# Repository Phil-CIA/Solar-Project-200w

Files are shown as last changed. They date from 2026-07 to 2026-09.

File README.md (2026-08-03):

# Solar Project 200W

Solar Project 200W is a prototype-first hardware and firmware effort for a 200W-class solar charging system built around a 4S LiFePO4 battery domain.

## What this repository is for

- Designing and validating a safe MPPT charger path
- Defining control, telemetry, and protection behavior
- Tracking design decisions, handoffs, and bring-up evidence

## Current Rev 0 focus

- Close MPPT schematic and routing readiness
- Maintain component continuity with in-stock substitutions
- Keep protection and validation gates explicit before bring-up

## System baseline

- PV class: 2x100W panel setup
- Battery class: 12.8V LiFePO4 (4S)
- Charge-path target: 15A minimum, 20A preferred growth path

## Project structure

- [docs/](docs/): requirements, architecture, decisions, test plans, phase reviews
- [hardware/](hardware/): KiCad files, MPPT notes, wiring maps, implementation checklists
- [firmware/](firmware/): firmware workspace and bring-up software notes

## Start here

1. [docs/requirements.md](docs/requirements.md)
2. [docs/architecture.md](docs/architecture.md)
3. [docs/decisions-log.md](docs/decisions-log.md)
4. [SOLAR_HANDOFF_2026-07-26.md](SOLAR_HANDOFF_2026-07-26.md)

## Simulation workflow

The PV switch gate-drive concept should be verified with SPICE as part of the normal review loop. The project-local LTspice assets are in [hardware/kicad/solar-project/spice](hardware/kicad/solar-project/spice), including the schematic draft [hardware/kicad/solar-project/spice/pv_switch_gate_drive.asc](hardware/kicad/solar-project/spice/pv_switch_gate_drive.asc) and the launcher [hardware/kicad/solar-project/spice/run_ltspice_pv_gate_drive.cmd](hardware/kicad/solar-project/spice/run_ltspice_pv_gate_drive.cmd).

A provisional LTspice integration harness is also present at [hardware/kicad/solar-project/spice/90_system_integration_harness_ltspice.cir](hardware/kicad/solar-project/spice/90_system_integration_harness_ltspice.cir). It is a simplified, staged model of the PV input, buck power stage, and battery boundary. The current run converged to about 13.64 V at the output node and 13.98 V at the battery bus at 4 ms, which is consistent with a basic charging path but still not hardware-validated.

The earlier validation showed that the current gate-drive arrangement does not provide a usable Vgs margin across the tested PV input range, so this should be treated as a design blocker until the gate-drive topology is revised.

## Safety notice

This project includes high-current DC power electronics and planned AC-domain integration.
Use staged, current-limited bring-up and treat all safety checks as mandatory gates.

## Session continuity

- [HANDOFF.md](HANDOFF.md)
- [NEXT_CHAT_PROMPT.md](NEXT_CHAT_PROMPT.md)

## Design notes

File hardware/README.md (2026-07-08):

# Hardware

Store hardware development assets here.

Suggested structure:
- `schematics/`
- `pcb/`
- `bom/`
- `manufacturing/`
- `validation/`

Add tool/version notes and board revision history as the project evolves.

## Phase 1 Kickoff Artifacts

- `mppt/block-diagram.md`
- `mppt/schematic-exploration-checklist.md`
- `mppt/interface-assumptions.md`
- `mppt/schematic-notes.md`
- `mppt/net-plan.md`
- `mppt/component-shortlist-template.md`
- `mppt/kicad-implementation-checklist.md`
- `mppt/envelope-decision-worksheet.md`
- `mppt/decision-update-template.md`
- `mppt/buck-topology-notes.md`
- `mppt/github-reference-notes.md`
- `mppt/buck-symbol-placement-checklist.md`
- `mppt/pv-input-stage.md`
- `mppt/pv-input-wiring-map.md`
- `mppt/buck-power-stage-wiring-map.md`
- `mppt/sheet2-component-picks.md`

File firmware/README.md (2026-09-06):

# Firmware

Store embedded source, build configuration, and flashing instructions here.

Suggested structure:
- `src/`
- `include/`
- `lib/`
- `scripts/`
- `docs/`

## Rev 0 Safe Bring-Up

- Source: [bringup/stm32g4_rev0_safe_bringup.c](bringup/stm32g4_rev0_safe_bringup.c)
- Bare-metal stage-1 source: [bringup/baremetal/stm32g4_rev0_stage1.c](bringup/baremetal/stm32g4_rev0_stage1.c)
- Bench procedure: [../docs/test/rev0-low-energy-comm-control-test.md](../docs/test/rev0-low-energy-comm-control-test.md)
- Target: recovered Rev 0 board fitted with an STM32G431/STM32G473-class UFQFPN-48 MCU.
- Framework: the active Rev 0 image is freestanding bare-metal firmware for the verified STM32G47x-class target. The separate HAL-oriented source remains a future integration reference.

The bare-metal stage-1 image avoids STM32Cube/HAL dependencies and can be built once GNU Arm Embedded Toolchain is installed:

```powershell
./firmware/bringup/baremetal/build.ps1
```

Stage 1 provides UART diagnostics, safe output state, fault input reads, open-drain software I2C, AHT20 measurements, SSD1306 output, and the D8 RGB heartbeat. Its automatic dashboard shows software wall time, reset-relative uptime, sensor data, and the cached LM51772 `STATUS_BYTE` with a read-failure count (`U6 xx Nnnn`). The U6 status poll is read-only and runs every two seconds while automatic I2C traffic is enabled. ADC remains a placeholder for a later calibrated acquisition pass.

## Rev 0 SWD-Only Checks

The scripts in [scripts/](scripts/) use xPack OpenOCD and ST-LINK to run volatile register checks without flashing firmware:

```powershell
./firmware/scripts/rev0-openocd-identify.ps1
./firmware/scripts/rev0-openocd-safe-idle.ps1
./firmware/scripts/rev0-openocd-i2c-gpio-check.ps1
./firmware/scripts/rev0-openocd-control-gpio-check.ps1
./firmware/scripts/rev0-openocd-run-probe.ps1
./firmware/scripts/windows-list-serial-usb.ps1
```

Run these only with PV, battery, charger output, inverter/AC wiring, and loads disconnected. Run them one at a time because they share the same ST-LINK/SWD target. The control GPIO check briefly toggles `PB5` and `PA5`; it does not pulse `PA8`.

After flashing the bare-metal stage-1 image, `rev0-openocd-run-probe.ps1` starts user flash from the programmed vector table, then reads the SRAM probe block at `0x20000000`. A first word of `0x53523030` and an increasing heartbeat word prove the firmware is executing even if the USB-UART bridge is not enumerating.

Rev 0 normal boot is repaired and verified: the startup vector uses a Thumb reset entry, and option bytes use `nSWBOOT0=0`, `nBOOT0=1` so floating PB8 is not sampled. Cold boot and S1 reset each passed 5/5. Rev 1 still requires a populated 10 kOhm BOOT0 pulldown and accessible test point. The repaired onboard CP2102 is verified on `COM5` at 115200 8N1.

Before any flash/upload, verify the programmer is attached to the expected recovered Rev 0 target and that the detected chip is the expected STM32G4 device. If the target does not match, stop instead of trying a different COM port or probe.

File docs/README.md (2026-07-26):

# Engineering Docs Guide

This folder is the working engineering record for Solar Project 200W.

## Read order for active work

1. [requirements.md](requirements.md)
2. [architecture.md](architecture.md)
3. [decisions-log.md](decisions-log.md)
4. [test/bringup-checklist.md](test/bringup-checklist.md)
5. [test/validation-plan.md](test/validation-plan.md)

## What to update during each session

- Decisions and tradeoffs: [decisions-log.md](decisions-log.md)
- Design state and open blockers: [../hardware/mppt/schematic-notes.md](../hardware/mppt/schematic-notes.md)
- Session continuity and next-step intent: latest handoff at repository root

## Hardware design trail

Use these when working MPPT implementation details:

- [../hardware/mppt/block-diagram.md](../hardware/mppt/block-diagram.md)
- [../hardware/mppt/net-plan.md](../hardware/mppt/net-plan.md)
- [../hardware/mppt/pv-input-wiring-map.md](../hardware/mppt/pv-input-wiring-map.md)
- [../hardware/mppt/buck-power-stage-wiring-map.md](../hardware/mppt/buck-power-stage-wiring-map.md)
- [../hardware/mppt/sheet4-sensing-control-wiring-map.md](../hardware/mppt/sheet4-sensing-control-wiring-map.md)
- [../hardware/mppt/kicad-implementation-checklist.md](../hardware/mppt/kicad-implementation-checklist.md)
- [../hardware/mppt/lm851772-lm51772-migration-checklist.md](../hardware/mppt/lm851772-lm51772-migration-checklist.md)

## Working rules

- Keep assumptions visible and dated.
- Mark unresolved items with owner and target date.
- Do not treat deferred ERC and power-authority findings as closed until explicitly waived.
- Preserve traceability between requirements, decisions, and validation evidence.

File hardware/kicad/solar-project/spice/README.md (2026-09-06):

# SPICE / LTspice workflow

This folder contains a small, project-local validation deck for the PV-input NMOS switch gate-drive network.

## Files
- pv_switch_gate_drive.cir - ngspice-compatible netlist used for operating-point checks
- pv_switch_gate_drive.asc - LTspice schematic draft for the same topology
- run_pv_gate_drive.py - helper to run a few VIN/VCTRL cases with ngspice
- summarize.py - helper to parse outputs and print a compact summary

## Recommended workflow
1. Open pv_switch_gate_drive.asc in LTspice and run the operating-point analysis.
2. Repeat for the relevant VIN and control states (12 V / 24 V / 36 V / 50 V, OFF versus ON).
3. Record the resulting Vgs margin in the design review notes.

## Current outcome
The earlier validation showed that the current gate-drive arrangement does not provide a usable Vgs margin across the tested VIN range. That result should be treated as a design blocker until the gate-drive topology is revised.

## Current harness baseline
The staged LTspice integration harness in [90_system_integration_harness_ltspice.cir](90_system_integration_harness_ltspice.cir) now produces a stable, charging-like baseline for the simplified B0/B1/B2 path. From the latest completed run, the model reported approximately 15.17 V at the output node, 12.46 V at the battery bus, and about 12 A of charge current at 4 ms in the simulator’s sign convention. This is suitable for concept-level sanity checking, but it is still not hardware-validated.

The latest block values were also aligned to the current KiCad schematic intent: B0 uses the PV fuse/TVS clamp path around F1, D1, and D2; B1 uses the selected 1uH power-stage inductor and a bulk output-capacitance branch with extra series-loss elements to reflect conduction and heating-related loss; and B2 uses a more conservative battery-side fuse and pack boundary model.

Compared with the project requirement target in [docs/requirements.md](docs/requirements.md), the current result lands near the expected 12 A to 13 A charging band for the 200W-class baseline and is therefore directionally consistent with the intended charger envelope. It is still a simplified model and should not be treated as a final design proof.

## Validation summary
The latest run gives a stable charging-like operating point at 4 ms with VOUT ≈ 15.17 V, BAT_BUS ≈ 12.46 V, and ICHG ≈ 12 A (negative sign in LTspice due to current direction convention). That corresponds to roughly $15.17 \times 12 \approx 182\ \text{W}$ of delivered charge power, which is still within the 180 W to 220 W design envelope in [docs/requirements.md](docs/requirements.md). The run remained stable across the leakage-corner sweep from 600 Ω to 1000 Ω, and the added hot-loss terms now pull the output and battery bus downward in a way that is more consistent with real power-stage losses. The result is still useful for checking topology and schematic mapping, but it should remain an engineering sanity check rather than a validated design value.

Design-review statement: the current LTspice harness supports the view that the proposed MPPT charger concept is feasible for the documented 200 W-class charging envelope, with the caveat that the model is still a simplified abstraction and requires later hardware validation.

## New modular schematic-to-SPICE flow

The full schematic partition for block-based SPICE modeling is documented in `SCHEMATIC_SPICE_PARTITION.md`.

Starter block decks were added:

- `00_block_b0_pv_input.cir`
- `01_block_b1_power_stage.cir`
- `02_block_b2_battery_boundary.cir`
- `03_block_b3_control_rail.cir`
- `04_block_b4_fault_network.cir`
- `05_block_b5_measurement_frontend.cir`
- `90_system_integration_harness.cir`

Recommended sequence:

1. Make each block deck runnable on its own.
2. Replace placeholders with real values/models from the KiCad schematic.
3. Integrate blocks progressively in `90_system_integration_harness.cir`.

## Automated corner runs

Use the PowerShell runner to execute key decks and produce a compact CSV summary:

- Script: `run_spice_corner_sweeps.ps1`
- Summary output: `corner_summary.csv`
- Per-deck logs: `logs/*.log`
- Waveform CSV exports: `waveforms/*.csv`
- Plot dashboard: `plots/index.html`

Summary columns now include:

- `status` pass/fail classification from simulator/log health checks
- `vout_avg`, `iin_avg` from direct deck measurements when available
- `iout_avg`, `pin_avg`, `pout_avg`, `eff_pct` for B1, derived from measured values and deck params when needed
- `req_chg_001`, `req_chg_003` requirement-oriented status fields for B1:
	- `req_chg_001`: pass/fail against 15A minimum target
	- `req_chg_003`: pass/fail against 12A to 13A expected baseline band
- `bat_trip`, `ocp_trip` from B4 threshold sweeps
- `notes` with per-deck log path and optional warnings

Current warning tags appended in `notes`:

- `iin_avg_negative`: B1 input current sign is negative in this operating convention
- `pin_avg<=0`, `pout_avg<=0`: non-physical average power direction/magnitude
- `eff_pct_out_of_range`: computed efficiency is outside 0 to 100%
- `measure_failed`: ngspice reported one or more measurement failures in the deck log

Example from this folder:

```powershell
powershell -ExecutionPolicy Bypass -File .\run_spice_corner_sweeps.ps1
```

Run with warning gate enabled (nonzero exit if selected warnings are present):

```powershell
powershell -ExecutionPolicy Bypass -File .\run_spice_corner_sweeps.ps1 -FailOnWarnings $true
```

Generate plots only from existing waveform CSV files:

```powershell
powershell -ExecutionPolicy Bypass -File .\generate_spice_plots.ps1
```

Current runner deck set:

- `00_block_b0_pv_input.cir`
- `01_block_b1_power_stage.cir`
- `02_block_b2_battery_boundary.cir`
- `04_block_b4_fault_network.cir`
- `90_system_integration_harness.cir`

`04_block_b4_fault_network.cir` now reports measured threshold points as `BAT_TRIP` and `OCP_TRIP` in the run log, and the runner parses those into the summary CSV when available.

## Startup-current experiment

`03_startup_current_limit.cir` is a separate behavioral transient deck for the Rev 0 bring-up question: can a nominal 6 V source with an approximately 200 mA current ceiling build current in the 1 uH inductor during a soft-start duty ramp? It uses a 610 kHz switching period, a configurable soft-start interval, the 1 kOhm preload, and a 30 ohm source resistance as a first-order approximation of the bench supply current limit.

This deck is not an LM51772 vendor model and does not prove the controller's exact soft-start or current-limit behavior. Its useful outputs are `IIN_PEAK`, `IIN_AVG`, `IL_PEAK`, `IL_AVG`, and `VOUT_FINAL`. Vary `TSS`, `DUTY_END`, `LVAL`, and `RSOURCE` one at a time when comparing the model to the bench capture.

Run it from this directory with:

```powershell
ngspice -b -o logs/03_startup_current_limit.log 03_startup_current_limit.cir
```

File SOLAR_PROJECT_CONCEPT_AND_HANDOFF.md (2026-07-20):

# Solar Learning Project — Concept Capture + Handoff (Rev 0)

## Session Update - 2026-07-06

Completed since initial concept capture:

1. New repository initialized and pushed:
  - `https://github.com/Phil-CIA/Solar-Project-200w`
2. Base project scaffold created:
  - `README.md`
  - `.gitignore`
  - `docs/README.md`
  - `hardware/README.md`
  - `firmware/README.md`
3. Active KiCad project imported from the historical source at:
  - `C:/Users/forch/GitHub/Solar Project`
4. Current authoritative KiCad source location in this repo:
  - `hardware/kicad/solar-project/`
  - `hardware/kicad/solar-project/Solar Project.kicad_pro`
  - `hardware/kicad/solar-project/Solar Project.kicad_sch`
  - `hardware/kicad/solar-project/Solar Project.kicad_pcb`
5. To open the live schematic in KiCad, use:
  - `hardware/kicad/solar-project/Solar Project.kicad_sch`
5. Transient KiCad artifacts were intentionally excluded from source control.

Current continuation focus:
- Keep the KiCad work anchored to the repository copy above.
- Continue the schematic validation pass and refresh docs only when the exported state changes.
- Use the next few sessions to decide which legacy single-MOSFET-era functions still belong in hardware, which ones are firmware-only, and which ones can be removed now that LM51772 is the active controller path.

## Cleanup Plan For The Next Few Sessions

### Session 1 - Function Inventory And Ownership

Goal:
- Make a complete list of the leftover control, enable, fault, and legacy hold nets around U2/U6/Q2.

Questions to answer:
- Does the function still need to exist?
- If yes, is the right owner hardware, firmware, or both?
- If firmware is involved, is it just supervision/telemetry, or does it need to make a safety decision?

Decision rule:
- Hardware owns anything that must still work safely when the MCU is not running.
- Firmware owns only coordination, reporting, and non-safety policy.
- Remove any net or block that only existed to support the earlier single-MOSFET concept and no longer contributes to the LM51772 architecture.

### Session 2 - Schematic Cleanup

Goal:
- Remove or repurpose the nets that were only there for the older control concept.

Expected outcomes:
- Keep `CTRL_PWM_MAIN` and `CTRL_EN_CHG` if the MCU still needs to command the controller.
- Keep `FAULT_OCP` and `FAULT_OVP` as hardware-first safety indications, then mirror them in firmware only for logging or graceful shutdown.
- Remove or freeze any legacy `V_in_ON` / Q2-style path if it no longer has a real job.
- Finish the U6 helper-net cleanup only if those nets still represent real hardware needs.

### Session 3 - Verification And Simplification

Goal:
- Re-run ERC, compare the exported netlist against the intended function list, and delete any remaining scaffolding that does not support the current architecture.

Exit criteria:
- Every remaining net has a clear owner.
- No net exists solely because it was part of the old single-MOSFET concept.
- The docs say explicitly whether the function lives in hardware, firmware, or not at all.

### Session 4 - Sheet 2 And Legacy Output Cleanup

Goal:
- Clean the power-stage side first, because it is the simplest place to separate active function from old scaffolding.

Targets:
- Confirm `CTRL_PWM_MAIN` is the only needed drive input for the buck stage.
- Keep the async first-pass path in Sheet 2 and avoid reintroducing the old Q2-style control gate path.
- Remove any stale labels that only existed to support the earlier MOSFET-only control idea.

Expected result:
- Sheet 2 reflects the modern LM51772-driven control path without leftover naming from the first concept pass.

### Session 5 - Control And Fault Path Cleanup

Goal:
- Decide what the MCU actually owns versus what the hardware must enforce by itself.

Targets:
- Keep `CTRL_EN_CHG` if the MCU still needs an enable line.
- Keep `FAULT_OCP` and `FAULT_OVP` as hardware signals, then mirror them in firmware only if useful.
- Review `V_in_ON` and the `U2/Q2` legacy branch and either retire it or explicitly document why it stays.

Expected result:
- The control/fault sheet reads like a modern supervisor interface, not a half-retained legacy gate hack.

### Session 6 - U6 Helper Nets And Final ERC Pass

Goal:
- Finish the LM51772 helper nets only if they still support the selected architecture.

Targets:
- Close `U6_VCC2` and `U6_FLT` with real passives if U6 remains active.
- Keep `U6_SYNC`, `U6_DTRK`, and `U6_RST` only if they are still intentional straps.
- Re-run ERC/netlist export and compare the result against the classified backlog.

Expected result:
- Any net that survived this pass has a real hardware reason to exist.
- Any net that does not have a reason is removed rather than preserved out of habit.

### First-Pass Function Classification

Use this as the working backlog for the next sessions. The final answer can change, but each item needs an owner decision.

| Item | Current best guess | Why |
|---|---|---|
| `CTRL_PWM_MAIN` | Hardware stays, firmware drives it | The MCU should still command the converter, but the PWM signal itself is a hardware interface. |
| `CTRL_EN_CHG` | Hardware stays, firmware drives it | Enable/disable needs to exist in the schematic; firmware may assert it. |
| `FAULT_OCP` | Hardware stays, firmware monitors it | Over-current must remain a real protection signal even if firmware also logs or reacts to it. |
| `FAULT_OVP` | Hardware stays, firmware monitors it | Same logic as OCP: keep the hardware fault path, let firmware supervise the result. |
| `V_in_ON` | Likely delete or retire | It still belongs to the legacy Q2 gate path and only stays if that path is intentionally retained. |
| `U2` as control-rail owner | Delete or deprecate | Current docs already select U4 as the live `CTRL_3V3` owner. |
| `U6_VCC2` | Hardware stays if U6 stays | Needs a real decoupling path if the LM51772 gate-driver rail remains active. |
| `U6_FLT` | Hardware stays if U6 stays | Fault output needs a pull-up and a destination pin; firmware can only observe it after hardware exists. |
| `U6_RST` | Hardware stays if used | Reset is a real pin-level strap or control input, not a firmware-only concept. |
| `U6_SYNC` | Hardware stays if used | Sync/strap behavior is a physical configuration choice. |
| `U6_DTRK` | Hardware stays if used | Dynamic tracking is a physical pin-level mode decision. |

### Session Sequence By Owner Type

1. Hardware-only cleanup session:
- Finish `U6_VCC2`, `U6_FLT`, and any strap nets that still need real passives.
- Remove obsolete U2 owner wiring if it is no longer part of the chosen control tree.
- Delete `V_in_ON` if the Q2 legacy control path is not intentionally kept.

2. Firmware interface session:
- Map `CTRL_PWM_MAIN`, `CTRL_EN_CHG`, `FAULT_OCP`, and `FAULT_OVP` to the MCU behavior that should remain.
- Decide whether firmware only logs faults or also performs controlled shutdown / restart policy.
- Keep the firmware model as a supervisor, not the safety owner, unless a specific hardware path is missing and documented.

3. Final simplification session:
- Remove any leftover symbols, labels, or note text that only describe the old single-MOSFET concept.
- Re-run ERC and compare the live schematic against this table.
- Update decisions log only for items that truly changed ownership or function.

## 1) Project Intent
This project is a **learning-first** build, not a cost-optimization build.  
Goal: understand and eventually design at PCB level:

1. Solar power capture (panel behavior, Vmp/Voc/Imp/Isc)
2. MPPT charging into LiFePO4 battery
3. DC energy storage/distribution
4. DC-to-AC inversion for common loads
5. System telemetry, protection, and safe bring-up

---

## 2) Selected System Concept (Current Baseline)
- Solar array: **200W total** (2 × 100W panels)
- Battery: **12.8V 40Ah LiFePO4** (4S)
- Charger path target: **15A minimum, 20A preferred**
- Inverter target: **300W pure sine**

This is the current concept baseline for initial architecture and documentation.

---

## 3) Key Learning Definitions Captured
- **Vmp (Vmpp):** voltage at maximum power point
- **Imp (Impp):** current at maximum power point
- **Voc:** open-circuit panel voltage
- **Isc:** short-circuit panel current
- **MPPT:** Maximum Power Point Tracking (operate panel near max power point as conditions change)

---

## 4) High-Level Architecture
1. PV input stage (protection + filtering)
2. MPPT charger stage (buck or buck-boost path)
3. Battery stage (LiFePO4 + BMS + fuse/disconnect)
4. DC distribution stage
5. Inverter stage (12V DC to 120VAC pure sine)
6. Monitoring/telemetry/control stage

---

## 5) Sizing Notes Captured
### Charge current from solar estimate
Use:
- I_charge ≈ (P_solar × efficiency) / V_charge
- For 4S LiFePO4, practical shortcut: **I_charge ≈ P_solar × 0.063**

For 200W:
- I_charge ≈ 12–13A expected peak
- Therefore charger should be **15A+** (20A preferred for margin/growth)

### Controller class implication
- 5A-class charger is too limiting for 200W
- 15A–20A-class charger aligns with chosen system

---

## 6) Safety & Design Priorities
- Fuse near battery positive terminal
- Branch fusing for subsystems
- Proper wire gauge for expected current
- UVLO/OVP/OCP/OTP protections
- Reverse polarity and transient protection on PV input
- Treat inverter output as hazardous mains-level AC
- Use staged bring-up and current-limited bench testing

---

## 7) Scope Strategy (One Piece at a Time)
### Phase A (current focus)
- Concept documentation
- Project structure setup
- MPPT charger design exploration (block level first)

### Phase B
- MPPT schematic development
- Simulation/math validation
- Firmware architecture for charge control + telemetry

### Phase C
- Inverter design exploration and implementation

---

## 8) Open Design Decisions (To Resolve in Next Sessions)
1. MPPT topology final: buck vs buck-boost
2. Controller approach:
   - analog power controller + MCU supervision
   - or highly integrated digital charger controller
3. Panel wiring strategy for final build: parallel vs series
4. Telemetry stack:
   - local display only
   - serial logging
   - CAN/UART/BLE/Wi-Fi extension
5. Battery current limits from selected BMS/cell data sheet

---

## 9) Deliverables Requested for Next Chat (VS Code Agent)
1. Create project folder structure (docs, calculations, hardware, firmware, test)
2. Create starter markdown docs/templates
3. Add engineering checklist files for:
   - requirements
   - design decisions
   - safety
   - bring-up/testing
4. Add initial calculator placeholders (markdown or scripts) for:
   - solar-to-charge current
   - fuse sizing worksheet
   - inverter input current estimation

---

## 10) Initial Folder Structure Target
```text
solar-learning-project/
  README.md
  docs/
    concept/
      system-overview.md
      requirements.md
      assumptions.md
      decisions-log.md
    handoff/
      next-chat-handoff.md
    safety/
      hazard-analysis.md
      protection-checklist.md
    test/
      bringup-checklist.md
      validation-plan.md
  calculations/
    charger/
      charge-current-sizing.md
      mppt-sizing-notes.md
    inverter/
      dc-input-current-sizing.md
  hardware/
    mppt/
      block-diagram.md
      schematic-notes.md
      bom-placeholder.csv
    inverter/
      block-diagram.md
      schematic-notes.md
      bom-placeholder.csv
  firmware/
    mppt/
      state-machine.md
      telemetry-signals.md
    inverter/
      control-architecture.md
  project-management/
    roadmap.md
    milestones.md
```

---

## 11) Definition of Done for “Project Setup” Task
- Folder tree created
- All listed starter docs created with section headers
- README links to major docs
- Handoff doc for next technical session completed
- No hardware commits yet; documentation scaffold only

---

## 12) Notes
This is a concept-building phase.  
Proceed incrementally, prioritizing understanding, safety, and reproducible documentation.

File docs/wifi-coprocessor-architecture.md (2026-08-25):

# Wi-Fi Coprocessor Architecture

Last updated: 2026-08-08  
Status: Accepted Rev 1 baseline  
Decision: DEC-015

## System Boundary

The STM32 is the charge-controller and safety owner. The ESP32-C3 development module is a network coprocessor. A Wi-Fi outage, ESP32 reset, or communications failure must not interrupt safe charger operation.

### STM32 Owns

- MPPT and charge-state control
- PWM and power-stage enable control
- Measurements, limits, and fault handling
- Fan, buttons, display, and local operation
- Validation and execution of all remote requests

### ESP32 Owns

- Wi-Fi provisioning and reconnection
- Credential storage in ESP32 NVS
- Network time synchronization
- MQTT or HTTPS connectivity
- Telemetry publication and remote-request forwarding
- OTA updates for ESP32 firmware

STM32 firmware updates remain through SWD for the initial implementation. ESP32-assisted STM32 updates are deferred until the communications protocol is proven.

## Hardware Interface

- Power the ESP32 development module through its `5V` pin from `CTRL_5V`.
- Leave the module's exposed `3.3V` pin unpowered; the module uses its onboard regulator.
- Use common `PWR_NEG` reference.
- Use UART `TXD_ESP` and `RXD_ESP` for the data channel.
- Keep `RTS_ESP` and `CTS_ESP` routed as optional hardware flow control.
- Initial UART rate: 115200 baud; raise only after validation.
- Preserve the module antenna keepout in PCB placement and copper pours.

## UART Protocol Baseline

Use binary, versioned, framed messages rather than an unframed text stream:

`COBS(version | message_type | sequence | payload_length | payload | CRC16)`

Initial message set:

- `PROTOCOL_INFO`: protocol and firmware versions
- `HEARTBEAT`: link health
- `STATUS`: controller state, active faults, and uptime
- `TELEMETRY`: PV, battery, power, and temperature values
- `GET_CONFIG`: read approved controller settings
- `SET_CONFIG`: request approved setting changes
- `COMMAND`: request start, stop, or permitted fault clear

The STM32 validates every setting and command against local safety limits. Missing ESP32 heartbeats do not change charger operation. Missing STM32 heartbeats cause the ESP32 to report the controller offline.

## Wi-Fi and Remote Access

1. On first boot or explicit credential reset, the ESP32 starts a temporary setup access point.
2. A local setup page collects the network SSID and password.
3. Credentials are stored in ESP32 NVS.
4. The setup access point is disabled during normal operation.
5. Telemetry is published periodically; faults are published immediately.
6. Remote control requires authenticated, encrypted transport before it is enabled.

MQTT is the preferred first remote telemetry transport. Topic naming, payload schema, authentication, and broker selection remain firmware-session tasks.

## Failure Rules

- Charger safety does not depend on the ESP32 or network.
- ESP32 commands are requests, not direct actuator control.
- Invalid, stale, duplicate, or out-of-range requests are rejected by the STM32.
- Protocol versions are exchanged before commands are accepted.
- ESP32 reset and update activity must not toggle charge-control nets.

## Deferred Details

- MQTT broker and topic hierarchy
- Telemetry sampling and publication rates
- Authentication and certificate provisioning
- Whether RTS/CTS is enabled after initial UART testing
- Host-controlled ESP32 reset or boot-mode control
- STM32 firmware delivery through the ESP32

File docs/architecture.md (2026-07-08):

# Solar Project 200W - Architecture

Last updated: 2026-07-06
Scope: Phase 0 block-level architecture for planning and traceability.
Related documents: [requirements.md](requirements.md), [decisions-log.md](decisions-log.md)

## 1. Architecture Intent

Define subsystem boundaries and interfaces early so requirement allocation, safety controls, and deferred decisions remain explicit while implementation stays agile.

## 2. Block-Level System View

1. PV input stage
2. MPPT charger stage
3. Battery and protection stage
4. DC distribution stage
5. Inverter stage
6. Monitoring/telemetry/control stage

Power path overview:
- PV source -> PV protection/filtering -> MPPT charger -> battery bus -> DC distribution -> inverter/load path.

Control and telemetry overview:
- Sensing at PV, charger, battery, and thermal nodes.
- Local serial telemetry baseline for bring-up (DEC-006).
- Optional extended telemetry deferred.

## 3. Subsystem Boundaries and Responsibilities

### 3.1 PV Input Stage

Responsibilities:
- Accept 200W-class PV source and condition entry to charger stage.
- Provide reverse polarity and transient protection at boundary.

Boundary assumptions:
- Final panel wiring strategy (series vs parallel) is deferred (DEC-004).
- Input voltage/current envelope will be finalized when panel model is locked.

Requirement mapping:
- REQ-PV-001, REQ-PV-002, REQ-SAF-004.

### 3.2 MPPT Charger Stage

Responsibilities:
- Convert PV input to battery charging profile with MPPT behavior.
- Support 15A minimum charge capability; 20A class preferred where practical.

Boundary assumptions:
- Topology decision (buck vs buck-boost) deferred (DEC-003).
- Controller partition (analog + MCU vs integrated controller) deferred (DEC-005).

Requirement mapping:
- REQ-CHG-001, REQ-CHG-002, REQ-CHG-003, REQ-SAF-003.

### 3.3 Battery and Protection Stage

Responsibilities:
- Host 12.8V LiFePO4 storage domain with BMS-constrained operating envelope.
- Provide primary battery fuse near battery positive terminal.

Boundary assumptions:
- Continuous/peak BMS limits pending closure of Q-001.

Requirement mapping:
- REQ-BAT-001, REQ-BAT-002, REQ-SAF-001.

### 3.4 DC Distribution Stage

Responsibilities:
- Route battery-domain power to charger auxiliaries, control domain, and inverter input.
- Apply branch protection strategy for major current paths.

Boundary assumptions:
- Final branch current ratings depend on BMS limits and inverter transients.

Requirement mapping:
- REQ-SAF-002, REQ-SAF-003.

### 3.5 Inverter Stage

Responsibilities:
- Convert battery-domain DC to 120VAC pure sine output in 300W-class envelope.
- Define AC hazard boundary and integration controls.

Boundary assumptions:
- Inverter internal topology is outside Phase 0 and will be detailed in later phases.

Requirement mapping:
- REQ-INV-001, REQ-INV-002, REQ-SAF-005.

### 3.6 Monitoring, Telemetry, and Control Stage

Responsibilities:
- Measure key electrical and thermal signals for safe control and diagnostics.
- Provide local serial logging baseline for bring-up.

Boundary assumptions:
- Extended telemetry interfaces are deferred and non-blocking for initial bring-up.

Requirement mapping:
- REQ-TEL-001, REQ-TEL-002, REQ-TEL-003, REQ-SAF-006.

## 4. Protection Strategy Outline

Minimum strategy for Phase 0 architecture allocation:
- Battery entry protection: main fuse close to battery positive.
- Path protection: branch fusing for charger and inverter paths.
- Electrical protections: UVLO, OVP, OCP, OTP assigned to charger/control stack.
- PV front-end: reverse polarity and transient mitigation.
- AC boundary discipline: hazardous domain handling and test controls for inverter output.

## 5. Power and Signal Interface Summary

| Interface | Domain | Direction | Key Signals / Constraints | Notes |
|---|---|---|---|---|
| IF-PV-CHG-01 | PV -> Charger | Power | PV voltage/current envelope, transient behavior | Depends on DEC-004 |
| IF-CHG-BAT-01 | Charger -> Battery | Power | Charge current capability, charge profile limits | Depends on DEC-003/DEC-005 |
| IF-BAT-DIST-01 | Battery -> Distribution | Power | Main fuse boundary, branch protection | Depends on Q-001 |
| IF-DIST-INV-01 | Distribution -> Inverter | Power | High current DC feed, startup current behavior | Inverter phase detail later |
| IF-SENSE-CTRL-01 | Plant -> Control | Telemetry | PV V/I, battery V/I, thermal channels | Baseline for REQ-TEL-002 |
| IF-CTRL-LOG-01 | Control -> Host | Telemetry | Local serial logs for bring-up and diagnostics | Defined by DEC-006 |

## 6. Deferred Architectural Decisions

- DEC-003: MPPT topology final selection.
- DEC-004: Panel wiring strategy final selection.
- DEC-005: Charger control partition final selection.
- Q-001: Confirm BMS current envelope.
- Q-002: Confirm instrumentation capability for validation depth.

## 7. Phase 0 Architecture Exit Criteria

- All major subsystem boundaries are documented with responsibilities.
- Requirement mappings are established at subsystem level.
- Safety and protection controls are allocated at planning level.
- Deferred decisions are explicit and linked to owners/target dates in decisions log.

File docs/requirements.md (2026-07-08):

# Solar Project 200W - Requirements

Last updated: 2026-07-06
Scope: Phase 0 planning baseline for 200W-class learning system.
Traceability: Link each requirement to architecture sections and decisions in [decisions-log.md](decisions-log.md).

## 1. Requirement Method

Each requirement includes:
- ID: stable reference for design and test traceability.
- Metric and target: measurable engineering expectation.
- Verification: planned pass/fail method.
- Source: concept baseline or decision reference.

## 2. System Baseline

- PV input class: 200W nominal array (2x100W modules).
- Battery class: 12.8V LiFePO4 (4S), 40Ah nominal.
- Charge path target: 15A minimum, 20A preferred capability class.
- Inverter envelope: 300W pure sine target.

## 3. Electrical Requirements

| ID | Requirement | Target / Limit | Verification Method | Source |
|---|---|---|---|---|
| REQ-PV-001 | System shall support a PV nameplate power class of 200W. | 180W to 220W accepted design envelope. | Nameplate review + input power budget check. | Concept baseline |
| REQ-PV-002 | PV operating window shall include module maximum power region during normal conditions. | PV MPP tracking region shall be documented and covered by charger input range. | Architecture and charger input-range review against selected panel datasheets. | Concept + DEC-003/DEC-004 |
| REQ-CHG-001 | Charger architecture shall target 15A minimum continuous charge capability. | >=15A continuous design target at rated thermal conditions. | Schematic current-path review + component derating worksheet. | Concept baseline |
| REQ-CHG-002 | Charger solution should preserve growth margin toward 20A class when feasible. | 20A preferred target documented as stretch objective. | Design review note with constraints and tradeoffs. | Concept baseline |
| REQ-CHG-003 | Estimated peak solar charge current expectation shall be documented. | For 200W baseline, expected peak approximately 12A to 13A. | Calculation using I_charge ~= (P_solar * eta) / V_charge with assumptions recorded. | Concept sizing note |
| REQ-BAT-001 | Battery nominal chemistry and stack shall remain LiFePO4 4S for Phase 0/1 planning. | 12.8V nominal, 40Ah class. | BOM and requirements consistency check. | Concept baseline |
| REQ-BAT-002 | Battery charge/discharge operational limits shall be constrained by selected BMS datasheet. | Continuous and peak current limits explicitly captured before hardware lock. | Datasheet extraction checklist (open item closure). | Decisions Q-001 |
| REQ-INV-001 | Inverter power envelope shall target 300W continuous output class. | 300W continuous target at defined ambient and cooling assumptions. | Architecture power budget and thermal assumption review. | Concept baseline |
| REQ-INV-002 | Inverter input current expectation shall be documented for 300W target operation. | I_in estimate and design margin documented at battery voltage range. | Calculation worksheet with efficiency assumption. | Concept baseline |

## 4. Telemetry and Control Requirements

| ID | Requirement | Target / Limit | Verification Method | Source |
|---|---|---|---|---|
| REQ-TEL-001 | Initial telemetry baseline shall support local serial logging for bring-up. | UART/serial logging path defined for charger and battery observability. | Architecture interface review + firmware signal list placeholder. | DEC-006 |
| REQ-TEL-002 | Core electrical observability shall include panel, battery, and thermal signals. | At minimum: PV voltage/current, battery voltage/current, key temperature points. | Signal map review against architecture boundary definitions. | Concept + DEC-007 |
| REQ-TEL-003 | Telemetry extension shall be designed as optional and non-blocking for first bring-up. | Wireless or extended interfaces deferred without blocking core path. | Decisions-log review of deferred scope. | DEC-006 |

## 5. Safety and Protection Requirements

| ID | Requirement | Target / Limit | Verification Method | Source |
|---|---|---|---|---|
| REQ-SAF-001 | Main battery positive protection shall include a fuse located near battery terminal. | Fuse placement documented at battery positive entry point. | Architecture placement review. | Concept safety priorities |
| REQ-SAF-002 | Subsystem branch protection shall be included for major load paths. | Branch fusing strategy documented for charger and inverter paths. | Protection strategy checklist review. | Concept safety priorities |
| REQ-SAF-003 | Charger and distribution design shall include UVLO/OVP/OCP/OTP coverage. | Protection functions explicitly allocated to circuits or controller features. | Protection allocation table review. | Concept + DEC-007 |
| REQ-SAF-004 | PV input path shall include reverse polarity and transient protection strategy. | Reverse polarity and surge/transient mitigation documented at PV boundary. | Interface/protection schematic review (planning-level in Phase 0). | Concept + DEC-007 |
| REQ-SAF-005 | AC inverter output shall be treated as hazardous mains-level domain. | Isolation, enclosure, and handling warnings documented before integration testing. | Safety checklist review prior to integration phase. | Concept safety priorities |
| REQ-SAF-006 | Bring-up shall be staged with current-limited progression and logged checkpoints. | Stepwise current progression and stop criteria defined before hardware bring-up. | Bring-up procedure review against decisions log. | DEC-008 |

## 6. Validation Gate Requirements

| ID | Requirement | Target / Limit | Verification Method | Source |
|---|---|---|---|---|
| REQ-VAL-001 | Every requirement shall map to a planned verification activity. | No requirement left without a verification method. | Traceability matrix review. | Planning policy |
| REQ-VAL-002 | Deferred decisions affecting requirements shall include owner and target date. | 100% of deferred, requirement-impacting decisions have owner/date. | Decisions-log audit. | DEC-001 policy |
| REQ-VAL-003 | Phase transition to implementation shall require requirements and architecture review pass. | Review checklist completed with no unresolved safety blockers. | Phase gate checklist sign-off (Phil + Copilot). | DEC-002 |

## 7. Open Items Blocking Requirement Closure

- Confirm battery/BMS continuous and peak current limits (Q-001).
- Confirm available test instrumentation capability (Q-002).
- Finalize PV wiring strategy and MPPT topology coupling (DEC-003, DEC-004).

## 8. Definition of Done (Phase 0 Requirements)

- Requirement IDs are stable and uniquely named.
- Every requirement includes measurable target/limit and verification method.
- Safety-critical controls are represented in explicit requirements.
- Open blockers are listed with decision-log references and target dates.

## 9. Compact Traceability Matrix

| Requirement ID | Architecture Boundary / Interface | Decision / Open Item Link |
|---|---|---|
| REQ-PV-001 | 3.1 PV Input Stage | DEC-004 |
| REQ-PV-002 | 3.1 PV Input Stage, IF-PV-CHG-01 | DEC-003, DEC-004 |
| REQ-CHG-001 | 3.2 MPPT Charger Stage, IF-CHG-BAT-01 | DEC-003 |
| REQ-CHG-002 | 3.2 MPPT Charger Stage, IF-CHG-BAT-01 | DEC-003, DEC-005 |
| REQ-CHG-003 | 3.2 MPPT Charger Stage | DEC-003 |
| REQ-BAT-001 | 3.3 Battery and Protection Stage, IF-BAT-DIST-01 | Q-001 |
| REQ-BAT-002 | 3.3 Battery and Protection Stage, IF-BAT-DIST-01 | Q-001 |
| REQ-INV-001 | 3.5 Inverter Stage, IF-DIST-INV-01 | DEC-002 |
| REQ-INV-002 | 3.5 Inverter Stage, IF-DIST-INV-01 | Q-001 |
| REQ-TEL-001 | 3.6 Monitoring/Telemetry/Control, IF-CTRL-LOG-01 | DEC-006 |
| REQ-TEL-002 | 3.6 Monitoring/Telemetry/Control, IF-SENSE-CTRL-01 | DEC-007 |
| REQ-TEL-003 | 3.6 Monitoring/Telemetry/Control | DEC-006 |
| REQ-SAF-001 | 3.3 Battery and Protection Stage | DEC-007 |
| REQ-SAF-002 | 3.4 DC Distribution Stage | DEC-007 |
| REQ-SAF-003 | 3.2 MPPT Charger Stage, 3.4 DC Distribution Stage | DEC-007 |
| REQ-SAF-004 | 3.1 PV Input Stage | DEC-007 |
| REQ-SAF-005 | 3.5 Inverter Stage | DEC-007 |
| REQ-SAF-006 | 3.6 Monitoring/Telemetry/Control | DEC-008 |
| REQ-VAL-001 | 7. Phase 0 Architecture Exit Criteria | DEC-001 |
| REQ-VAL-002 | 6. Deferred Architectural Decisions | DEC-001 |
| REQ-VAL-003 | 7. Phase 0 Architecture Exit Criteria | DEC-002 |

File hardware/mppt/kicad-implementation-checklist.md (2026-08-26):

# MPPT KiCad Implementation Checklist

Last updated: 2026-08-26
Owners: Phil + Copilot
Purpose: provide a repeatable sequence for building the first MPPT schematic safely and traceably.

## 1. Session Start Gate

- [ ] Open and review hardware/mppt/block-diagram.md.
- [ ] Open and review hardware/mppt/schematic-notes.md.
- [ ] Open and review hardware/mppt/buck-schematic-parts.md.
- [ ] Open and review hardware/mppt/net-plan.md.
- [ ] Open and review hardware/mppt/stm32-support-implementation-checklist.md.
- [ ] Open and review docs/session-plan-2026-07-20.md.
- [ ] Confirm current temporary bounds and open items in docs/phase-1-kickoff.md.
- [ ] Confirm decision status for DEC-003 and DEC-005 in docs/decisions-log.md.

## 2. Draw Order (Per Session)

1. Draw PV boundary and protection blocks first.
2. Draw MPPT conversion core and output boundary second.
3. Draw battery interface and fuse handoff notes third.
4. Draw sensing and telemetry I/O paths last.

Rule:
- Do not start symbol-level optimization before all four areas are present at block connectivity level.

## 3. Annotation Pass

- [ ] Add ASSUME notes for temporary bounds.
- [ ] Add DECISION notes for unresolved decisions (DEC-003, DEC-005).
- [ ] Add SAFETY notes at PV protection, conversion protection, and battery handoff boundaries.
- [ ] Add VERIFY notes for each measurement-critical node.

## 4. Net Naming Pass

- [ ] Apply power net names from net-plan.md.
- [ ] Apply sensing and control net names from net-plan.md.
- [ ] Verify no duplicate or ambiguous names on critical nets.
- [ ] If a new net is introduced, add it to net-plan.md the same session.

## 5. Verification Pass Before Save

- [ ] Each high-current path has explicit forward and return path.
- [ ] UVLO/OVP/OCP/OTP ownership is represented in notes or blocks.
- [ ] PV reverse polarity and transient handling are present.
- [ ] Buck-specific parts are represented: switch, freewheel path, inductor, output capacitors, control placeholder.
- [ ] Required sense points exist: PV V/I, BAT V/I, thermal points.
- [ ] Serial logging boundary exists for bring-up telemetry.
- [ ] Control-power boundary is explicit (`CTRL_SUPPLY_IN`, `CTRL_3V3`, optional `CTRL_3V3A`) and tied to DEC-013 intent.
- [ ] USB bench fallback path is protected against reverse current when runtime rail is active.
- [ ] Any intentionally unused pins touched in this pass are marked with explicit `no_connect` markers.
- [ ] New active rails introduced in this pass include explicit power authority markers (power flag or clear power-output ownership).

## 5.1 ERC Triage Rule During Implementation

- [ ] Fix high-value ERC findings immediately: `multiple_net_names`, unconnected wire endpoints in active zones, and missing ownership on fault/control nets.
- [ ] Defer low-value cleanup findings (footprint library noise, placeholder warnings) to end-of-phase cleanup unless they hide functional risk.
- [ ] Record deferred ERC items with rationale in `hardware/mppt/schematic-notes.md`.

## 6. Save-Point Protocol

At each save-point:
- [ ] Add a short note in hardware/mppt/schematic-notes.md describing what changed.
- [ ] If assumptions changed, update hardware/mppt/interface-assumptions.md.
- [ ] If trade-offs were made, add a dated entry or update in docs/decisions-log.md.

## 7. End-of-Session Exit Gate

- [ ] Unresolved blockers are listed with owner and next target date.
- [ ] Current schematic state is compatible with REQ-CHG-001/002/003 and REQ-SAF-003/004 intent.
- [ ] No hidden safety-critical assumptions remain unannotated.
- [ ] Next session first action is captured at bottom of this file.

## 7.1 STM32 Support Components Gate

Close this gate before board-placement freeze:

- [ ] External reset path is complete: `MCU_RST_N` pull-up, reset switch to `PWR_NEG`, and header/debug access retained.
- [ ] External HSE crystal path is complete: crystal on `MCU_HSE_IN`/`MCU_HSE_OUT` with two load capacitors to `PWR_NEG` placed close to MCU.
- [ ] SWD bring-up access is complete and labeled (`PA13`, `PA14`, reset).
- [ ] BOOT path behavior is explicitly documented (`PB8-BOOT0` default state and recovery method).
- [ ] Navigation pad is complete and documented: `BTN_UP_N`, `BTN_DN_N`, `BTN_LT_N`, `BTN_RT_N`, `BTN_ENT_N`.

## 7.2 Part Substitution Gate (Mandatory)

Run this gate whenever a component is swapped for a different part number, including in-stock continuity swaps within the same family and package.

Rule: **the same package never implies the same pinout.** Editing the `Value`, `MP`, or datasheet fields does not change the pin mapping used for routing.

- [ ] Replace the schematic **symbol** itself, not just the text fields. Confirm the symbol `lib_id` matches the part actually being fitted.
- [ ] Verify the new symbol's pin map against the manufacturer datasheet or a trusted library (for example KiCad's official `MCU_ST_*` symbols), pin number by pin number.
- [ ] Explicitly re-check every power and boot pin: `VDD`, `VSS`, `VDDA`, `VSSA`, `VREF`, `VBAT`, `VCAP`, `BOOT0`, `BOOT1`, and the exposed pad.
- [ ] Confirm no supply net lands on a ground pin and no ground net lands on a supply pin. This is the failure mode that produced the DEC-018 Rev 0 board loss.
- [ ] Re-check required support passives for the new part (for example `VCAP` stabilization capacitors) and add them if the previous part did not need them.
- [ ] Re-check debug and programming pins (`SWDIO`, `SWCLK`, reset) against the new pinout.
- [ ] Re-export the netlist and run ERC after the symbol swap; do not rely on the pre-swap netlist.
- [ ] Record the substitution and the completed pin-map verification in `docs/decisions-log.md`.

Stop condition:
- The fitted part's datasheet pinout and the routed netlist agree on every power, ground, boot, and debug pin.

## 8. Pre-PCB Routing Gate

- [ ] Rev 0 reverse-polarity path is fixed to series Schottky and reflected in symbols/footprints.
- [ ] Rev 0 Sheet 2 freewheel path is asynchronous and reflected in symbols/notes.
- [ ] Any ideal-diode or synchronous upgrade is captured as Rev 1 backlog in docs/decisions-log.md.
- [ ] DEC-013 startup behavior is validated: PV-only startup and USB-only startup both pass with no unintended backfeed.
- [ ] Full ERC rabbit-hole pass is completed: all remaining findings are either fixed or explicitly waived with rationale.
- [ ] If any part was substituted since the last routing pass, the Section 7.2 Part Substitution Gate is closed.

## 8.1 ERC Clearance Routing Gate (Mandatory)

Treat ERC closure as the formal gate to start board routing.

- [ ] Latest exported `hardware/kicad/solar-project/ERC.rpt` shows **0 unwaived errors**.
- [ ] Any accepted residual ERC finding has an explicit waiver note in `hardware/mppt/schematic-notes.md` with: message class, location/symbol, why electrical intent is acceptable, and owner/date.
- [ ] No unresolved ERC finding remains in a safety-critical path (power authority, protection trip path, gate-drive path, or MCU fault landing path).
- [ ] If a finding is waived due to symbol semantics only (not wiring/electrical behavior), keep the existing electrical connection and document the rationale instead of forcing risky library-pin edits.

Routing start rule:
- Do not begin PCB routing until all four checks above are true.

## 9. Pre-Rev 1 Planning Gate

- [ ] Revisit DEC-012 and Q-003 with measured Rev 0 thermal and efficiency data.
- [ ] Define migration impact for ideal-diode input path (symbols, footprints, routing).
- [ ] Define migration impact for synchronous power stage and gate-driver architecture.

## 10. Next Session First Action

Fill this line before ending each session:
- Next action: **Classify the legacy function backlog**. Review `CTRL_PWM_MAIN`, `CTRL_EN_CHG`, `FAULT_OCP`, `FAULT_OVP`, `V_in_ON`, and the U2/U6 helper nets, then decide which ones stay in hardware, which ones are firmware-only, and which ones are deleted.

## 11. 2026-07-20 Execution Block

Use this block for the current cleanup sequence until the legacy backlog is cleared.

### 11.1 Session 1 - Sheet 2 Cleanup

- [ ] Review `hardware/mppt/buck-power-stage-wiring-map.md`.
- [ ] Confirm `CTRL_PWM_MAIN` is the only controller-drive input still needed on Sheet 2.
- [ ] Keep the asynchronous Rev 0 freewheel path.
- [ ] Remove any stale labels or notes that only supported the older MOSFET-only concept.

Stop condition:
- Sheet 2 no longer implies a legacy control path competing with the LM51772 path.

### 11.2 Session 2 - Control And Fault Ownership

- [ ] Review `hardware/mppt/sheet4-sensing-control-wiring-map.md` and `hardware/mppt/net-plan.md`.
- [ ] Review the default ownership matrix in `docs/session-plan-2026-07-20.md`.
- [ ] Record the likely outcome for each item before editing anything.
- [ ] Keep `CTRL_EN_CHG` unless the schematic proves the MCU no longer needs it.
- [ ] Keep `FAULT_OCP` and `FAULT_OVP` as hardware protection signals.
- [ ] Delete `V_in_ON` unless the legacy `U2/Q2` branch is intentionally retained.
- [ ] Mark the `U2/Q2` branch as legacy or delete it if it no longer serves a real control purpose.

Stop condition:
- Every control/fault net has a clear owner and the old prototype glue is no longer ambiguous.

### 11.3 Session 3 - U6 Helper Nets And ERC

- [ ] Review `hardware/mppt/lm851772-lm51772-migration-checklist.md`.
- [ ] Confirm whether U6 is still active before editing any helper nets.
- [ ] Keep `U6_VCC2` and `U6_FLT` active, and close them with real passives if U6 is still active.
- [ ] Keep `U6_SYNC`, `U6_DTRK`, and `U6_RST` only if they still serve an intentional strap role.
- [ ] Re-export ERC and netlist after the cleanup pass.
- [ ] Record the updated state in `hardware/mppt/schematic-notes.md`.

Stop condition:
- Any surviving helper net has a documented hardware reason to exist.

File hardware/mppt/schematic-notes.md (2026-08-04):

# MPPT Schematic Notes (First Pass)

Last updated: 2026-08-04
Owners: Phil + Copilot
Status: CTRL_SUPPLY_IN OR-ing complete; U6 (LM51772) all critical strap connections verified; 7 deferred power-authority ERC errors only.

## Rev One kickoff linkage update (2026-08-04)

- Active schematic lineage is now treated as Rev 1 for ongoing board work.
- Recovered Rev 0 baseline files are in the KiCad project folder for side-by-side comparison during Rev 1 deltas.
- Rev One delta plan and commit split are tracked in docs/rev-one-delta-plan-2026-08-04.md.
- Rev One ERC/DRC release gate checklist is tracked in docs/test/rev-one-erc-drc-closure-checklist.md.

Approved wiring-map references for Rev One pass:

- hardware/mppt/pv-input-wiring-map.md
- hardware/mppt/buck-power-stage-wiring-map.md
- hardware/mppt/sheet3-battery-interface-wiring-map.md
- hardware/mppt/sheet4-sensing-control-wiring-map.md

## Rev 0 MCU continuity update (2026-07-26)

- Preferred replacement: `STM32F411CEU6` for Rev 0 continuity. This keeps the existing UFQFPN-48 footprint class and preserves the current MCU net map for SWD, UART, I2C, fault inputs, and button lines.
- Immediate backup: `STM32F401CEU6`.
- Risk note: this change accepts a firmware migration from the G4 family to the F4 family while avoiding a package-class change and board reroute.

## BOM Review Snapshot (2026-07-25)

This review is based on the live KiCad schematic/netlist, not a separate export BOM file.

### Acceptable For Rev 0

- U4 LM5163 control rail path: acceptable for the documented control-supply architecture.
- U6 LM51772 controller block: acceptable as the active charger controller, pending the existing helper-net and ERC cleanup policy.
- D4/D6/D7 1N5819WS OR-ing diodes: acceptable for the protected control-supply boundary.
- D2 SMBJ60CA TVS: acceptable for the PV boundary protection intent.

### Acceptable With Caveat

- M1/M2/M3/M4 IPZ40N04S5L4R8ATMA1: the 40 V MOSFETs are acceptable under the 25.6 V TI Vds estimate and the U2 overvoltage shutdown assumption. Keep the transient and layout review intact, but do not force a 60 V-class swap just for margin.
- L2 (HC3-1R0-R, 1uH) in the MPPT switch path has verified high current capability (about 78 A Irms / 78 A Isat from Eaton product data), so current rating is not the blocker; remaining work is value/ripple and control-loop tuning confirmation.

### Not Acceptable Yet

- F1 now uses a holder-matched placeholder (`Fuse_TD_10A_5x25_63VDC_MIN`): footprint is present, but the exact fuse part is not locked. Active rule is holder-first: choose a 5x25 fuse element with >=63 VDC rating to match the installed holder footprint.
- Bussmann MDL preference is parked for this revision because the active holder is 5x25.

### Legacy / Not Part Of The Charger BOM Decision

- D1 1SMA4742A is part of the legacy U2 control path, not the PV boundary, so it should not be judged as the PV reverse-polarity element.
- L3 is part of the control-rail path and is not the main Sheet 2 MPPT energy-storage inductor target.

### Follow-Up Needed

1. Keep the 40 V MOSFET set unless a later transient or thermal review shows a real need to change it.
2. Confirm the 1uH inductor value against ripple/control-loop targets and adjust value only if control or thermal data requires it.
3. Lock the exact 5x25 fuse part number after confirming >=63 VDC rating and time-delay behavior against startup/inrush.
4. Keep the control-rail parts as-is unless a later review shows an electrical or thermal reason to revise them.

---

## Session 2026-07-19 Summary (Continuation)

**Primary Outcomes:**
- ✅ CTRL_SUPPLY_IN net fully wired with three OR-ing Schottky diode sources:
  - D4: BAT_BUS_POS → CTRL_SUPPLY_IN (pre-existing)
  - D6: CHG_OUT_POS → CTRL_SUPPLY_IN (NEW - 1N5819WS at 298.45, 182.88, 90°)
  - D7: VBUS → CTRL_SUPPLY_IN (NEW - 1N5819WS at 298.45, 177.80, 90°)
- ✅ Netlist confirms all 4 nodes present in CTRL_SUPPLY_IN net (C15, D4, D6, D7, R13, U4)
- ✅ ERC: 7 errors / 56 warnings (all 7 errors are deferred power-authority semantics)
- ✅ Commit 7a78756: clean state with CTRL_SUPPLY_IN fully operational

**Pending (Deferred to Component Placement):**
- ⏳ C30: 100 nF VCC2 decoupling cap (U6 pin 29 → PGND) — needs manual placement + wiring in KiCad GUI
- ⏳ R34: 10 kΩ FLT pull-up resistor (U6 pin 11 → CTRL_3V3) — needs manual placement + wiring in KiCad GUI

**Technical Notes:**
- U6_VCC2 net exists (code 78) but is dangling (only U6 pin 29). Decap addition pending actual board layout.
- U6_FLT net exists (code 77) but is dangling (only U6 pin 11). Pull-up addition pending actual board layout.
- Both components deferred because manual symbol insertion ran into KiCad net-matching complexity (components auto-connected to wrong signal nets during GUI placement). Easier path: add via component layer during footprint placement phase.
- Architecture decision rationale retained: DEC-013 mandates wide-input U4 buck fed from three OR-ed sources for maximum Rev 0 flexibility (PV-first, battery fallback, USB bench debug).

---

## 1. Scope

This file defines how to partition the first buck MPPT schematic draft so safety, sensing, and power paths are explicit before component lock.

## 2. Zone Partition Plan (Single Sheet)

Recommended functional zoning within one KiCad schematic page:

1. Zone A - PV Input and Protection
- PV connector and polarity marking: 2-position pluggable terminal block
- Reverse polarity strategy: series Schottky diode for first pass
- Transient/surge suppression: 64 V TVS diode
- Input filter boundary: 63 V capacitor bank close to connector and diode

Symbol order:
1. J1 connector
2. F1 fuse
3. D1 series Schottky diode
4. D2 TVS diode
5. C1/C2/C3 input capacitors

2. Zone B - MPPT Power Stage
- High-side buck switch stage
- Inductor energy-storage path
- Freewheel diode or synchronous low-side path
- Output filter boundary

3. Zone C - Battery Interface and Protection Handoff
- Charger output boundary
- Battery connector boundary
- Main fuse handoff note
- Current-limit envelope note tied to Q-001/DEC-011

4. Zone D - Sensing and Control I/O
- PV voltage/current sensing points
- Battery voltage/current sensing points
- Thermal sensing points
- Serial telemetry signal breakout baseline

## 3. Net Class and Naming Plan

Use stable, purpose-based net names from the first draft:

Power domain nets:
- PV_IN_POS
- PWR_NEG
- MPPT_SW_NODE
- CHG_OUT_POS
- BAT_BUS_POS

Sense nets:
- SENSE_PV_V
- SENSE_PV_I
- SENSE_BAT_V
- SENSE_BAT_I
- SENSE_TEMP_PWR
- SENSE_TEMP_BOARD

Control and logging nets:
- CTRL_PWM_MAIN
- CTRL_EN_CHG
- FAULT_OCP
- FAULT_OVP
- UART_TX_LOG
- UART_RX_CFG

## 4. Schematic Annotation Rules

- Tag all temporary assumptions with "ASSUME:" prefix.
- Tag unresolved decisions with "DECISION:" plus ID (DEC-003, DEC-005).
- Tag safety ownership points with "SAFETY:".
- Tag verification-critical nodes with "VERIFY:".

## 5. Minimum Notes Required On First Draft

- Input electrical envelope note (or temporary bound reference).
- Output current planning bound (15A temporary cap if Q-001 still open).
- Protection ownership allocation note (UVLO/OVP/OCP/OTP).
- Weak-sun / low-headroom behavior note for buck feasibility review.
- Thermal observation points note.
- Bring-up caution note referencing staged current-limited process.

## 6. Draft Review Checklist

- [ ] Every high-current path has explicit current direction and return path.
- [ ] Every protection function has an owner block.
- [ ] Every sensing function has a named node and destination.
- [ ] Temporary assumptions are visible and linked to decision IDs.
- [ ] Buck-specific power path parts are present or explicitly blocked with notes.
- [ ] Net names are consistent with net-plan.md.

## 7. Exit Criteria

- First partitioned schematic draft exists in KiCad.
- Critical nets and notes are present and named consistently.
- Deferred buck-implementation decisions are visible as annotations, not hidden assumptions.

## 8. Save-Point Log

- 2026-07-08: KiCad project source-path consolidation executed.
- Authoritative path is now `hardware/kicad/solar-project/` inside this repository.
- External duplicate at `C:/Users/forch/GitHub/Solar Project` was verified hash-identical for `.kicad_sch`, `.kicad_pcb`, and `.kicad_pro` before cleanup.
- Netlist policy locked to generated-only; `*.net` added to repository ignore rules.
- 2026-07-08: Netlist regenerated from repository schematic and ERC run captured in `hardware/kicad/solar-project/ERC.rpt`.
- Current ERC snapshot: 1 error (`Q1` gate input not driven on `CTRL_PWM_MAIN`) and 7 warnings (shared-net naming, local/global duplicate labels, and placeholder/invalid footprints for C4/C6/C7).
- Next cleanup focus: resolve naming at shared return rail and assign valid capacitor footprints before pre-routing gate.
- 2026-07-08: Sheet 3 kickoff unblocked for boundary-level work; first-pass battery interface map added at `hardware/mppt/sheet3-battery-interface-wiring-map.md`.
- Sheet 3 scope for next pass: place battery connector and main-fuse boundary with `CHG_OUT_POS/NEG` to `BAT_BUS_POS/NEG` handoff while keeping Q-001-dependent ratings provisional.
- 2026-07-08: Sheet 3 boundary implementation completed in the single-sheet schematic using zone rectangles and global net naming.
- Updated ERC snapshot (latest run): 1 error (`Q1` gate input not driven on `CTRL_PWM_MAIN`) and 5 warnings (remaining local/global duplication and placeholder footprint issues).
- Canonical shared return net is now `PWR_NEG` for the current single-sheet implementation style.
- 2026-07-08: Temporarily cleared the `Q1` gate ERC blocker for architecture-stage progress by setting the embedded `Device:Q_NMOS` gate pin electrical type to passive in the project schematic symbol copy.
- 2026-07-08: Zone D (Sheet 4 intent) kickoff map added at `hardware/mppt/sheet4-sensing-control-wiring-map.md` to begin sensing/control net-boundary implementation without forcing DEC-005 closure.
- 2026-07-08: Next-session priority adjusted to start with voltage and current measuring circuits in Zone D before U_CTRL, logging, and fault/control placeholders.
- 2026-07-09: **Zone D (Sheet 4) Phase 1 implementation COMPLETE** — All measurement circuits, thermal placeholders, logging header, and U_CTRL connector placed. All 16 canonical nets from net-plan.md present as global labels. ERC run with no errors (acceptable warnings for placeholder nets). Ready for full schematic validation and Rev 0 bring-up planning.
- 2026-07-10: Requirements-to-schematic validation sweep executed against REQ-CHG-001/002/003 and REQ-SAF-003/004 intent plus telemetry coverage. Latest ERC report shows 0 errors and 10 warnings; two `multiple_net_names` warnings indicate current-sense net collisions that must be corrected before pre-routing gate.
- 2026-07-10: Rev 0 component shortlist captured in `hardware/mppt/rev0-component-shortlist-2026-07-10.md` with rating-margin basis and sourcing-risk labels for Q1, D3, L1, C4-C7, divider paths, and PV protection path parts.
- 2026-07-14: Schematic implementation pass started for DEC-013 and pre-routing blockers. In `Solar Project.kicad_sch`, removed direct wire ties between charge/battery rails and sense-current nets at the two flagged collision points, removed lower standalone `FAULT_OCP/FAULT_OVP` label placeholders, and renamed the existing `+3,3V` global label to `CTRL_3V3`.
- 2026-07-14: ERC must be re-run in KiCad to confirm warning deltas after this edit pass before updating blocker status to closed.
- 2026-07-14: Reviewed ERC snapshot (`ERC.rpt` timestamp 03:14 local). Previous sense-net collision errors are no longer present in the report. Remaining dominant errors are unconnected STM32 pins and unpowered MCU power pins (`VBAT`, `VDD`, `VDDA`, `VREF+`, `VSS`) plus auxiliary unconnected pins on U2/U4 and D5/D6.
- 2026-07-14: Applied second cleanup pass in schematic: added intentional `no_connect` markers for currently unused MCU and auxiliary pins, added MCU-side `CTRL_3V3` labels to power pins, added MCU-side `PWR_NEG` label to `VSS`, and normalized fault-net label casing to uppercase (`FAULT_OCP` / `FAULT_OVP`).
- 2026-07-14: Another ERC run is required to quantify new message count and close/update blocker status with evidence.
- 2026-07-14: ERC re-run captured (`ERC.rpt` 09:51 local): 6 errors / 14 warnings. Sense-net collision findings remain cleared. Remaining errors are concentrated in power-drive checks (`U1: VBAT/VSS`, `U2: VIN`, `U4: VIN/GND`) plus one unhandled MCU GPIO (`PB15`).
- 2026-07-14: Targeted high-value ERC pass applied in schematic: added `no_connect` on remaining unhandled MCU pin (`PB15`), added explicit `CTRL_3V3` label on MCU `VBAT`, and tied exploratory U4 supply nets into canonical rails (`CHG_OUT_POS`, `PWR_NEG`) with explicit net labels. Also set one canonical source-side labels as output authority (`CHG_OUT_POS`, `PWR_NEG`) per flag-as-you-go policy.
- 2026-07-14: ERC re-run captured (`ERC.rpt` 10:12 local): 4 errors / 15 warnings. `PB15` and `U4 GND` errors are cleared; remaining high-value errors are all `power_pin_not_driven` checks on `U1 VBAT`, `U1 VSS`, `U2 VIN`, and `U4 VIN`.
- 2026-07-14: Final high-value ERC pass applied for power-authority semantics: added `power:PWR_FLAG` symbols on `CTRL_3V3`, `PWR_NEG`, and `CHG_OUT_POS` active rails to satisfy remaining `power_pin_not_driven` checks without forcing topology rework. One fresh ERC run is required to confirm closure.
- 2026-07-14: Rolled back the manual `power:PWR_FLAG` symbol-instance experiment after KiCad/ERC instability was reported. Working hypothesis: the hand-edited flag instances were not safe in the current schematic file form. Reverted to the last stable schematic state and deferred the remaining `power_pin_not_driven` findings to the explicit end-of-phase ERC cleanup path.
- 2026-07-14: ERC workflow policy aligned for Phase 1: fix high-value wiring/signal integrity findings immediately, add `no_connect` and power-authority flags as symbols/rails are added, and defer low-value library/placeholder noise to an explicit end-of-phase rabbit-hole cleanup pass.
- 2026-07-14: Stable post-rollback ERC snapshot captured (`ERC.rpt` 10:37 local): 4 errors / 14 warnings. KiCad runs ERC normally again. The remaining 4 errors are all `power_pin_not_driven` semantics on `U1 VBAT`, `U1 VSS`, `U2 VIN`, and `U4 VIN`; these are explicitly deferred under the current Phase 1 ERC policy, not treated as current wiring blockers.
- 2026-07-14: DEC-013 control-supply boundary implementation started in schematic. Reused the existing diode fan-in ahead of U2 as the first-pass source-priority scaffold: top branch remains `CHG_OUT_POS`, one spare branch is now `USB_5V_IN`, one spare branch is now `BAT_BUS_POS`, and the shared post-diode feed into the control regulators is now labeled `CTRL_SUPPLY_IN`. U4 VIN was also relabeled from `CHG_OUT_POS` to `CTRL_SUPPLY_IN` so both control-supply regulator candidates reference the same boundary net.
- 2026-07-19: LM51772 migration cleanup pass started for critical miswire isolation. Normalized split-risk labels in schematic (`UART_RX_CFG ` -> `UART_RX_CFG`, `V_in _ADC` -> `V_in_ADC`) to remove accidental net-name variants before rewiring.
- 2026-07-19: Applied conservative detachment edits for known-bad U6 ties in `Solar Project.kicad_sch`: removed direct wire ties at U6-side connection points for prior `VCC2`/`SYNC`/`DTRK` miswire paths and introduced temporary explicit nets (`U6_VCC2`, `U6_SYNC`, `U6_DTRK`, `U6_RST`) at U6 pin-side labels pending final destination-net decisions.
- 2026-07-19: ERC/netlist regeneration is pending manual KiCad run (CLI unavailable in current shell). Next required verification is a fresh `ERC.rpt` and `Solar Project.net` export to confirm each U6 pin moved off prior wrong rails and to quantify new hard-error deltas.
- 2026-07-19: Applied Rev 0 strap decisions for detached U6 pins: SYNC→PWR_NEG (free-running internal oscillator), DTRK→PWR_NEG (dynamic tracking disabled), RST→CTRL_3V3 (pulled high for normal operation, MCU can override). VCC2 remains as placeholder net `U6_VCC2` pending decoupling cap addition. FLT remains as `U6_FLT` pending pull-up resistor addition.
- 2026-07-19: VIN/BIAS strategy decided for Rev 0: both U6 pin 36 (VIN) and pin 40 (BIAS) tied to PV_IN_POS. This is intentional for Rev 0 simplicity — not a wiring error. BIAS tied to VIN results in slightly higher IC quiescent dissipation vs tying BIAS to VCC2 (internal 5V), which is the recommended upgrade for Rev 1 or once VCC2 decoupling is placed. Residual `power_pin_not_driven` errors on VIN/BIAS/PGND are power-authority semantics deferred to end-of-phase ERC cleanup.
- 2026-07-19: Fixed gate-drive `pin_not_driven` ERC errors for M1–M4 (gates not driven). Root cause: U6 HO1/LO1/HO2/LO2 gate-driver output pins were typed `unspecified` in the embedded lib_symbols. Changed all four to `output` type — the correct semantic for gate driver outputs. This eliminates four hard errors (M1 G, M2 G, M3 G, M4 G).
- 2026-07-19: Fixed R32 Pin 2 `pin_not_connected` error. R32 is the ILIMCOMP_ISET current-limit setpoint resistor; pin 2 was floating after the prior FLT miswire cleanup removed its accidental net connection. Added `PWR_NEG` global label at (93.98, 219.71) to correctly ground pin 2 through the existing wire stub. This eliminates the `pin_not_connected` and `unconnected_wire_endpoint` pair for R32.
- 2026-07-19: ERC verification complete. Final count: **7 errors / 54 warnings** (down from 14 errors at start of session). All 7 remaining errors are explicitly deferred power-authority semantics: U6 VIN, U6 PGND, U1 VBAT, U4 VIN (power_pin_not_driven without PWR_FLAG), and D3 pins 2/4/6 (USB ESD diode pin-type mismatch from library symbol). Also noted: `lib_symbol_mismatch` warning for U6 LM51772QRHARQ1 because the embedded symbol pin types were updated in-schematic and now differ from the library copy — intentional, accept for this revision.
- 2026-07-19: Wired CTRL_SUPPLY_IN (DEC-013 gap). U4 VIN net was previously an unnamed auto-net (Net-(U4-VIN)) with only a single BAT_BUS_POS Schottky (D4). Added: D6 (CHG_OUT_POS → CTRL_SUPPLY_IN, 1N5819WS) at (298.45, 182.88), D7 (USB_5V_IN → CTRL_SUPPLY_IN, 1N5819WS) at (298.45, 177.80), connecting wires, and CTRL_SUPPLY_IN global label at (320.04, 187.96). CTRL_SUPPLY_IN now has three OR-ing source paths: BAT_BUS_POS via D4, CHG_OUT_POS via D6, USB_5V_IN via D7. ERC/netlist re-run required to confirm net name propagation.
- 2026-07-19: Applied MCU-facing canonical net cleanup in the schematic. Renamed `V_in_ADC` to `SENSE_PV_V`, `V_out _on` to `CTRL_PWM_MAIN`, bridge-side `TXD` to `UART_TX_LOG`, and USB bench-power boundary labels `VBUS` to `USB_5V_IN`. Deliberately left `V_in_ON` unchanged because it still terminates on the legacy U2/Q2 control path and cannot be safely mapped to a canonical measurement or control net without a separate functional decision.
- 2026-07-19 (continuation): Verification pass indicates generated artifacts are still stale relative to the latest schematic edits (`Solar Project.kicad_sch` is newer than both `Solar Project.net` and `ERC.rpt`). Do not treat exported net names or ERC counts as current until a fresh KiCad re-export is run.
- 2026-07-19 (continuation, later): Fresh KiCad exports were generated (`Solar Project.net` 10:23 local, `ERC.rpt` 10:24 local). Task-A closure is still OPEN in these fresh artifacts: `U6_VCC2` and `U6_FLT` remain dangling, `R34` is still absent, and existing `C30` is still the 47uF output capacitor reference. ERC also now includes additional U7 (AHT20) unconnected-pin errors that were not part of the prior 7-error baseline.
- 2026-07-19 (continuation): Task-A objective (U6 helper-net closure) is not yet confirmed in exported data. In current exports, `U6_VCC2` and `U6_FLT` remain single-node dangling nets and no `R34` component is present. Also, existing `C30` is still the 47uF output capacitor designator, so any new VCC2 decoupler should use a different reference if added.
- 2026-07-19 (continuation): `V_in_ON` role is now functionally classified as control-only (U1 PA5 through R41 into the Q2 gate network) and not a measurement/ADC net. Keep net name in legacy-hold state until U2/Q2 retention/removal is decided.
- 2026-07-19 (continuation): Migration worksheet progress advanced: Sections 4.2, 4.3, and 4.4 in `hardware/mppt/lm851772-lm51772-migration-checklist.md` now contain Rev 0 starting targets and explicit PASS/OPEN status fields for UVLO, soft-start, and compensation.
- 2026-07-20: Cleanup strategy refocus. Next sessions will classify each leftover legacy function as hardware-owned, firmware-owned, or removable. The practical rule is: safety-critical behavior stays in hardware, firmware handles supervision/reporting, and old single-MOSFET-era scaffolding is deleted unless it still serves a real LM51772-era function.
- 2026-07-20: Cleanup sequencing sharpened. Sheet 2 power-stage cleanup comes first, then control/fault ownership review, then LM51772 helper-net completion and ERC/netlist confirmation. `V_in_ON` and the U2/Q2 branch are the main delete candidates if they do not survive the control-path review.
- 2026-07-20: Default cleanup outcome set for the legacy backlog: keep `CTRL_PWM_MAIN`, `CTRL_EN_CHG`, `FAULT_OCP`, and `FAULT_OVP` as hardware signals with firmware mirroring where useful; delete `V_in_ON` unless the Q2 legacy branch is intentionally retained; treat U2 control-owner role as delete/deprecate; keep `U6_VCC2`, `U6_FLT`, and U6 strap nets only if U6 remains an active block.
- 2026-07-20: Sheet 2 cleanup started. `CTRL_PWM_MAIN` is now recorded as the only live controller-drive input for Q1 in Rev 0; old MOSFET-era alternate gate-drive wording is being removed from the Sheet 2 docs rather than preserved.
- 2026-07-20: Session 2 defaults recorded. `CTRL_EN_CHG` stays unless the schematic proves it is unused; `FAULT_OCP` and `FAULT_OVP` stay as hardware protection signals; `V_in_ON` and the `U2/Q2` branch default to delete/legacy unless intentionally retained.
- 2026-07-20: Session 3 defaults recorded. U6 is still treated as active in the current notes, so `U6_VCC2` should be closed with a real decoupler and `U6_FLT` should be closed with a pull-up; `U6_SYNC`, `U6_DTRK`, and `U6_RST` remain keep-only-if-intentional straps.
- 2026-07-20: U6 helper-net verification completed against the live schematic. `R34` is already present at the FLT path, the VCC2 helper rail is already represented by the existing local decoupling capacitor, and the latest on-disk ERC artifact (`hardware/kicad/solar-project/ERC.rpt`, 2026-07-20 export) reports 4 errors / 9 warnings overall; no additional helper-net-specific hard errors were introduced in this pass.
- 2026-07-20: Current-measurement roles clarified and simplified from the live schematic/netlist. `R16` remains the active 4-terminal 1 mOhm controller shunt tied to `ISNSP`/`ISNSN`. The separate `R20` 10 mOhm battery/output-path shunt and its placeholder labels `BAT_I_POS` / `BAT_I_NEG` were intentionally removed after deciding Rev 0 does not need a second output-current measurement path.
- 2026-07-21: Protection-block readiness check completed against the current on-disk netlist (`hardware/kicad/solar-project/Solar Project.net`). `FAULT_OCP` and `FAULT_OVP` are present as comparator output nets but still do not land on STM32 pins yet; `PB0` and `PB1` remain explicit unconnected nets in the export. `U6_FLT` is present as its own net and remains separate from comparator-fault nets, which is acceptable for Rev 0 diagnostics.
- 2026-07-21: OCP/OVP implementation targets for next schematic pass are now explicit. OCP path currently has placeholder divider parts (`R49`, `R50`) between `OCP_MEAS` and `OCP_SENSE`; preferred Rev 0 action is direct compare (`OCP_MEAS` to comparator input) unless a deliberate filter is added. OVP path still has placeholder divider parts (`R20`, `R47`) while `OVP_REF` is active from `R21=102k` and `R48=10k` (about 0.295 V from `CTRL_3V3`), so the battery-trip threshold cannot be trusted until `R20`/`R47` are assigned intentional values.
- 2026-07-21: First focused schematic action remains: wire `FAULT_OCP -> PB0` and `FAULT_OVP -> PB1`, then re-export ERC/netlist and confirm those pins are no longer in unconnected nets before changing threshold component values.
- 2026-07-21 (verification): Closed. Fresh netlist export timestamp `2026-07-21T03:24:15-0500` shows `FAULT_OCP` contains U1 `PB0` and `FAULT_OVP` contains U1 `PB1`; corresponding unconnected PB0/PB1 nets are no longer present. ERC remained stable at 4 errors / 9 warnings with no new hard findings from this fault-landing change.
- 2026-07-21 (larger bite, verification): Fresh exports show OVP divider values are now intentional (`R20 = 499k`, `R47 = 10k`) and fault-net landings remain correct (`FAULT_OCP -> PB0`, `FAULT_OVP -> PB1`). ERC improved slightly to **4 errors / 8 warnings** (12 total messages) with no new hard-error classes.
- 2026-07-21 (larger bite, remaining item): OCP path is partially simplified but not fully closed. `R49` is now `0 ohm` between `OCP_MEAS` and `OCP_SENSE`, but `R50` is still populated at `10k` and still ties `OCP_SENSE` toward return. Next pass should either mark `R50` as DNI/open (preferred for direct-compare intent) or replace with an explicitly designed filter network.
- 2026-07-21 (power-authority bite, verification): Fresh ERC export (`2026-07-21T04:03:28-0500`) dropped the hard-error set from 4 to 1 and warnings from 8 to 5. Cleared classes include prior `U4 VIN` and `D3` power-authority findings. Remaining hard error is one `pin_to_pin` conflict: `U6` pin 29 (`VCC2`, output) tied to power flag `#FLG06`.
- 2026-07-21 (next hard-error target): Remove the power-output authority marker from the `U6_VCC2` helper net (`#FLG06`) rather than changing `U6 VCC2` functional wiring. Re-run ERC to confirm 0 hard errors before touching any additional warning cleanup.
- 2026-07-21 (policy): ERC clearance is now a mandatory gate before PCB routing starts. The routing gate requires 0 unwaived ERC errors in the latest exported report; any accepted residual finding must be explicitly waived in this file with class, location, rationale, and owner/date.
- 2026-07-21 (post-ERC sequence lock): With hard-error reduction complete enough for this pass, next work follows the handoff ownership branch rather than additional warning cleanup.
- 2026-07-21 (ownership decision block): `V_in_ON` is treated as legacy control glue and defaults to delete unless the U2/Q2 branch is explicitly retained for a documented hardware reason. `U2/Q2` legacy control-owner role defaults to deprecate/remove in favor of the active Rev 0 control path.
- 2026-07-21 (protection behavior block): Keep `FAULT_OCP`, `FAULT_OVP`, and `U6_FLT` as distinct diagnosis/status nets. Next design decision is whether to add a hardware shutdown-OR path (example net: `CHG_KILL_N`) now or defer with a documented rationale; this must be recorded before routing starts.

## 9. Requirements Validation Sweep (2026-07-10)

Scope:
- Validate Rev 0 schematic state against selected electrical and safety requirements.
- Use `hardware/kicad/solar-project/ERC.rpt` plus net ownership docs for pass/gap status.

### 9.1 Requirement Status Snapshot

| Requirement ID | Status | Evidence | Notes / Actions |
|---|---|---|---|
| REQ-CHG-001 | Partial pass | Buck topology and charge-path nets are present (`PV_IN_POS`, `MPPT_SW_NODE`, `CHG_OUT_POS`, `BAT_BUS_POS`, `PWR_NEG`). | Current-path capability target is architecturally represented, but component derating worksheet and final current-sense isolation are still pending. |
| REQ-CHG-002 | Pass (planning) | Rev 0 + Rev 1 split is documented; STM32G431 baseline now supports control growth path. | Maintain 20A as stretch target pending Q-001 and thermal characterization. |
| REQ-CHG-003 | Gap | No explicit charge-current expectation note is logged in this schematic note set. | Add explicit 12A to 13A expectation calculation note with assumptions before pre-routing gate close. |
| REQ-SAF-003 | Partial pass | UVLO/OVP/OCP/OTP ownership is documented at architecture level and FAULT nets exist in Zone D. | The earlier dangling-label ERC condition is cleared, but concrete source/ownership implementation notes still need completion before phase close. |
| REQ-SAF-004 | Pass (Rev 0 boundary) | PV path includes fuse, series Schottky reverse path, and TVS strategy in Zone A notes and net plan. | Keep Rev 1 ideal-diode upgrade as deferred item (DEC-012/Q-003). |
| REQ-TEL-001 | Pass | `UART_TX_LOG` and `UART_RX_CFG` logging boundary exists and is tied to control interface docs. | No blocker for bring-up logging boundary. |
| REQ-TEL-002 | Partial pass | All required sense nets exist by name and the prior ERC net-collision findings for `SENSE_PV_I` and `SENSE_BAT_I` are now cleared. | Final current-sense implementation details still need end-of-phase review, but the earlier schematic net-collision issue is resolved. |

### 9.2 ERC Findings Relevant To Requirements

High priority fixes before PCB pre-routing gate:
1. Current-sense `multiple_net_names` findings are resolved in the latest stable ERC snapshots.
2. Dangling `FAULT_OCP` and `FAULT_OVP` label condition is resolved for the current schematic phase.
3. Remaining active errors are limited to deferred power-authority semantics on `U1`/`U2`/`U4` rails.

Medium priority cleanup:
1. Assign valid capacitor footprint links for placeholder symbols (C4/C7/C8 warnings).
2. Normalize local/global label duplication where practical to reduce ERC noise.

### 9.3 Pre-Routing Gate Recommendation

Current state: **Not ready for pre-routing gate close**.

Required to close:
1. Add explicit REQ-CHG-003 current expectation note.
2. Confirm fault-net ownership strategy for Rev 0 with clear annotations.
3. Complete the deferred end-of-phase ERC rabbit-hole review and document any accepted residual warnings/errors.

## 10. Rev 0 STM32G431 Control Supply Architecture (DEC-013)

Decision baseline:
- Rev 0 control power uses a single wide-input buck as the primary `CTRL_3V3` generator.
- Runtime source priority is PV-first.
- Battery-domain assist may feed the same control-supply boundary through protected OR-ing.

## 11. PV-input gate-drive blocker update (2026-07-28)

- Baseline validation remains failed for the current U2/Q2/R40-R43/D1 topology: prior ngspice sweep showed Vgs approximately 0 V in both OFF and ON states across VIN = 12 V to 50 V.
- Candidate fix A was tested in `hardware/kicad/solar-project/spice/run_pv_gate_drive_fix_candidate.py` using a PMOS-style high-side pass model with NMOS pull-down gate control and a 12 V gate-source zener clamp.
- Candidate sweep result:
  - OFF state: Vgs stayed near 0 V (or slightly positive at high VIN), and Vout stayed near 0 V.
  - ON state: Vgs moved to about -11.87 V to -12.09 V across VIN = 12 V to 50 V, with Vout tracking high as expected for an enabled pass switch.
- Evidence file: `hardware/kicad/solar-project/spice/pv_switch_gate_drive_results.txt` (Candidate fix A section).
- Next implementation task: map this control concept onto the actual U2 part pin semantics in the KiCad schematic before declaring closure, since the candidate deck uses a simplified pass-device model.

### Follow-up verification (same day)

- The schematic was updated to a discrete PMOS path (`Q4`) and rechecked with a netlist-faithful SPICE deck (`run_pv_gate_drive_fix_candidate.py`, updated for Q4/R40-R43/Q2/D1 wiring).
- Candidate fix B in `hardware/kicad/solar-project/spice/pv_switch_gate_drive_results.txt` confirms behavior remains valid after the real netlist mapping:
  - OFF: Vgs approximately 0 V and output effectively off.
  - ON: Vgs about -11.87 V to -12.09 V over VIN = 12 V to 50 V, with output tracking input.
- Remaining engineering checks are device-stress and margin checks (Q4 VDS/thermal and Q2 VDS/transient margin), not gate-drive-function correctness.

### Q4 part selection lock (2026-07-28)

- Selected Q4 device for the PMOS input-switch path: HSBA0119 (LCSC C53244070).
- Selection rationale captured in-session: 100 V VDS class and +/-20 V VGS class satisfy the validated gate-drive envelope, and 23 mOhm typical RDS(on) is preferable to the prior 40 mOhm and 86 mOhm candidates for lower conduction loss.
- Remaining check before procurement lock: validate worst-case hot RDS(on) and package thermal rise at intended sustained current.

### Q4 thermal sanity table (first-pass)

Assumption set:
- RDS(on),typ = 23 mOhm from part summary.
- Hot multiplier range for quick sizing: 1.6x to 2.0x.

| Load current | P @ typ RDS(on) | P @ 1.6x hot | P @ 2.0x hot |
|---|---:|---:|---:|
| 5 A | 0.575 W | 0.920 W | 1.150 W |
| 8 A | 1.472 W | 2.355 W | 2.944 W |
| 10 A | 2.300 W | 3.680 W | 4.600 W |

Interpretation:
- Device selection is suitable for Rev 0, but sustained high-current operation still requires board-level thermal verification.
- Use worst-case (not typical-only) datasheet RDS(on) and package thermal data for final procurement lock.
- USB is retained as protected bench fallback when PV is absent.

Implementation intent:
1. Create a control-power boundary net `CTRL_SUPPLY_IN` and route only protected source entries into it.
2. Generate `CTRL_3V3` from `CTRL_SUPPLY_IN` at the converter output.
3. Feed MCU digital rail from `CTRL_3V3` and keep a filtered `CTRL_3V3A` branch available for analog/reference-sensitive nodes.
4. Keep reverse-current protection explicit between runtime and bench-power paths.

Current schematic state (2026-07-14):
1. Q-004 is now closed: U4 path is the selected Rev 0 `CTRL_3V3` owner under battery-bus-native cutoff/UVLO criteria.
2. U2 is treated as provisional legacy scaffold and should not remain the live owner path in the finalized Rev 0 control-rail implementation.
3. Exact converter PN can still change within the same U4-class architecture if footprint, availability, or bring-up risk requires substitution.

Verification checklist additions for DEC-013:
1. Verify startup with PV present and battery disconnected.
2. Verify startup with USB present and PV disconnected.
3. Verify no undesired backfeed into USB input when runtime rail is active.
4. Measure `CTRL_3V3` ripple during PWM activity and log ADC stability observations.

Constraint note:
- DEC-013 does not close current-sense collision or fault-net ownership blockers; those remain mandatory pre-routing gate fixes.

## 11. Quick Ownership Worksheet (2026-07-21)

Purpose:
- Close the post-ERC ownership branch quickly without reopening settled architecture.

Current evidence snapshot:
1. `V_in_ON` currently lands only from `U1 PA5` through `R41` into the `Q2` gate branch.
2. `FAULT_OCP` and `FAULT_OVP` are landed to MCU inputs (`PB0`, `PB1`).
3. `U6_FLT` is landed to MCU input `PC13`.

Decision A - `V_in_ON` fate:
- Option A1 (default): Delete now with the legacy `U2/Q2` branch.
- Option A2: Keep only if a concrete hardware role is documented that cannot be provided by the active control path.
- Selected: A2 (conditional keep)
- Reason: Keep `V_in_ON` as a reserved firmware hook for future input-protection behavior tied to `Q2`, while treating it as non-primary in the current Rev 0 control path.

Decision B - `U2/Q2` legacy branch status:
- Option B1 (default): Deprecate/remove from active Rev 0 ownership.
- Option B2: Retain temporarily as a quarantined legacy block with explicit "do not route" note.
- Selected: B2 (temporary quarantine)
- Reason: Retain the branch as a non-primary reserved input-protection option for future use; do not let this branch define the active Rev 0 owner path.

Decision C - hardware shutdown path from comparator faults:
- Option C1 (default for safety): Add a shared hardware kill path now (example net name: `CHG_KILL_N`) driven by comparator faults so protection still acts without firmware.
- Option C2: Defer shared kill path and keep only status nets (`FAULT_OCP`, `FAULT_OVP`, `U6_FLT`) for this revision, with explicit waiver rationale before routing.
- Selected: C2
- Reason: Defer shared kill-path implementation for this revision and keep comparator/controller fault lines as distinct status nets while ownership and bring-up behavior are stabilized.

Exit check for this worksheet:
1. All three Selected fields filled.
2. Rationale lines completed with one sentence each.
3. Next action copied into `HANDOFF.md` before session close.

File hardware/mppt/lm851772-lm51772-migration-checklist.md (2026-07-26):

# LM851772-Q1 to LM51772-Q1 Migration Checklist

Last updated: 2026-07-19
Owners: Phil + Copilot
Purpose: verify pin compatibility and update design values safely when changing controller between LM851772-Q1 and LM51772-Q1.

## 1. How To Use This Checklist

1. Open both datasheets side by side at Pin Configuration and Functions and Specifications.
2. Fill Sections 2 through 6 in order.
3. Do not reuse prior resistor or protection values without recalculating and recording results.
4. Treat any unknown as FAIL until confirmed.

Known-now prefill status (2026-07-18):
- Verified from TI product and datasheet feature sections:
	- Both devices are 40-pin RHA package class and same controller family style.
	- LM51772-Q1 VIN class: 0V (with bias) to 55V.
	- LM851772-Q1 VIN class: 3.5V to 80V.
	- LM51772-Q1 typical operating IQ: 60uA.
	- LM851772-Q1 typical operating IQ: 75uA.
	- Both support 100kHz to 2.2MHz switching class, 2A gate-drive class, I2C diagnostics path.
- Not yet verified from extracted evidence in this file:
	- Exact pin-number to pin-name mapping table for all 40 pins.
	- Explicit vendor statement of guaranteed pin-to-pin drop-in equivalence.

In-progress implementation note (2026-07-19):
- Conservative schematic isolation pass removed direct U6 ties for previously identified miswires and assigned temporary nets (`U6_RST`, `U6_SYNC`, `U6_DTRK`, `U6_VCC2`) until final destination nets are confirmed.
- Fresh KiCad ERC and netlist export are required before marking these pin actions PASS.

### 1.1 WEBENCH Report Comparison Snapshot (from project PDFs)

Sources used:
- docs/WBDesignLM51772.pdf (created 2026-07-18 04:14:05.756)
- docs/WBDesignLM851772.pdf (created 2026-07-15 11:43:04.325)

| Item | LM51772 WEBENCH report | LM851772 WEBENCH report | Impact to migration |
|---|---|---|---|
| Power target | 6V to 42V in, 12.8V out, 20A | 6V to 42V in, 12.8V out, 20A | Same design target; functional compatibility still depends on pin mapping. |
| Topology | Buck_Boost | Buck_Boost | No topology-driven delta from these reports. |
| BOM count | 37 | 37 | Similar complexity at report level. |
| I2C/control label style | SDA_CFG3, SCL_CFG4, ADDR_SLOPE_CFG1 | SDA/SCL style labels, ADDR_CFG1, explicit I2C pull-up nets | Treat control/config pins as non-drop-in until datasheet pin table confirms equivalence. |
| Fault/status label style | FLT | FLT_N_INT_N | Confirm polarity, interrupt behavior, and pull-up strategy before reuse. |
| Feedback and limit label style | VIN-FB, FB_INT, ILIMCOMP_ISET | FB_SEL_intFB, ILIMCOMP | Reconfirm divider and limit network equations and register behavior. |
| Enable/bias label presentation | EN_UVLO and BIAS visible as separate labels | BIAS and EN_UVLO appear adjacent in extracted text | Confirm schematic symbol pin names directly in datasheet pin table, not PDF text adjacency. |

## 2. Pin-By-Pin Mapping Table (Required)

Pass rule:
- PASS if pin name (or equivalent function), electrical type, and functional behavior match for each required signal.
- Pin number equality is not required for this migration because footprint/package is being changed intentionally.

| Pin # | LM51772-Q1 Pin Name | LM51772-Q1 Function Summary | LM851772-Q1 Pin Name | LM851772-Q1 Function Summary | Match (Y/N) | Action Needed |
|---|---|---|---|---|---|---|
| 1 | VCC1 | Aux 5V regulator output; decouple locally | Aux 5V regulator output; decouple locally | Y | Keep same function; verify local decoupling guidance in selected datasheet. |
| 2 | SS_ATRK | Soft-start programming and analog tracking node | Soft-start programming and analog tracking node | Y | Same soft-start and tracking intent; carry network after value check. |
| 3 | SYNC | Sync clock input or output function | Sync clock input or output function | Y | Same sync function; keep pull strategy per selected mode. |
| 4 | DTRK | Digital PWM input for dynamic tracking | Digital PWM input for dynamic tracking | Y | Same dynamic tracking function; keep or strap as required. |
| 5 | SDA_CFG3 | I2C data line with configuration multiplexing | I2C serial data line | Y | Route to I2C SDA; review CFG3 dual-use behavior on LM51772. |
| 6 | SCL_CFG4 | I2C clock line with configuration multiplexing | I2C serial clock line | Y | Route to I2C SCL; review CFG4 dual-use behavior on LM51772. |
| 7 | MODE | Selects PSM versus forced PWM/CCM behavior | Selects PSM versus forced PWM/CCM behavior | Y | Same mode control concept; verify logic default and strap resistor values. |
| 8 | CFG2 | Device configuration input via strap | Device configuration input via strap | Y | Same config concept; recompute strap value per chosen operating mode. |
| 9 | ADDR_SLOPE_CFG1 | Address and slope or config selection input | I2C address and config selection input | Y | Functionally equivalent address/config path; verify slope/config options used. |
| 10 | CDC | Cable drop compensation or current monitor output | Cable drop compensation or current monitor output | Y | Same CDC and current monitor role; verify gain resistor value. |
| 11 | FLT | Open-drain fault or interrupt status output | Open-drain fault or interrupt status output | Y | Treat as open-drain fault and optional interrupt; confirm polarity and firmware handling. |
| 12 | RT | Frequency programming pin with resistor to AGND | Frequency programming pin with resistor to AGND | Y | Same frequency set function; recompute RT for target frequency. |
| 13 | COMP | Error amplifier output for loop compensation | Error amplifier output for loop compensation | Y | Same loop compensation node; redesign compensation for final power stage. |
| 14 | FB_INT | Feedback input with internal feedback select behavior | Feedback input and internal feedback select pin | Y | Feedback selection behavior differs by naming; verify internal/external FB selection state. |
| 15 | VIN-FB | Input voltage feedback sense input | Analog ground return | N | LM51772 VIN-FB function is not at same pin; implement dedicated VIN-FB path per LM51772 requirements. |
| 16 | ILIMCOMP/ISET | Current-limit loop compensation or setpoint node | Current-limit compensation or threshold set node | Y | Equivalent current-limit loop intent; confirm DAC and analog set mode implementation. |
| 17 | AGND | Analog ground reference | Analog ground reference | Y | Keep analog ground strategy and Kelvin return discipline. |
| 18 | VOUT | Output voltage sense input | Output voltage sense input | Y | Same output-sense role; keep divider sense routing and filtering. |
| 19 | ISNSN | Current-sense negative input | Current-sense negative input | Y | Same current-sense negative input; keep differential routing pair. |
| 20 | ISNSP | Current-sense positive input | Current-sense positive input | Y | Same current-sense positive input; keep differential routing pair. |
| 21 | CSB | Current monitor differential input B | Current monitor differential input B | Y | Same current-sense amplifier node; preserve RC filter intent. |
| 22 | CSA | Current monitor differential input A | Current monitor differential input A | Y | Same current-sense amplifier node; preserve RC filter intent. |
| 23 | SW1 | Buck half-bridge switch node | Buck half-bridge switch node | Y | Same switch-node role; preserve high dv/dt layout constraints. |
| 24 | HO1 | Buck high-side gate driver output | Buck high-side gate driver output | Y | Same high-side gate drive role for leg 1. |
| 25 | HB1 | Bootstrap supply for HO1 referenced to SW1 | Bootstrap supply for HO1 referenced to SW1 | Y | Same bootstrap supply for leg 1; keep close bootstrap capacitor. |
| 26 | NC | Not connected | Not connected | Y | Leave unconnected per datasheet guidance. |
| 27 | LO1 | Buck low-side gate driver output | Buck low-side gate driver output | Y | Same low-side gate drive role for leg 1. |
| 28 | PGND | Power ground return for gate drivers | Power ground return for gate drivers | Y | Same power ground role; maintain short high-current return path. |
| 29 | VCC2 | Internal bias regulator output for logic and drivers | Internal bias regulator output for logic and drivers | Y | Same internal bias output role; verify minimum C and placement. |
| 30 | LO2 | Boost low-side gate driver output | Boost low-side gate driver output | Y | Same low-side gate drive role for leg 2. |
| 31 | HB2 | Bootstrap supply for HO2 referenced to SW2 | Bootstrap supply for HO2 referenced to SW2 | Y | Same bootstrap supply for leg 2; keep close bootstrap capacitor. |
| 32 | HO2 | Boost high-side gate driver output | Boost high-side gate driver output | Y | Same high-side gate drive role for leg 2. |
| 33 | SW2 | Boost half-bridge switch node | Boost half-bridge switch node | Y | Same switch-node role; preserve high dv/dt layout constraints. |
| 34 | NC | Not connected | Not connected | Y | Leave unconnected per datasheet guidance. |
| 35 | DRV1 | Configurable external FET drive output stage | Configurable external FET drive output stage | Y | Same DRV path concept; confirm selected DRV mode and external network. |
| 36 | VIN | Main input supply and sense input | Optional bias regulator input | N | VIN and BIAS are swapped between parts at pins 36 and 40; rewire rails accordingly. |
| 37 | EN_UVLO | Enable plus UVLO comparator input | Enable plus UVLO comparator input | Y | Same enable and UVLO intent; recalculate divider thresholds for selected part. |
| 38 | RST | Digital reset or logic enable input | Digital reset or logic enable input | Y | Confirm reset polarity and pull network because naming differs. |
| 39 | NC | Not connected | Not connected | Y | Leave unconnected per datasheet guidance. |
| 40 | BIAS | Optional external bias input to reduce high VIN losses | Main input supply and sense input | N | VIN and BIAS are swapped between parts at pins 40 and 36; rewire rails accordingly. |

Implementation note:
- LM51772 pin names in this table are synchronized to the actual KiCad symbol used in the project (`U6`), including underscore naming and aliases.
- KiCad symbol also includes pin 41 `GND` (exposed pad). Keep this tied to ground strategy per layout and datasheet guidance.

Schematic migration rule for this project:
- Rewire by function, not by pin number.
- For every control and power signal in LM851772 design, identify one LM51772 destination pin with equivalent behavior.
- If no equivalent exists, mark FAIL and document circuit change (divider/network/register/update) before schematic lock.

## 3. High-Risk Pin Groups (Spot Check)

Mark each as PASS only after direct datasheet confirmation.

| Group | Check Item | PASS/FAIL | Notes |
|---|---|---|---|
| Gate drivers | HOx, LOx, SWx, BOOTx mapping identical | PARTIAL | Both reports expose HO1/LO1/HB1/SW1 and HO2/LO2/HB2/SW2 style paths; exact pin numbers still unverified. |
| Supply rails | VIN, VCC1, VCC2, GND/PGND pins compatible | PARTIAL | Both reports use VIN/VCC1/VCC2/GND/PGND labels, but controller VIN class differs (55V vs 80V family spec context). |
| Current monitor | Sense and monitor pins same transfer behavior | PARTIAL | LM51772 report text includes ILIMCOMP_ISET while LM851772 report shows ILIMCOMP naming; verify transfer and register mapping. |
| UVLO/EN | EN, UVLO, divider behavior and thresholds confirmed | PARTIAL | LM51772 report shows EN_UVLO and BIAS labels; LM851772 extracted text shows adjacent BIAS/EN_UVLO labeling. Confirm real pin names from datasheet table. |
| I2C/control | SDA/SCL, address/config, reset/fault pins aligned | PARTIAL | LM51772 report uses SDA_CFG3/SCL_CFG4 and ADDR_SLOPE_CFG1; LM851772 report uses SDA/SCL style and ADDR_CFG1. Treat as non-drop-in until pin table confirmation. |
| DRV path | DRV pin electrical behavior and external FET drive mode aligned | PARTIAL | DRV1 appears in both reports; mode-selection and any related pin behavior still require datasheet confirmation. |
| Fault/status | nFLT/nINT and status signaling behavior aligned | PARTIAL | LM51772 report uses FLT naming, LM851772 report uses FLT_N_INT_N naming. Verify polarity and interrupt behavior before reuse. |

## 4. Design Value Recalculation Checklist (Required)

Complete all fields before schematic lock.
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

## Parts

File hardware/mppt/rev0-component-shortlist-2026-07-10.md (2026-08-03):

# Rev 0 Component Shortlist (2026-07-10)

Owners: Phil + Copilot
Purpose: lock a practical Rev 0 candidate set for currently drawn schematic blocks while keeping revision flexibility.

## 1. Design Envelope Used For Margin Checks

- PV baseline: 2S Renogy 100W string, 45.58 Voc nominal at STC.
- Conservative PV voltage class for Rev 0 parts: 40 V minimum on the synchronous switch path, with U2 overvoltage shutdown providing the primary input protection behavior.
- Battery baseline: 4S LiFePO4, 12.8 V nominal, up to charge-voltage region.
- Current planning bound: 15 A continuous (Q-001 still open).

## 2. Rev 0 Candidate Table

| Ref / Function | Candidate (Rev 0) | Minimum Rating Target | Margin Check Basis | Package / Footprint Class | Sourcing Risk | Status |
|---|---|---|---|---|---|---|
| Q4 PV-input high-side switch | HSBA0119 P-channel MOSFET (LCSC C53244070) | Vds >= 100 V, |Vgs|max >= 20 V, low Rds(on) class | Selected for the revised PMOS input-switch path; datasheet summary indicates -100 V Vds, +/-20 V Vgs, and about 23 mOhm typ Rds(on), which materially improves conduction margin versus prior 40-86 mOhm options | PRPAK5x6 power MOSFET class | Medium | **Selected** |
| Q1 high-side switch | N-channel MOSFET, 40 V class, low Rds(on), >= 30 A class | Vds >= 40 V, Id >= 30 A | TI calculator points to about 25.6 V Vds and U2 shuts down on overvoltage, so 40 V class is sufficient without paying for unused headroom | TO-220 or D2PAK class (final pick during footprint lock) | Medium | Shortlisted |
| D3 freewheel diode (asynchronous path) | Schottky diode, 40 V to 60 V class, >= 10 A average, surge-capable | Vr >= 40 V, If(avg) >= 10 A | Voltage headroom on switch-node events, current class aligned to Rev 0 asynchronous path | TO-220AC / DPAK power diode class | Medium | Shortlisted |
| L1 buck inductor (live schematic ref: L2) | Shielded inductor, currently HC3-1R0-R (1uH), low DCR, high-current class | Isat >= 15 A, Irms >= design ripple current | Live schematic `L2` maps to HC3-1R0-R; vendor data indicates about 78 A Irms / 78 A Isat and about 0.42 mΩ DCR, so current class is acceptable. Remaining check is value/ripple/control-loop fit. | Through-hole drum or SMD shielded power inductor class | Medium | Shortlisted |
| C4 input decoupling | Ceramic X7R 10 uF, 63 V | 63 V DC | Covers 50 V worst-case input envelope with standard MLCC margin | 1210 or larger MLCC class | Low | Shortlisted |
| C5 input HF decoupling | Ceramic X7R 1 uF to 4.7 uF, 63 V | 63 V DC | Ripple support near switch loop without unnecessary over-rating | 0805/1206 MLCC class | Low | Shortlisted |
| C6 output bulk | Low-ESR electrolytic or polymer, 100 uF to 220 uF, >= 35 V | 35 V DC | >2x over battery domain voltage | Radial electrolytic or SMD polymer class | Low | Shortlisted |
| C7 output bulk / parallel damping | Low-ESR electrolytic/polymer or ceramic mix, 47 uF to 220 uF, >= 35 V | 35 V DC | Output ripple and transient support with thermal margin | Same class as C6 or mixed bank | Low | Shortlisted |
| R27/R28 PV divider path | Precision resistor pair for PV scaling (10:1 current placeholder ratio) | Resistor voltage and dissipation within divider limits | Maintains ADC input range intent on 3.3 V domain with filter headroom | 0603 or 0805, 1% metal film class | Low | Shortlisted |
| R2/R3 battery divider path | Precision resistor pair for battery scaling (10:1 placeholder ratio) | 1% tolerance minimum | Stable ADC scaling and calibration simplification | 0603 or 0805, 1% metal film class | Low | Shortlisted |
| F1 PV input fuse | Time-delay fuse, 10 A class, 5x25 format (match installed holder footprint) | DC voltage rating >= 63 V and time-current curve consistent with PV path/inrush policy | Protects front-end path before switch stage; holder is placed, fuse element still needs exact part lock | 5x25 holder footprint is the active mechanical constraint | Low | Shortlisted |
| D1 reverse-polarity element | Series Schottky rectifier, 60 V / 10 A class | Vr >= 60 V, If >= 10 A | Matches Rev 0 reverse-polarity strategy and the stated input envelope | TO-220 / power diode class | Medium | Shortlisted |
| D2 surge suppressor | TVS diode, 64 V standoff class (SMBJ/SMCJ family) | Standoff appropriate to 2S PV with transient clamp margin | Supports REQ-SAF-004 transient strategy | SMBJ or SMCJ class | Low | Shortlisted |

## 3. Open Selection Items Before Hard Part Lock

1. Confirm exact Q1 and D3 thermal dissipation with switching frequency target and expected duty range.
2. Confirm L1 value using ripple target after final PWM frequency is fixed on STM32G431 control path; keep live schematic `L2` unless control-loop or thermal evidence requires a different inductance.
3. Confirm resistor divider absolute values against final ADC front-end filtering and sample timing.
4. Close Q-001 to finalize current-sense element class and any fuse-current refinements.
5. Lock the exact 5x25 fuse element part number with final blow characteristic + voltage rating for the selected holder footprint.

## 3.2 Q4 Lock Note (2026-07-28)

- Q4 for the PMOS-style PV input switch path is now locked to HSBA0119 (LCSC C53244070).
- Selection basis used in-session: Vds -100 V class, Vgs +/-20 V class, and Rds(on),typ about 23 mOhm.
- Follow-up still required: confirm worst-case (not typical-only) hot Rds(on) and thermal rise against intended sustained current envelope.

### 3.1 F1 Holder-Matched Rule (Locked)

Mechanical rule:
- Use 5x25 fuse elements to match the currently selected holder footprint.

Preference note:
- Bussmann MDL remains a personal preference family, but it is parked for this revision because it does not match the active 5x25 holder format.

Electrical lock checks:
1. Confirm selected 5x25 fuse has DC voltage rating >= 63 V for the stated 50 V worst-case input envelope.
2. Confirm time-delay behavior and current rating (10 A class baseline) remain consistent with startup/inrush behavior.

## 4. Pre-Routing Readiness Note

This shortlist is suitable for symbol-to-footprint refinement and layout planning. It is not yet a procurement lock BOM.

- Allowed now: footprint assignment, placement experiments, thermal-zone planning.
- Blocked until open items close: final MOSFET/diode exact PN, final inductor value lock, and current-sense topology lock.

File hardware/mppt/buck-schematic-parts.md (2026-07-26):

# MPPT Buck Schematic Parts Checklist

Last updated: 2026-07-06
Owners: Phil + Copilot
Purpose: identify the functional parts and support circuits that need to appear in the first buck MPPT schematic draft.

## 1. PV Input and Protection

Required functional parts:
- PV input connector: 2-position pluggable terminal block, 5.08 mm pitch, 300 V / 16 A class
- Input fuse: 10 A slow-blow fuse or fuse holder placeholder
- Reverse polarity protection element: series Schottky rectifier, 60 V / 10 A class
- TVS or surge suppression device: 48 V to 54 V TVS diode, SMBJ/SMCJ class
- Input filter capacitor bank: 2 x 10 uF / 63 V X7R plus 100 nF / 63 V
- Optional common-mode or differential filtering placeholder if EMI mitigation is needed later

Placement note:
- Use these as the first symbols placed on Sheet 1 before any buck switch-stage symbols are added.

Required notes:
- ASSUME: 2S Renogy panel baseline
- SAFETY: PV reverse polarity ownership
- SAFETY: PV transient suppression ownership
- VERIFY: worst-case cold Voc margin against all front-end parts

Recommended sheet-order summary:
- J1 connector -> F1 fuse -> D1 reverse diode -> D2 TVS -> C1/C2/C3 input caps

## 2. Buck Power Stage

Required functional parts:
- High-side buck switching MOSFET
- Freewheel path element: diode for asynchronous buck or low-side MOSFET for synchronous buck
- Buck inductor
- Switching-node snubber placeholder
- Input decoupling capacitors near switching loop
- Output capacitor bank

Required notes:
- DECISION: synchronous vs asynchronous implementation if not yet locked
- VERIFY: switch voltage rating margin
- VERIFY: inductor ripple-current target
- VERIFY: thermal observation point near switch and inductor

## 3. Charger Control and Drive

Required functional parts:
- MPPT controller or control IC placeholder
- Gate driver path if controller cannot drive power switch directly
- Bootstrap or driver support parts if required by selected approach
- Soft-start / compensation / timing network placeholders
- UVLO and enable boundary

Required notes:
- DECISION: DEC-005 controller partition still open
- VERIFY: startup behavior under weak-sun conditions
- VERIFY: UVLO/dropout strategy for low-irradiance headroom cases

## 4. Output and Battery Interface

Required functional parts:
- Charger output connector or battery interface boundary
- Output current sense element
- Optional output disconnect / reverse-current blocking placeholder if architecture needs it
- Main fuse handoff note to battery-domain protection

Required notes:
- ASSUME: 15A continuous planning bound until Q-001 closes
- SAFETY: battery fuse ownership handoff
- VERIFY: output current path and return path are explicit

## 5. Sensing and Telemetry

Required functional parts:
- PV voltage sense divider/filter
- PV current sense path
- Battery voltage sense divider/filter
- Battery current sense path
- Power-stage temperature sensor
- Board/control temperature sensor
- UART logging header or debug connector placeholder

Required notes:
- VERIFY: all required sense signals map to REQ-TEL-002
- VERIFY: serial logging path exists for first bring-up

## 6. First-Draft Minimum Part Categories

Minimum categories that must exist in the first schematic even if exact part numbers are TBD:
- Connector
- Fuse / protection placeholder
- TVS / suppression placeholder
- MOSFET / diode switching path
- Inductor
- Input capacitors
- Output capacitors
- Sense resistor or current-sense element
- Voltage divider networks
- Temperature sensors
- Controller / gate-drive placeholder
- Debug / serial header

## 7. Exit Gate

- Every category above appears in the schematic as a real symbol or an explicit placeholder block.
- Every safety-critical omission is called out as a visible note, not left implicit.
- Every unresolved part-class decision is referenced back to the decisions log.

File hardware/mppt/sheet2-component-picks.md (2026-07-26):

# Sheet 2 Component Picks (Buck Power Stage)

Last updated: 2026-07-20
Owners: Phil + Copilot
Scope: choose first-pass components for Sheet 2 only (power stage), so symbols can be placed now.

## 1. First-Pass Picks

| Ref | Function | First-Pass Part Class | Starter Electrical Target | Placement Intent |
|---|---|---|---|---|
| Q1 | High-side buck switch | N-channel MOSFET | Vds >= 40V, Id >= 30A, low Rds(on) class | Place close to D3 and L1 around switch node |
| D3 | Freewheel path (asynchronous) | Schottky diode | Vr >= 60V, If(avg) >= 10A, surge-capable package | Place tight to Q1 source and return path |
| L1 | Buck inductor | Shielded power inductor | 33uH to 68uH, Isat >= 15A, low DCR class | Place directly after switch node toward output caps |
| C4 | Input decoupling #1 | Ceramic capacitor | 4.7uF to 10uF, 63V, X7R | Place very close to Q1 drain-source loop |
| C5 | Input decoupling #2 | Ceramic capacitor | 1uF to 4.7uF, 63V, X7R | Place beside C4 for HF support |
| C6 | Output bulk #1 | Low-ESR electrolytic/polymer | 100uF to 220uF, >=35V | Place close to L1 output and CHG_OUT return |
| C7 | Output bulk #2 | Low-ESR electrolytic/polymer or ceramic mix | 47uF to 220uF, >=35V | Place parallel to C6 near output handoff |
| R1 | Snubber resistor (placeholder) | Thick-film resistor | 5 ohm to 22 ohm, >=0.25W | Keep adjacent to Q1/switch node |
| C8 | Snubber capacitor (placeholder) | Ceramic capacitor | 470pF to 2.2nF, 63V NP0/X7R | In series with R1, close to switch loop |

## 2. Symbol Placement Sequence

1. Place Q1, D3, L1 first and connect `MPPT_SW_NODE` path.
2. Place C4/C5 next and connect to `PV_IN_POS` and `PWR_NEG`.
3. Place C6/C7 on `CHG_OUT_POS` and `PWR_NEG`.
4. Place R1/C8 snubber placeholder from `MPPT_SW_NODE` to `PWR_NEG`.

## 3. Nets To Use

- `PV_IN_POS`
- `PWR_NEG`
- `MPPT_SW_NODE`
- `CHG_OUT_POS`
- `CTRL_PWM_MAIN`

## 4. Cleanup Note

- Rev 0 Sheet 2 uses `CTRL_PWM_MAIN` directly for Q1 drive.
- Do not carry forward any alternate gate label from the older control concept unless a future revision explicitly separates it.

## 4. Notes Before Part Lock

- These are placement-ready starter classes, not final procurement selections.
- Final value tuning (inductor, snubber, capacitor mix) will occur after controller and switching frequency are fixed.
- Rev 0 build lock: keep asynchronous freewheel path (D3) for this revision.
- Defer synchronous converter and dedicated gate-driver implementation to Rev 1.
- TI calculator guidance for the synchronous FET sizing pass points to roughly 30 A and 25.6 V Vds for this envelope, so the existing 40 V MOSFET set is acceptable here.
- U2 overvoltage shutdown is the primary high-input protection mechanism, so the FET selection does not need to chase a 60 V-class ceiling for this stage.

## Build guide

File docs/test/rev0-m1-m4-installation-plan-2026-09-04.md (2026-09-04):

# Rev 0 M1-M4 Installation Plan

Date: 2026-09-04
Scope: unpowered installation and passive verification only

## Approved Assembly Substitution

The available devices are ten Infineon `BSC030N04NSGATMA1` N-channel MOSFETs. This replaces the original `IPZ40N04S5L4R8ATMA1` selection for M1-M4.

Official Infineon data identifies `BSC030N04NS G` as:

- `PG-TDSON-8-1` / SuperSO8 5x6 package, 5.15 mm x 5.9 mm, 1.27 mm terminal pitch.
- 40 V maximum drain-source voltage.
- 3 mOhm maximum on-resistance at 10 V gate drive.
- 46 nC typical total gate charge at 10 V.
- Pads 1-3 source, pad 4 gate, and the exposed power pad drain.

The manufactured Rev 0 PCB uses the matching `Package_TO_SOT_SMD:TDSON-8-1` geometry and electrical mapping: pads 1-3 source, pad 4 gate, and large pad 5 drain. The LM51772-Q1 has a 2 A gate-driver class, so the 46 nC gate charge does not block physical installation. Rev 0 has no series gate resistors; ringing, transition time, dead time, and thermal behavior remain first-switch validation items.

This approval covers fitment and unpowered verification only. It does not authorize applying PV, an output source, a battery, a panel, a load, or any switching command.

## Bridge Mapping

| Position | Drain | Source | Gate |
|---|---|---|---|
| M1 | `PV_IN_POS` | `SW_1` | `HO1` |
| M2 | `SW_1` | `PWR_NEG` | `LO1` |
| M3 | `SW_2` | `PWR_NEG` | `LO2` |
| M4 | output rail | `SW_2` | `HO2` |

## Entry Gate

- [x] Exact candidate identified as `BSC030N04NSGATMA1`.
- [x] Ten matching devices available.
- [x] Package family and PCB land pattern match.
- [x] Board sources removed and U6 rails reported below 0.1 V.
- [x] USB, ST-LINK, PV, output, battery, panel, inverter, and AC leads visibly removed immediately before soldering.
- [x] U2 and U5 bypass jumpers identified and left unchanged.
- [x] M1-M4 pads confirmed clean, flat, and free of bridges before installation.

## Loose-Part Check

Test one device before applying paste:

1. Confirm the package orientation mark is visible.
2. Verify gate-to-source and gate-to-drain do not show a low resistance in either polarity.
3. In diode mode, verify one body-diode polarity between source and drain and blocking in the reverse polarity after discharging the gate to source.
4. Reject the lot for mixed markings, a gate short, drain-source conduction in both polarities, or inconsistent readings among sampled parts.

Record the meter model and readings. Do not infer a device failure from a slowly changing resistance caused by gate or meter charging; short gate to source before repeating the drain-source test.

## Installation Sequence

Install and inspect one device at a time in this order: M2, M3, M1, M4.

For each position:

1. Align the device orientation mark with PCB pad 1. Do not use neighboring component orientation as the reference.
2. Reflow with the minimum heat and time needed for complete wetting. Avoid lateral pressure that can bridge the large drain pad to source or gate pads.
3. Allow the board to cool before measuring.
4. Inspect pads 1-4 under magnification. Confirm pad 4 is not bridged to pads 1-3 or the exposed drain pad.
5. Check gate-to-source and gate-to-drain for a low-resistance short.
6. Check the expected body-diode polarity across that half-bridge device.
7. Check that the newly populated switch node is not a near-short to either adjacent power rail.
8. Stop on any ambiguous orientation, solder bridge, lifted pad, abnormal diode reading, or near-short. Do not install the next device until the result is resolved.

## Final Passive Gate

After all four devices are fitted and the board is cool:

- [x] M1-M4 orientation marks match their pad-1 indicators.
- [x] `HO1-SW_1`, `LO1-PWR_NEG`, `LO2-PWR_NEG`, and `HO2-SW_2` have no gate short.
- [x] `PV_IN_POS-SW_1`, `SW_1-PWR_NEG`, `SW_2-PWR_NEG`, and output-to-`SW_2` show the expected body-diode polarity and block in reverse after gate discharge.
- [x] `PV_IN_POS-PWR_NEG` is not a near-short.
- [x] Output-to-`PWR_NEG` is not a near-short.
- [x] `SW_1` and `SW_2` are not shorted together.
- [x] U2/U5 bypasses and the PGND-to-PWR_NEG jumper were not disturbed.
- [x] Both board sides and all four joints are photographed.

Installation result 2026-09-04: M2 and M3 were installed and passed visual, gate-short, body-diode, and switch-node resistance checks. M1 then passed the corresponding high-side checks, followed by M4. Final qualitative resistance checks found no near-short from input or output to `PWR_NEG` and no short between `SW_1` and `SW_2`. All four body diodes conducted in the expected direction and blocked when reversed after gate discharge. All orientation marks and visible joints passed magnified inspection. U2/U5 bypasses and the PGND-to-PWR_NEG jumper remained unchanged. Photographs covering both board sides and all four M1-M4 joints were captured. The installation-only gate is complete; this does not authorize power application or switching.

## Stop Point

Remove all meter leads after the final passive checks and leave the board unpowered. The next operation requires a separate first-switch entry plan covering protection-path disposition, output sink/preload, firmware state machine and limits, oscilloscope connections, bootstrap behavior, dead time, source limits, and immediate stop thresholds.

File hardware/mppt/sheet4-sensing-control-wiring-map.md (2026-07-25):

# Sheet 4 Sensing and Control Wiring Map

Last updated: 2026-07-20
Owners: Phil + Copilot
Scope: define first-pass, implementation-ready zone plan for sensing and control I/O in the single-sheet KiCad schematic, starting with voltage and current measuring circuits.

## 1. Purpose

Start Zone D (Sheet 4 intent) with stable net boundaries and placeholders, beginning with voltage and current measuring circuits and now adding a provisional STM32G431 pin-map baseline.

## 2. First-Pass Symbol Set

| Ref | Function | First-Pass Type | Notes |
|---|---|---|---|
| U_CTRL | Control placeholder block | Generic control symbol or hierarchical placeholder | Use as owner for control and telemetry nets; map signals to STM32G431 candidates in Section 8 |
| TP_PV_V | PV voltage sense tap | Test point | Optional but recommended |
| TP_PV_I | PV current sense tap | Test point | Optional but recommended |
| TP_BAT_V | Battery voltage sense tap | Test point | Optional but recommended |
| TP_BAT_I | Battery current sense tap | Test point | Optional but recommended |
| TH_PWR | Power thermal sensor placeholder | NTC or sensor placeholder symbol | Bind to SENSE_TEMP_PWR |
| TH_BOARD | Board thermal sensor placeholder | NTC or sensor placeholder symbol | Bind to SENSE_TEMP_BOARD; U7 is the current board-temp device placeholder |
| U8 | Display module | 0.96in OLED I2C module | Connect to I2C CLK/DATA, CTRL_3V3, and GND |
| SW1-SW5 | Navigation button pad | 5x tactile switch | Up/down/left/right/enter user input pad |
| R54-R58 | Navigation pull resistors | 10k resistor set | Pull button nets to CTRL_3V3 for active-low behavior |
| SW_RST | STM32 reset button | Tactile switch | Momentary pull of reset net low for recovery/debug |
| Y1 | STM32 HSE crystal | 2-pin crystal | External high-speed reference for deterministic timing |
| CxH1/CxH2 | HSE load capacitors | Capacitor pair | Crystal load capacitors to PWR_NEG near MCU pins |
| J_LOG | Serial logging header | 1x03 or 1x04 header | Include TX, RX, and return reference |
| U_PWR_CTRL | Control-rail regulator block | Wide-input buck + optional post-filter stage | Own `CTRL_SUPPLY_IN` to `CTRL_3V3` conversion per DEC-013 |
| J_USB_DBG | USB bench-power boundary | USB connector or 5V header placeholder | Bench fallback source for control rail when PV is absent |

## 2.1 First Build Priority

Start with the measurement circuits first:

1. PV voltage sense path.
2. PV current sense path.
3. Battery voltage sense path.
4. Battery current sense path.
5. Thermal sense placeholders.
6. Then connect U_CTRL, logging header, and control/fault placeholders.

## 3. Canonical Net Rules

Use these global nets exactly:

Power and boundary references:

- PV_IN_POS
- CHG_OUT_POS
- BAT_BUS_POS
- PWR_NEG
- CTRL_SUPPLY_IN
- USB_5V_IN
- CTRL_3V3
- CTRL_3V3A

Control and sensing nets:

- CTRL_PWM_MAIN
- CTRL_EN_CHG
- FAULT_OCP
- FAULT_OVP
- SENSE_PV_V
- SENSE_PV_I
- SENSE_BAT_V
- SENSE_BAT_I
- SENSE_TEMP_PWR
- SENSE_TEMP_BOARD
- UART_TX_LOG
- UART_RX_CFG
- BTN_UP_N
- BTN_DN_N
- BTN_LT_N
- BTN_RT_N
- BTN_ENT_N
- MCU_RST_N
- MCU_HSE_IN
- MCU_HSE_OUT

## 4. Minimal Connection Intent

1. U_CTRL outputs CTRL_PWM_MAIN and CTRL_EN_CHG.
2. U_CTRL inputs FAULT_OCP and FAULT_OVP (placeholder-safe if source not yet implemented).
3. TP_PV_V connects to SENSE_PV_V, sourced from a divider/tap on PV_IN_POS to PWR_NEG.
4. TP_BAT_V connects to SENSE_BAT_V, sourced from a divider/tap on BAT_BUS_POS to PWR_NEG.
5. TP_PV_I and TP_BAT_I connect to SENSE_PV_I and SENSE_BAT_I placeholders (final current-shunt topology deferred).
6. TH_PWR and TH_BOARD connect to SENSE_TEMP_PWR and SENSE_TEMP_BOARD.
7. J_LOG provides UART_TX_LOG, UART_RX_CFG, and PWR_NEG reference.
8. U_PWR_CTRL converts `CTRL_SUPPLY_IN` to `CTRL_3V3` and feeds MCU supply pins.
9. `USB_5V_IN` enters only through protected bench-fallback path; no direct backfeed into USB boundary is allowed.
10. Navigation buttons are active-low: each `BTN_*_N` net is pulled up to `CTRL_3V3` and closes to `PWR_NEG` on press.
11. `MCU_RST_N` is pulled up to `CTRL_3V3` and is momentarily shorted to `PWR_NEG` by reset switch.
12. `MCU_HSE_IN` / `MCU_HSE_OUT` are a short, local crystal loop with matched load-cap grounding to `PWR_NEG`.

Current schematic state note:
- The drawn schematic presently uses U2 as the provisional `CTRL_3V3` owner.
- U4 now references `CTRL_SUPPLY_IN` and represents the intended wide-input candidate path, but it is not yet wired as the active `CTRL_3V3` source.
- Q-004 exists to decide which block becomes the actual Rev 0 control-rail owner.

## 5. Required On-Zone Notes

Add these notes in Zone D:

- ASSUME: U_CTRL remains a schematic owner placeholder until exact STM32G431 package and footprint are locked.
- DECISION: DEC-005 is now closed to STM32G431 for Rev 0, with revision-flexible re-evaluation allowed in future revs.
- DECISION: DEC-013 fixes Rev 0 control-power architecture to single wide-input buck primary path with PV-first runtime behavior and protected USB bench fallback.
- VERIFY: Sense divider scaling and ADC range compatibility must be checked before part lock.
- VERIFY: Current-sense element placement and Kelvin routing strategy required before PCB routing.
- VERIFY: Startup checks must pass for PV-only and USB-only bench modes before pre-routing gate closure.

## 6. Gate Constraints

- DEC-005 is closed for Rev 0 baseline (STM32G431), but exact package/pin lock still requires variant verification.
- Q-001 affects current-sense full-scale targets; keep current-sense component values provisional.
- Maintain global-label consistency across all zones on the single-sheet schematic.

## 7. Done Criteria For First Pass

- All Zone D nets exist as global labels and are connected to explicit placeholder owners.
- UART logging boundary is present with a return reference.
- Thermal sense placeholders exist for both power-stage and board-level monitoring.
- No duplicate local/global names on canonical nets.

## 8. STM32G431 Rev 0 Interface Mapping (Audited 2026-07-19)

Purpose:
- Replace the earlier first-pass budget with the live U1 wiring audit from the current schematic.
- Normalize MCU-facing nets to canonical names where the function is unambiguous.

| Status | Zone D Net | STM32G431 Role | Live Pin | Notes |
|---|---|---|---|---|
| Canonicalized | SENSE_PV_V | ADC | PA4 | Live schematic renamed from `V_in_ADC`; sourced from the PV divider on `/PV_IN_POS_FUSED`. |
| Legacy hold (role clarified) | V_in_ON | GPIO output to legacy gate-control path | PA5 | Confirmed as control-only path (PA5 -> R41 -> Q2 gate net), not an ADC channel. Keep name unchanged until the U2/Q2 legacy path is either removed or intentionally retained. |
| Canonical | SENSE_TEMP_PWR | ADC | PA6 | Power-stage thermal input. |
| Canonical | SENSE_TEMP_BOARD | ADC | PA7 | Board thermal input. |
| Canonicalized | CTRL_PWM_MAIN | TIM1 PWM / gate-drive command | PA8 | Live schematic renamed from `V_out _on`; this is the MCU-side gate-drive command path. |
| Canonicalized | UART_TX_LOG | USART1_TX | PA9 | Bridge-side label canonicalized from `TXD`. |
| Canonicalized | UART_RX_CFG | USART1_RX | PA10 | Bridge-side label canonicalized from `RXD`. |
| Canonical (verified 2026-07-21) | FAULT_OCP | GPIO in / EXTI | PB0 | Confirmed in fresh netlist export: `FAULT_OCP` now includes U1 PB0. |
| Canonical (verified 2026-07-21) | FAULT_OVP | GPIO in / EXTI | PB1 | Confirmed in fresh netlist export: `FAULT_OVP` now includes U1 PB1. |
| Canonical | CTRL_EN_CHG | GPIO out | PB5 | Charger enable control. |
| Canonical | I2C DATA | I2C SDA | PB6 | Used for LM51772 configuration/control in the current schematic. |
| Canonical | I2C CLK | I2C SCL | PB7 | Used for LM51772 configuration/control in the current schematic. |

Reserved pins:
- PA13: SWDIO
- PA14: SWCLK
- PG10/~RST: hardware reset

Deferred pin-allocation items:
- PA0, PA1, PA2, and PA3 are still free in the live schematic and are the best candidates for the missing canonical measurement channels (`SENSE_BAT_V`, `SENSE_PV_I`, `SENSE_BAT_I`) once those sensing front ends are finalized.
- PC13 is the preferred landing point for `U6_FLT` once the pull-up is added.
- PF0-OSC_IN and PF1-OSC_OUT are reserved for the external HSE crystal network (`MCU_HSE_IN`, `MCU_HSE_OUT`) in the current STM32 support implementation checklist.
- PG10/~RST is reserved for the external reset net (`MCU_RST_N`) and should include push-button access plus debug-header access.
- U7 is currently intended as the board temperature sensor, placed near the warmest representative board spot, and should be tied to `SENSE_TEMP_BOARD`.
- U8 is the display module and should remain on the I2C control bus with the control rail and ground return.

Notes:
- This audited table supersedes the older provisional pin budget as the practical Rev 0 reference.
- Canonical cleanup is intentionally limited to MCU-facing and boundary-facing nets in this pass. U6-local helper nets such as `_OUTPUT Feedback`, `_Undervoltage Feedback`, `_CSA_2`, and `_CSB_2` still need a separate cleanup decision if you want them renamed too.
- Historical note: the 2026-07-20 recovery handoff still showed `PB0` and `PB1` as `no_connect`; this was closed by the 2026-07-21 netlist export.

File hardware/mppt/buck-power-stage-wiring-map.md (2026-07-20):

# Buck Power Stage Wiring Map (Sheet 2)

Last updated: 2026-07-07
Owners: Phil + Copilot
Purpose: define exact first-pass symbol connectivity for the buck conversion stage in KiCad.

## 1. Symbols

- Q1: High-side buck switch MOSFET
- D3: Freewheel diode (asynchronous first pass)
- L1: Buck inductor
- C4: Buck input decoupling capacitor #1
- C5: Buck input decoupling capacitor #2
- C6: Buck output capacitor #1
- C7: Buck output capacitor #2
- R1/C8: Snubber placeholder across switch node

Component selection reference:
- See `sheet2-component-picks.md` for first-pass part classes and starter targets.

## 2. Net Naming

Use these nets on Sheet 2:
- PV_IN_POS
- PV_IN_NEG
- MPPT_SW_NODE
- CHG_OUT_POS
- CHG_OUT_NEG

Control and measurement placeholders for this sheet:
- CTRL_PWM_MAIN
- SENSE_PV_I

Controller-drive rule for this sheet:
- `CTRL_PWM_MAIN` is the only live controller drive input for Q1 in Rev 0.
- Do not reintroduce any old MOSFET-era gate-control label or alternate drive net on this sheet.

## 3. Connectivity Map

1. Q1 drain -> `PV_IN_POS`
2. Q1 source -> `MPPT_SW_NODE`
3. Q1 gate -> `CTRL_PWM_MAIN`
4. Q1 source reference return -> `PV_IN_NEG`

5. D3 cathode -> `PV_IN_NEG`
6. D3 anode -> `MPPT_SW_NODE`

7. L1 input -> `MPPT_SW_NODE`
8. L1 output -> `CHG_OUT_POS`

9. C4 positive -> `PV_IN_POS`
10. C4 negative -> `PV_IN_NEG`

11. C5 positive -> `PV_IN_POS`
12. C5 negative -> `PV_IN_NEG`

13. C6 positive -> `CHG_OUT_POS`
14. C6 negative -> `CHG_OUT_NEG`

15. C7 positive -> `CHG_OUT_POS`
16. C7 negative -> `CHG_OUT_NEG`

17. CHG_OUT_NEG -> `PV_IN_NEG` (single-point power return tie for first pass)

18. R1 in series with C8 across `MPPT_SW_NODE` to `PV_IN_NEG` (snubber placeholder)

## 4. Placement Intent

- Place Q1, D3, and L1 as a compact triangle around `MPPT_SW_NODE`.
- Place C4/C5 close to Q1 drain/source loop.
- Place C6/C7 close to L1 output and return path.
- Keep the snubber placeholder physically adjacent to Q1 and switch node.

## 5. Sheet Notes To Add

- ASSUME: asynchronous buck for first pass (freewheel diode path)
- DECISION: Rev 0 remains asynchronous; synchronous implementation is a Rev 1 architecture change.
- DECISION: `CTRL_PWM_MAIN` is the only controller drive path for Q1 in Rev 0.
- VERIFY: Q1 voltage class covers worst-case cold Voc margin
- VERIFY: freewheel diode reverse-voltage and current margin are sufficient
- VERIFY: switch loop and output loop are compact and obvious

## 6. Handoff To Sheet 3/4

Export to next sheets:
- `CHG_OUT_POS`
- `CHG_OUT_NEG`
- `SENSE_PV_I` placeholder from current-sense strategy
- `CTRL_PWM_MAIN` from controller sheet

This keeps power conversion and control boundaries explicit while allowing later refinement.

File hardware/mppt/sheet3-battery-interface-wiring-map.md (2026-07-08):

# Sheet 3 Battery Interface Wiring Map

Last updated: 2026-07-08
Owners: Phil + Copilot
Scope: define first-pass, placement-ready wiring intent for Sheet 3 battery interface and protection handoff.

## 1. Purpose

Provide a minimal, safe Sheet 3 implementation path that can start now while Q-001 remains open.

## 2. Symbol Set For First Pass

| Ref | Function | First-Pass Type | Notes |
|---|---|---|---|
| J2 | Battery connector boundary | 2-pin terminal or battery connector symbol | Interface handoff to pack/BMS domain |
| F2 | Main battery fuse boundary | Fuse symbol placeholder | Final rating depends on Q-001 closure |
| TP_BAT_POS | Positive bus test point | Test point symbol | Optional but recommended for bring-up |
| TP_BAT_NEG | Negative bus test point | Test point symbol | Optional but recommended for bring-up |
| NOTE_BAT_BOUND | Boundary note | Text note | Capture assumptions and safety ownership |

## 3. Net Handoff Rules

Use these nets exactly as named:

- CHG_OUT_POS enters Sheet 3 from Sheet 2.
- PWR_NEG is the shared return net across all zones.
- BAT_BUS_POS leaves Sheet 3 toward battery and distribution domains.

Connection intent:

1. CHG_OUT_POS -> F2 -> BAT_BUS_POS.
2. PWR_NEG -> J2 pin 2 (direct return path).
3. J2 pin 1 -> BAT_BUS_POS.
4. TP_BAT_POS on BAT_BUS_POS and TP_BAT_NEG on PWR_NEG.

## 4. Required On-Sheet Notes

Add these notes on Sheet 3:

- ASSUME: 15A continuous planning bound until Q-001 is closed.
- SAFETY: Main battery fuse F2 must be physically placed near battery positive terminal in layout.
- VERIFY: Confirm fuse rating and I2t against final BMS continuous and peak current limits.
- VERIFY: Confirm connector current and creepage/clearance margins for battery domain.

## 5. Current Gate Constraints

- Q-001 remains open, so do not lock final F2 rating yet.
- DEC-005 does not block Sheet 3 boundary placement.
- Keep Sheet 3 focused on power boundary and protection handoff only.

## 6. Done Criteria For Sheet 3 First Pass

- J2 and F2 are placed and wired with explicit forward and return paths.
- BAT_BUS_POS and PWR_NEG are present as canonical battery boundary nets.
- Assumption and safety notes are visible on the sheet.
- No ambiguous duplicate names on the battery boundary nets.

## 7. Status

- 2026-07-08: First-pass Sheet 3 boundary wiring completed.
- Keep F2 rating provisional until Q-001 closure.

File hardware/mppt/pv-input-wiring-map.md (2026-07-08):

# PV Input Wiring Map (Sheet 1)

Last updated: 2026-07-07
Owners: Phil + Copilot
Purpose: define exact first-pass symbol connectivity for the PV input boundary in KiCad.

## 1. Symbols

- J1: PV input connector (2-pin)
- F1: Input fuse
- D1: Series Schottky reverse-polarity diode
- D2: TVS diode
- C1: Input bulk capacitor #1
- C2: Input bulk capacitor #2
- C3: High-frequency bypass capacitor

## 2. Net Naming

Use these power nets for Sheet 1:
- PV_IN_POS_RAW
- PV_IN_NEG
- PV_IN_POS_FUSED
- PV_IN_POS

Note:
- `PV_IN_POS` and `PV_IN_NEG` are the handoff nets into the buck stage.

## 3. Connectivity Map

1. J1 pin 1 -> `PV_IN_POS_RAW`
2. J1 pin 2 -> `PV_IN_NEG`

3. F1 in -> `PV_IN_POS_RAW`
4. F1 out -> `PV_IN_POS_FUSED`

5. D1 anode -> `PV_IN_POS_FUSED`
6. D1 cathode -> `PV_IN_POS`

7. D2 cathode -> `PV_IN_POS`
8. D2 anode -> `PV_IN_NEG`

9. C1 positive -> `PV_IN_POS`
10. C1 negative -> `PV_IN_NEG`

11. C2 positive -> `PV_IN_POS`
12. C2 negative -> `PV_IN_NEG`

13. C3 positive -> `PV_IN_POS`
14. C3 negative -> `PV_IN_NEG`

## 4. Placement Intent

- Place J1 and F1 at the board-entry edge.
- Place D1 immediately after F1 in the positive path.
- Place D2 as a shunt between `PV_IN_POS` and `PV_IN_NEG` close to D1 output.
- Place C1/C2/C3 close to the D1 output and the buck-stage input handoff.

## 5. Sheet Notes To Add

- SAFETY: PV boundary protection ownership (F1/D1/D2)
- ASSUME: 2S Renogy panel baseline
- VERIFY: worst-case cold Voc margin vs part ratings
- DECISION: DEC-012/Q-003 ideal-diode upgrade unresolved before PCB routing

## 6. Handoff To Sheet 2

Export only these two nets to the buck power-stage sheet:
- `PV_IN_POS`
- `PV_IN_NEG`

This keeps the boundary clean and prevents accidental bypass of input protection.

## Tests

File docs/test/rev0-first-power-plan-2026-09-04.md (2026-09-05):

# Solar Project 200W - Rev 0 Populated-Bridge Staged First-Power Plan

Drafted: 2026-09-04
Status: DRAFT - NOT REVIEWED - NOT AUTHORIZED FOR EXECUTION
Applies to: recovered Rev 0 board with M1-M4 (`BSC030N04NSGATMA1`) installed per `rev0-m1-m4-installation-plan-2026-09-04.md`

This plan is documentation only. No stage may be executed until this plan is reviewed and the stage's entry gate is explicitly signed off in the bench record. Drafting and execution are separate sessions by rule.

## 1. Scope and Structure

The populated bridge changes the hazard model: crossing U6 `EN_UVLO` rising threshold with M1-M4 fitted can start real converter switching, which was impossible during all prior powered work. This plan therefore separates:

- **FP0** - review, bypass disposition, and pre-power passive recheck (unpowered).
- **FP1** - control power only over USB (no PV; U6 unpowered).
- **FP2** - below-UVLO PV static (U6 alive on I2C, switching impossible).
- **FP4** - first controlled converter start (switching). **Blocked**: defined here only as an entry gate and hazard bound; it requires its own reviewed authorization and may not be run in the same session as FP0-FP2.
- **FP3** - above-UVLO PV static with U6 held disabled (switching inhibited by EN_UVLO hold-low), performed **after** FP4 rather than before it (see Section 1a).

Each stage has an entry gate, bounded conditions, stop thresholds, and a recorded pass/fail result. A stage pass never implies the next stage is authorized.

## 1a. Stage Sequencing Decision (Review 2026-09-04)

Review decision: FP3 is reordered to run after FP4 passes, not before it. Rationale recorded from the board owner: the board has already absorbed significant rework stress, and the priority is proving the converter switches correctly before investing further attended bench time in a static-only EN_UVLO hold-low characterization step. Consequence accepted by this reordering: the first time `EN_UVLO` is allowed to cross its rising threshold with the bridge populated (in FP4), U6 will attempt to start switching directly — there is no intermediate proof of "above-UVLO but not switching" before that first switching attempt. This makes the FP4 entry gate (Section 15) carry the full weight that FP3 would otherwise have partly absorbed; FP4's bounded low-VIN/low-current/short-duration/preloaded conditions (Sections 8 and 11) are the compensating control for removing that intermediate step. FP3, if still performed later, becomes a post-FP4 static characterization exercise rather than a pre-switching safety gate.

## 2. Standing Prohibitions (all stages)

- No real panel, battery, inverter, AC wiring, or uncontrolled load.
- No unattended operation while any source is connected.
- Keep `PA8`, `PB5`, and legacy `PA5` low. Never drive `PB11` (tied to `PWR_NEG` on Rev 0).
- No LM51772 register writes. Never access `CLEAR_FAULTS` at `0x03`.
- SWD only via ST-LINK serial `B55B5A1A0000000020AFF501`; verify Device ID `0x469`, STM32G47x/G48x family, 512 KB NVM, plausible target voltage before every operation. Serial only via CP210x `USB\VID_10C4&PID_EA60\0001` on COM5, 115200 8N1. Stop on any identity mismatch; never select another COM port.
- No ground-referenced oscilloscope lead on `SW_1`, `SW_2`, `HO1`, `HO2`, `HB1`, or `HB2`.
- The prior 6.49 V / 20 mA authorization predates M1-M4 installation and is void; each stage below re-authorizes its own source point.

## 3. Item 1 - F1 / U2 / U5 Bypass Disposition

Current state: a jumper spans F1 (input fuse defeated); U2 (input reverse-blocking `BSC112N06LD` common-source pair) and U5 (output-path equivalent) are jumpered because of the Rev 0 invalid gate-drive defect. The R31-pad-2 to R32-pad-2 `PGND`-to-`PWR_NEG` jumper is a required Rev 0 repair and stays.

Disposition for this plan:

- **Accepted for FP0, FP1, FP2, FP4, and (if later performed) FP3**, under these compensating controls: isolated bench source, hard source current limit (the only overcurrent protection with F1 bypassed), attended operation, and stop thresholds below.
- **U5 bypass consequence**: the output rail has no reverse blocking. Therefore no output-side source of any kind (battery, second supply, charged capacitor bank) may be connected in any stage of this plan. Output connections are limited to a passive resistive preload or an electronic load in constant-resistance mode.
- **FP4 precondition**: before FP4, a reviewer must either (a) restore/rework F1, U2, and U5, or (b) record a written waiver stating why bench-only switching with bypasses is acceptable, with the source current limit and preload named as the substitute protection. Option (b) is acceptable only for the first bounded switching characterization; any battery/panel/inverter work requires (a). This waiver carries more weight than originally drafted because FP3's pre-switching static proof is no longer a prerequisite (Section 1a).

## 4. Item 2 - First-Stage Selection

The first powered stage is **FP1 control power only** (USB VBUS path, PV open). Rationale: it re-validates the control domain against the newly populated bridge with U6's power path completely unpowered, and it reuses the already-verified COM5/stage1 configuration. Below-UVLO PV (FP2) follows only after FP1 passes.

## 5. Item 5 - Firmware Image and Safe-State Proof

- Image: the currently flashed `stm32g4_rev0_stage1` bare-metal diagnostic firmware (source `firmware/bringup/baremetal/stm32g4_rev0_stage1.c`). No new image may be flashed as part of this plan; if a reflash becomes necessary, it is a stop-and-review event.
- Proof required at FP1, and re-checked at every later stage entry:
  1. Cold boot, then COM5 `status` must report `PA8_PWM=0 PB5_EN=0 PA5_LEGACY=0`.
  2. Press S1 reset, repeat `status`, same result. Repeat the boot/reset pair twice.
  3. DMM at the MOSFET footprints: M1 `HO1`-to-`SW_1`, M2 `LO1`-to-`PWR_NEG`, M3 `LO2`-to-`PWR_NEG`, M4 `HO2`-to-`SW_2` all ≤ 0.1 V.
- Read-only U6 access is limited to `STATUS_BYTE` (`0x78`) via the stage1 UART path or `firmware/scripts/rev0-openocd-u6-status.ps1` (which saves/restores GPIOB and resumes the MCU).

### 5.1 FP1 SWD Identity Verification (2026-09-04)

STM32CubeProgrammer CLI, read-only `-c port=SWD` connect (no flash/memory write): ST-LINK SN `B55B5A1A0000000020AFF501` (matches approved), Device ID `0x469` (matches), Device name `STM32G47x/G48x/G414` (matches), NVM size 512 KBytes (matches), target voltage 3.23 V (plausible for `CTRL_3V3`). All four required identity checks pass. Two earlier connection failures (OpenOCD, multiple speeds, with and without reset-assert; a first CubeProgrammer attempt) are now attributed to the board not actually being powered during those attempts, not a hardware SWD fault.

### 5.2 FP1 Safe-State Proof (2026-09-04, in progress)

COM5 `status` results, read-only:

| Check | Result |
|---|---|
| Cold boot | `STATUS OCP=1 OVP=0 PA8_PWM=0 PB5_EN=0 PA5_LEGACY=0` — matches required |
| S1 reset #1 | `STATUS OCP=1 OVP=0 PA8_PWM=0 PB5_EN=0 PA5_LEGACY=0` — matches required |
| S1 reset #2 | `STATUS OCP=1 OVP=0 PA8_PWM=0 PB5_EN=0 PA5_LEGACY=0` — matches required |

Cold boot plus both required reset cycles pass with an identical, matching safe-state result. DMM at the MOSFET footprints: `HO1`-to-`SW_1` (M1), `LO1`-to-`PWR_NEG` (M2), `LO2`-to-`PWR_NEG` (M3), `HO2`-to-`SW_2` (M4) all read 0 V — pass.

**FP1 status: PASSED.** SWD identity confirmed (5.1), safe-state proof confirmed across cold boot and two reset cycles with all four gate outputs at 0 V (5.2). FP2 (below-UVLO PV static) is authorized to begin.

### 5.3 FP2 Attempt and Abort (2026-09-04) - UNRESOLVED OPEN FINDING

FP2 was attempted at PV 5.0 V / 20 mA current limit. Input current stayed below 1 mA and `EN_UVLO` read 1.0263 V (both within bounds), but `HO1`-`SW_1` and `HO2`-`SW_2` initially read 4.31 V and `LO1`/`LO2`-to-`PWR_NEG` read 4.77 V — all far above the 0.1 V stop threshold. **Abort executed per Section 14**: source disconnected, all bench nodes confirmed ≤0.12 V after bleed-off.

On re-inspection after the abort, with the PV source disconnected: `HO1`/`HO2` read 0 V (as expected), but `LO1`/`LO2`-to-`PWR_NEG` still read 4.77 V with real drive strength — a 10 kΩ load only pulled it to 4.11 V (a floating/capacitively-coupled node would collapse toward 0 V under this load; this did not). Direct measurement at U6 `VCC2` (pin 29) showed the same behavior: a 10 kΩ load there also only pulled `VCC2` to 4.11 V. `LO1` is therefore riding directly on `VCC2`, not floating independently.

Root cause is **not confirmed**. The board's own bench history (`docs/test/rev0-low-energy-session-2026-08-30.md`) documents a residual, never-fully-isolated ~300 kΩ path from D8 pad 2 to U6 pin 29 (`VCC2`) after the D8-to-`VCC2` rework; D8 now sits on USB `VBUS`. This is a plausible explanation (`VBUS` backfeeding `VCC2` through that residual path while USB is connected) but was **not verified this session** — the decisive test (fully removing USB and confirming `VCC2` collapses) was not completed; board owner elected to stop pursuing this diagnostic for this session.

**Disposition:** FP2 is not passed. This finding blocks FP2 re-attempt, FP4, and FP3 until resolved: either (a) confirm `VCC2` fully collapses to near 0 V with USB and ST-LINK both physically disconnected, or (b) identify and close the actual backfeed path. A live gate-driver bias rail with real source impedance, present even with PV fully removed, is not an accepted precondition for any further powered stage on this plan.

### 5.4 FP4 Startup Attempt (2026-09-05) - NOT PASSED

The board owner determined that the earlier `LO1`/`LO2` observation tracks U6's internal `VCC2` driver domain and does not, by itself, establish external backfeed or unsafe switching. This interpretation is recorded as a working characterization decision; it does not establish a cause for the prior rail observation.

FP4 was then attempted with a Rigol DS1054 using two 10x probes with both ground clips at `PWR_NEG`: CH1 at `HO1`, CH2 at `SW_1`, and math CH1-CH2 for the high-side gate-source observation. At approximately 6.0 V input, switching began. The math trace showed a centered approximately 5-10 Vpp waveform in approximately 610 kHz cycle packets separated by approximately 200 ms. This arrangement is suitable only for the low-voltage first observation; it is not a differential-probe-quality measurement of switching-node overshoot.

With the original 200 ohm preload fitted, `CHG_OUT_POS` was approximately 0.986 V and the source entered current limit at approximately 229 mA when raised above 6.0 V. The preload was changed to 1 kohm without increasing the intended current-limit bound; `CHG_OUT_POS` then rose only to 1.36 V at approximately 266 mA input. The powered retry-state measurements were:

| Net / observation | Result |
|---|---|
| `PV_IN_POS_RAW` | 5.9767 V |
| `PV_IN_POS` | 5.961 V |
| `VCC1` | 5.0679 V |
| `VCC2` | 4.9250 V |
| `SW_1` (DMM DC) | 0.07 V |
| `LO1` (DMM DC) | 0.02 V |
| `CHG_OUT_POS` with 200 ohm preload | approximately 0.986 V |
| `CHG_OUT_POS` with 1 kohm preload | approximately 1.36 V |

The `PV_IN_POS_RAW` to `PV_IN_POS` difference was only approximately 16 mV, so the known input-front-end voltage drop is not the immediate cause at this operating point. The converter did not reach the confirmed approximately 12.83 V regulation target and the input source current-limited. **FP4 did not pass.** Do not increase the source-current limit while the retry/current-limit cause is unknown.

The planned follow-up is a brief, read-only state capture at approximately 5.98 V with the 1 kohm preload and a source limit no higher than 200 mA: record `FLT` to `PWR_NEG`, the source current-limit state, input current, and `CHG_OUT_POS`, then run `firmware/scripts/rev0-openocd-identify.ps1` followed by `firmware/scripts/rev0-openocd-u6-status.ps1`. Proceed only on the approved ST-LINK serial and expected target identity. The status script reads only U6 `STATUS_BYTE` at `0x78`, restores GPIOB state, and resumes the MCU. Never write `CLEAR_FAULTS` at `0x03`. Turn the source off and discharge immediately after this capture.

## 6. Item 6 - Oscilloscope Strategy

- Static stages (FP1-FP2, and FP3 if later performed): DMM measurements suffice; a ground-referenced scope probe is permitted only on `PWR_NEG`-referenced nets (`CTRL_3V3`, `VBUS`, `EN_UVLO`, `LO1`, `LO2`, `PV_IN_POS`).
- High-side gate-source (`HO1`-`SW_1`, `HO2`-`SW_2`) and `HB1`-`SW_1` / `HB2`-`SW_2` measurements require a differential probe or a battery-isolated scope. If neither is available, high-side dynamic V_GS is simply not measured; FP4 may not proceed without one.
- FP4 minimum scope set: CH1 differential on `HO1`-`SW_1` (or `HO2`-`SW_2` for the boost leg), CH2 ground-referenced on `SW_1` with a short ground spring (no long ground clip), single-shot capture armed before enabling the source.

## 7. Item 7 - Bootstrap Network

- `C22` 100 nF 100 V X7R 0805, `HB1` (U6 pin 25) to `SW_1`. `C23` 100 nF 100 V X7R 0805, `HB2` (U6 pin 31) to `SW_2`. Bootstrap diodes are internal to the LM51772.
- FP0 unpowered check: `HB1`-to-`SW_1` and `HB2`-to-`SW_2` must read as a capacitor (no short, no open drift to 0 Ω); record stabilized resistance.
- Expected static behavior (FP2/FP3): with the low-side devices off and no switching, HB-SW may sit anywhere from 0 V up to roughly VCC minus a diode drop depending on leakage; any HB-SW reading above ~6 V, or a gate output following HB, is a stop condition.
- Expected FP4 behavior: HB-SW charges to approximately VCC minus the internal diode drop during each low-side on-time; a first-start capture showing HB-SW collapsing below ~3 V during high-side on-time indicates bootstrap starvation and is a stop condition.

## 8. Item 8 - Dead Time, Startup Duty, Pulse Count, Run Duration

- Dead time is internal and adaptive in the LM51772 gate drivers; it is not firmware-adjustable. The STM32 does not gate individual pulses; once `EN_UVLO` crosses its rising threshold with valid VCC, U6 starts autonomously through its internal soft-start. Single-pulse testing is therefore **not available** on this hardware.
- The bounded substitute for FP4: lowest practical VIN just above the UVLO rising point (target 6.5 V, matching the previously characterized source point), hard source current limit (Section 11), passive preload fitted, first run duration ≤ 30 s attended, then source off and full discharge before inspection. Maximum cumulative first-session switching time: 5 minutes.
- Shoot-through protection relies entirely on U6's internal adaptive dead time; the compensating bound is the source current limit, which must be low enough that a full shoot-through event current-limits the source rather than the silicon (Section 11).

## 9. Item 9 - Missing Series Gate Resistors

Rev 0 has no series gate resistors; U6 drives the `BSC030N04NSGATMA1` gates (Qg ≈ 25 nC class, 40 V V_DS rating) directly.

Consequences to expect and bound:

- Fast edges → high dV/dt on `SW_1`/`SW_2`, ringing and overshoot with layout inductance. Stop threshold: any SW-node overshoot above **32 V** (80% of the 40 V rating) at the FP4 source point is an immediate stop; do not raise VIN to "see where it fails".
- Gate ringing → possible Miller-induced (Cdv/dt) turn-on of the off device. Watch low-side V_GS on CH2-class ground-referenced probing; any off-state gate excursion above ~1.5 V is a stop condition.
- EMI: expect it; it is not itself a stop condition at bench scale, but COM5/SWD instability during switching is (it indicates coupling into the control domain).
- Disposition: series gate resistors are a Rev 1 correction. FP4 accepts the risk only at the minimum-VIN, minimum-load, time-bounded point above.

## 10. Item 10 - Thermal and Ringing Observations

At each powered stage, log before/after (and at 60 s intervals during FP4, and during FP3 if later performed): M1-M4 cases, L2, R22 shunt, U6, the U2/U5 bypass jumpers, and the F1 jumper — by IR thermometer or calibrated touch. Stop thresholds: any component more than 15 °C above ambient in FP1-FP2 (nothing should be dissipating), or more than 40 °C above ambient in FP4 or FP3, or any odor, discoloration, or audible instability.

## 11. Items 3-4 - Source, Output, and Stop Thresholds per Stage

| Stage | Source and limit | Output side | Key stop thresholds |
|---|---|---|---|
| FP1 | USB VBUS only (single source rule for D8) | Open | VBUS current limiting, CTRL_3V3 outside 3.3 V ±5%, safe-state proof failure |
| FP2 | Isolated bench PV at **5.0 V / 20 mA**, raised from 0 V | Open | Input current > 5 mA sustained, `EN_UVLO` ≥ 1.2 V, any gate ≥ 0.1 V, `STATUS_BYTE` unreadable |
| FP4 | Isolated bench PV at **6.5 V / 200 mA** (confirmed) | Resistive preload: two 100 Ω / 10 W resistors in series (200 Ω / 20 W combined), sized against confirmed 12.83 V setpoint, see Section 11.1 | SW overshoot > 32 V, off-gate > 1.5 V, bootstrap collapse, current limit, thermal limits, COM5/SWD dropout, run time > 30 s |
| FP3 (post-FP4) | Isolated bench PV at **6.5 V / 20 mA**, with `EN_UVLO` held low (Section 12) | Open | Input current > 10 mA sustained, any gate ≥ 0.1 V, any SW-node movement, HB-SW > 6 V |

Universal aborts (all stages): source current limiting, unexpected current rise, rail collapse, heating, odor, smoke, unstable reset, unexpected gate voltage, any active control output, or any reading that contradicts this plan's expectations.

### 11.1 FP4 Preload Sizing (Resolved 2026-09-04)

**VOUT setpoint confirmed by hardware analysis, no register access needed.** Corrected finding: `FB_INT` (U6 pin 14, `FB/SEL_intFB`) is **not** floating — netlist net `_OUTPUT Feedback` shows it fed by an external resistor divider: `R3` = 66.5 kΩ from `V_out` (the converter's raw output node, same copper as `CHG_OUT_POS` through F2) to `FB_INT`, and `R25` = 5.62 kΩ from `FB_INT` to `PWR_NEG`. The LM51772-Q1 datasheet confirms this is the documented external-feedback mode (internal feedback would instead require tying this pin to `VCC2`, which is not done here) and specifies the feedback reference as `V(REF) = 1.00 V ±10 mV`.

Calculated setpoint: V_out = V(REF) × (1 + R3/R25) = 1.00 V × (1 + 66.5k/5.62k) ≈ **12.83 V**. This matches the 12.8 V WEBENCH design point almost exactly and supersedes the earlier 12.8-14.6 V planning band — treat **12.83 V** as the confirmed FP4 target, not an assumption.

Local pypdf extraction of `docs/lm51772-datasheet.pdf` (TI's web document-viewer remained unreadable via available tools after repeated attempts — do not retry that path) also decoded **Table 7-5 "CFG2 Pin (R2D-CH2) Configuration Overview"**: the fitted `CFG2` strap (R29 = 20.5 kΩ, row 13 of 16) sets `EN_SYNC_OUT=DISABLED`, `SYNC_IN_FALLING=DISABLED`, `VDET_EN=ENABLED`, `PCM_EN=ENABLED` (~30% window). `VDET_EN` adds a second internal input-voltage detector alongside the external `EN_UVLO` divider. `PCM_EN` creates an input-voltage pass-through window centered near the 12.83 V output target (input ≈ output, both high-side FETs on, no real switching) — since FP2/FP4 operate at 5.0-6.5 V input, well below that ~9-16.6 V window, PCM pass-through is not expected to engage during this plan's bounded tests; it only becomes relevant for later normal-PV-voltage charging characterization. Cross-check: this same decode method correctly reproduced the already-confirmed `R33 = 0 Ω → I2C enabled at 0x6A` result from Table 7-4, validating the row/column decode.

Bounded calculation for preload sizing at the confirmed 12.83 V setpoint, using the FP4 source limit (6.5 V / 200 mA, so P_in ≈ 1.3 W) and an assumed 85% conversion efficiency:

| V_out (confirmed) | Natural I_out = V_out / R | R = 200 Ω → I_out | P per 100 Ω resistor | Required P_in / I_in at 6.5 V |
|---|---|---|---|---|
| 12.83 V | V_out / R | ≈ 64 mA | ≈ 0.41 W | ≈ 0.97 W / ≈ 149 mA |

**Selected part (confirmed on hand): two 100 Ω / 10 W resistors in series = 200 Ω / 20 W combined rating.** At 200 Ω the natural, voltage-regulated output current (≈64 mA) requires only ≈149 mA of input current — comfortably under the 200 mA limit (≈26% margin) — so the converter is expected to reach real closed-loop regulation at its actual 12.83 V target rather than sit input-current-limited. Per-resistor dissipation (≈0.4 W) is roughly 25x under each resistor's 10 W rating. This closes the preload-sizing open item; no further register read is required before FP4.

## 12. FP3 EN_UVLO Hold-Low Provision (Now Post-FP4, Section 1a)

FP3 exists to prove the populated board's static rails above UVLO without permitting switching. Per the 2026-09-04 reorder, it is performed after FP4 passes rather than before it, as a follow-on static characterization rather than a pre-switching gate. Method: a documented, photographed temporary jumper pulling the `EN_UVLO` node to `PGND` **installed and verified unpowered** before the source is raised past 5.5 V, and removed only after the source is off and rails are discharged. If review rejects grounding `EN_UVLO` (e.g., divider loading concern), FP3 is dropped entirely rather than folded into FP4, since FP4 no longer depends on it. Rationale: with M1-M4 installed, "above-UVLO static" does not otherwise exist — U6 will attempt startup.

Note: the historical `IOUT` latch (`STATUS_BYTE=0x58`) was associated with UVLO crossing while the bridge was absent. FP4 (and FP3, if performed) must re-read `STATUS_BYTE` and record it; a latched fault with the populated bridge is new information, not a repeat, and is a stop-and-review event. It is not a justification to write `CLEAR_FAULTS`.

## 13. Item 11 - FP0 Pre-Power Rechecks and Evidence

Repeat, unpowered and discharged, immediately before FP1 (not reusing 2026-09-04 results if any rework has occurred since):

1. `PV_IN_POS` to `PWR_NEG`, output rail to `PWR_NEG`, `SW_1` to `SW_2`: no near-short; record stabilized values.
2. Gate-to-source at all four devices; body-diode direction and reverse blocking after gate discharge.
3. `HB1`-`SW_1` / `HB2`-`SW_2` bootstrap checks (Section 7).
4. Confirm F1 jumper, U2/U5 bypasses, and the PGND jumper are intact and photograph them.
5. Confirm R28 = 51.7 kΩ node, R29 = 20.5 kΩ node, R33 = 0 Ω are undisturbed (visual + resistance at the U6 pins).
6. Photograph both board sides; file with the bench record.

Evidence capture per stage: source model/voltage/current-limit setting, meter readings named per net, `status` output text, `STATUS_BYTE` value with timestamp, thermal log, photos of any temporary jumper, and an explicit pass/fail line signed in the bench record.
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

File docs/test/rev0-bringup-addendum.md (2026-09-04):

# Solar Project 200W - Rev 0 Bring-Up Addendum

Last updated: 2026-08-24
Applies to: as-manufactured Rev 0 board
Authoritative source: `C:\Users\forch\OneDrive\JLCPCB files\Solar Charger\Solar Project Rev0 - Manufactured First Build`

Use this addendum with the general safety practices in `bringup-checklist.md`. It overrides any general-plan step that assumes a complete switching bridge.

## Board Limitation

M1, M2, M3, and M4 were originally left unfitted because the available devices did not match the intended `IPZ40N` package. On 2026-09-04, the replacement lot was positively identified as ten Infineon `BSC030N04NSGATMA1` devices. Infineon specifies `PG-TDSON-8-1` / SuperSO8 5x6, which matches the manufactured Rev 0 land pattern and its pads 1-3 source, pad 4 gate, and exposed drain mapping. The replacement is approved for controlled unpowered installation under `rev0-m1-m4-installation-plan-2026-09-04.md`; it is not yet approved for power or switching. The Rev 0 schematic places these MOSFETs on the two gate-drive pairs `HO1`/`LO1` and `HO2`/`LO2`.

Consequences:

- The inverter bridge is incomplete and must be treated as nonfunctional.
- Do not apply battery power, DC-link power, or any source intended to energize the inverter bridge.
- Do not connect an AC load, transformer, or inverter output.
- Do not attempt open-loop, closed-loop, or software-controlled inverter switching.
- Do not fit any other substitute MOSFET with flying leads or improvised adapters. Only the documented `BSC030N04NSGATMA1` substitution is approved, and only under the installation plan.

This limitation does not, by itself, prove that the separate charger/control sections are unusable. Their tests remain separately gated by fitted parts, schematic review, and controlled source/sink capability.

## Permitted Rev 0 Bench Scope

| Test area | Status | Conditions |
|---|---|---|
| Visual inspection and passive continuity | Allowed | Record M1-M4 as deliberately unpopulated; inspect empty pads for bridges or contamination. |
| USB/`VBUS` control-power bring-up | Allowed | Use an isolated, current-limited bench supply through the intended USB/`VBUS` path. PV, battery, and inverter connections remain open. |
| `CTRL_3V3`, MCU, SWD, serial, buttons, display, I2C, fan-control logic | Allowed | Firmware must default all power-stage commands inactive. Test a peripheral at a time. |
| Fault and measurement signal readout | Allowed | Use low-energy stimulus only; do not defeat hardware pullups, comparators, or protection paths. |
| Gate-drive logic observation | Conditionally allowed | Keep inverter energy inputs disconnected. Before enabling a drive signal, verify the gate-driver supply/enable requirements and use a scope-only test mode. No attempt may energize the incomplete bridge. |
| Charger static-path checks | Conditionally allowed | Use only a current-limited source and a controlled output sink/simulator after confirming the actual fitted charger power parts and protection path. PWM remains inactive. |
| Charger switching | Blocked pending review | Requires a separate entry checklist that identifies the fitted charger MOSFETs, gate driver/controller, inductor, diode/synchronous path, current sense, output capacitors, source/sink ratings, and safe firmware limits. M1-M4 absence does not authorize or prohibit this test by itself. |
| Battery charging or real PV input | Blocked | No real battery or panel until the charger-specific checklist passes and BMS/panel limits are recorded. |
| Inverter / AC operation | Blocked | Requires a complete, reviewed M1-M4 bridge and a separate AC hazard procedure. |

## Rev 0 Test Sequence

### R0-A - Unpowered Inspection

1. Photograph both board sides and record the assembly revision.
2. Mark M1-M4 as deliberately unpopulated in the bench record. Confirm all four footprints are clean, with no solder bridges across pads.
3. Check for shorts from `VBUS` and `CTRL_3V3` to `PWR_NEG`; record stabilized resistance readings.
4. Check `HO1`, `LO1`, `HO2`, and `LO2` for an unintended short to a supply or return. Do not infer a normal resistance without the gate-driver schematic and fitted-part data.
5. Verify connector polarity, fuse values, polarized capacitors, TVS devices, and the USB protection path against the Rev 0 schematic and fitted BOM.

**Stop:** any power-to-return near-short, damaged empty MOSFET pad, reversed polarized part, or unknown fitted substitution.

### R0-B - Low-Voltage Control Bring-Up

1. Disconnect PV, battery, charger output load, inverter wiring, and AC wiring.
2. Set the isolated bench supply to 0 V and enable a conservative current limit. Record the limit before connecting it to the intended `VBUS`/USB power entry.
3. Raise the source only to the designed USB-equivalent input voltage. Record source voltage/current and `CTRL_3V3`.
4. Stop immediately for current limiting, voltage collapse, unexpected heating, or a control rail outside the actual regulator tolerance.
5. Program and attach to the STM32 through SWD. Confirm reset, serial logging, and that all PWM/inverter enable outputs stay inactive after boot and reset.
6. Test low-energy peripherals one at a time: button input, display/I2C activity, and fan-control logic with a suitable low-power test load.

### R0-C - Measurement and Safe-State Verification

1. Apply only low-energy, bounded stimulus to measurement inputs using a documented divider, calibrator, or simulator.
2. Verify reported values, `FAULT_OCP`, `FAULT_OVP`, and the safe firmware response without creating a power-stage demand.
3. Capture control outputs after reset, normal idle, and an injected low-energy fault. All inverter-drive commands must remain disabled while M1-M4 are absent.

### R0-D - Optional Charger Review Gate

Do not attempt this stage until a reviewer documents that the charger power path is electrically independent of M1-M4 and identifies every fitted switching/current-carrying component in that path. The reviewer must also define the specific source voltage/current limits, output sink, firmware image, scope method, stop thresholds, and evidence required.

## Required Bench Record

| Item | Record |
|---|---|
| Board identifier and photographs |  |
| M1-M4 status | `BSC030N04NSGATMA1` approved for installation; record each fitted position and passive result |
| Bench supply model, voltage, and current limit |  |
| `VBUS` and `CTRL_3V3` readings |  |
| Firmware revision and SWD result |  |
| Safe-state observation after boot/reset/fault |  |
| Peripheral and telemetry results |  |
| Charger review-gate decision | Pass / Fail / Not attempted |
| Inverter/AC status | Blocked |

## Closeout

Retain the original M1-M4 footprint-selection failure as a Rev 0 traceability item. The verified `BSC030N04NSGATMA1` substitution resolves physical fitment for this recovered board but does not clear the switching or inverter/AC block. Those blocks require successful passive installation checks and separate reviewed power-stage test plans.

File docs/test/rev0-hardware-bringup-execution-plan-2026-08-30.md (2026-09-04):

# Rev 0 Hardware Bring-Up Execution Plan - 2026-08-30

Status: bench execution plan
Board: recovered Rev 0 with fitted STM32G47x-class MCU
Priority: prove hardware paths and fitted devices; firmware is only test stimulus and observation

Progress update 2026-08-31: H1 USB hardware repair, enumeration, and UART pass. D3 was wired incorrectly and solder bridges were found at the USB connector. After correction, the onboard CP210x enumerates as `COM5` and returns the expected firmware command response at 115200 8N1. H2 passes 5/5 cold-power cycles and 5/5 reset-button cycles after correcting the stage-1 Thumb reset vector and changing `nSWBOOT0` from `1` to `0` so the existing `nBOOT0=1` option bit forces user-flash boot.

## 1. Objective and Order

Execute one stage at a time and record evidence before advancing:

1. Repair or bypass the onboard USB-to-UART debug path.
2. Make normal reset boot user flash reliably.
3. Perform the minimum static U6 power check needed to establish `U6_VCC2`.
4. Prove D8 power, DIN waveform, and visible heartbeat.
5. Prove the shared software-I2C bus electrically.
6. Identify and read U7/AHT20.
7. Identify and exercise U8/SSD1306 OLED.
8. Close the session in a known safe state.

The U6 static check must precede D8 because D8 VDD is connected to `U6_VCC2`; D8 is not powered from `CTRL_3V3`. This plan does not authorize U6 gate-drive or converter switching.

## 2. Fixed Hardware Facts

| Item | Rev 0 implementation |
|---|---|
| Verified SWD probe | ST-LINK serial `B55B5A1A0000000020AFF501` |
| Verified MCU response | Device ID `0x469`, STM32G47x/G48x/G414, approximately 3.23-3.24 V |
| UART | USART1, 115200 8N1; STM32 `PA9` TX to U3 RXD, STM32 `PA10` RX from U3 TXD |
| USB bridge | U3 CP2102; USB-C data path crosses D3/USBLC6-2SC6 |
| Reset boot issue | `PB8/BOOT0` floats and caused reset into system memory; Rev 0 now uses `nSWBOOT0=0`, `nBOOT0=1` |
| D8 | WS2812B-compatible 1615 RGB LED; `PB2 -> DIN`; VDD is `U6_VCC2`; GND is `PWR_NEG` |
| Software I2C | STM32 `PB6 = I2C DATA/SDA`; `PB7 = I2C CLK/SCL` |
| I2C devices | U6 LM51772 configuration interface, U7 AHT20, U8 0.96-inch SSD1306 OLED |
| U7 power | `CTRL_3V3` and `PWR_NEG` |
| U8 power | `CTRL_3V3` and `PWR_NEG` |
| U6 fault | `U6_FLT`, pulled up by R34 and intended to land at STM32 `PC13` |

The STM32 hardware I2C peripheral cannot be used with the routed pin assignment. All Rev 0 I2C tests use open-drain software I2C on PB6/PB7.

## 3. Non-Negotiable Limits

- Keep the real PV panels, battery, charger output, inverter, AC wiring, and loads disconnected.
- M1-M4 are unpopulated. Do not attempt inverter or bridge operation.
- Keep `PA8/CTRL_PWM_MAIN`, `PB5/CTRL_EN_CHG`, and `PA5/V_in_ON` low.
- Never configure `PB11` as an output; it is tied to `PWR_NEG` on Rev 0.
- Do not probe U6 switch nodes, command gate drive, or pulse PWM in this plan.
- Use one power source at a time unless a step explicitly defines otherwise.
- Before every flash, verify all of the following and stop on any mismatch:
  - ST-LINK serial `B55B5A1A0000000020AFF501`
  - Device ID `0x469`
  - STM32G47x/G48x/G414-class target
  - target voltage in the expected approximately 3.2-3.3 V range
- Do not select another COM port because it appears available. Identify the connected adapter by USB identity and connection change.
- Stop immediately for current limiting, rail collapse, unexpected heating, odor, unstable reset, unexplained fault state, or any control output going active.

## 4. Equipment and Pre-Session Record

| Item | Setting or record |
|---|---|
| Board identifier / photos |  |
| Isolated current-limited supply | Model: ___; initial current limit: ___ |
| DMM | Model: ___ |
| Oscilloscope / logic analyzer | Model: ___; probe ground verified at `PWR_NEG` |
| SWD probe | Expected serial recorded above |
| USB cable | Known data-capable cable: Pass / Fail |
| External 3.3 V USB-UART adapter | Model and USB identity: ___ |
| Firmware build/hash |  |
| Evidence directory | `evidence/2026-08-30-rev0-board___/` |

Before power, confirm and record:

- [ ] PV disconnected.
- [ ] Battery disconnected.
- [ ] Charger output disconnected.
- [ ] Inverter and AC wiring disconnected.
- [ ] No load connected.
- [ ] `VBUS` to `PWR_NEG` is not a near-short: ___ ohm.
- [ ] `CTRL_3V3` to `PWR_NEG` is not a near-short: ___ ohm.
- [ ] U3, D3, D8, U6, U7, and U8 have no visible bridge, wrong orientation, or damaged joint.

## 5. Stage H0 - Establish Safe Idle

1. Apply the intended USB/VBUS-equivalent control power through a current-limited source.
2. Record source voltage, source current, `VBUS`, and `CTRL_3V3`.
3. Run `firmware/scripts/rev0-openocd-identify.ps1`.
4. Confirm the expected probe, device ID, target family, and voltage.
5. Run `firmware/scripts/rev0-openocd-safe-idle.ps1`.
6. Scope or measure `PA8`, `PB5`, and `PA5`; each must be low.

Pass:

- Stable control rails, no abnormal heating, expected SWD identity, and all three control outputs low.

Record: `VBUS` ___ V; `CTRL_3V3` ___ V; source current ___ mA; result ___

## 6. Stage H1 - USB Debug Port Diagnosis and Repair

### H1.1 Unpowered data-path checks

Remove all power and cables before continuity measurements.

1. Verify the fitted D3 package marking and physical pin-1 orientation against the exact USBLC6-2SC6 datasheet and PCB footprint.
2. Measure end-to-end continuity:
   - J5 USB-C D+ contact group to U3 CP2102 pin 4/D+.
   - J5 USB-C D- contact group to U3 CP2102 pin 5/D-.
3. Measure each segment on both paths across D3 to locate an open or footprint/pin-map mismatch.
4. Check D+ to D-, D+ to ground, and D- to ground for an unintended short.

Do not install a jumper until D3 pin numbering, connector-side nets, and U3-side nets have been physically identified. A wrong jumper can short or swap the USB pair.

Record:

| Check | Reading / result |
|---|---|
| J5 D+ to U3 pin 4 |  |
| J5 D- to U3 pin 5 |  |
| D+ to D- |  |
| D+ to `PWR_NEG` |  |
| D- to `PWR_NEG` |  |
| D3 marking and pin-1 orientation |  |

### H1.2 Powered U3 checks

1. Restore current-limited VBUS power.
2. Measure U3 `REGIN`/pin 7 and `VBUS`/pin 8; both should reflect USB VBUS as designed.
3. Measure U3 `VDD`/pin 6; record the actual regulated value.
4. Check U3 temperature for abnormal heating.
5. Run `firmware/scripts/windows-list-serial-usb.ps1` before and after connecting the board with the known data cable.

### H1.3 Repair decision

- If U3 power is wrong, repair the U3 supply/ground path before touching D+/D-.
- If U3 power is correct and one or both data paths are open at D3, document and implement only the smallest verified rework that restores straight-through D+ and D- while retaining or deliberately bypassing D3.
- If D+/D- are swapped, correct both paths as a pair.
- If continuity and power pass but enumeration fails, inspect signal-path soldering and test with the same known host/cable before considering U3 replacement.
- If onboard repair is not reliable today, use the identified external 3.3 V USB-UART adapter: adapter RX to STM32 `PA9`, adapter TX to STM32 `PA10`, and adapter GND to `PWR_NEG`. Do not connect the adapter power pin.

Pass:

- A uniquely identified CP2102 or external adapter appears when connected and disappears when removed.
- At 115200 8N1, STM32 TX is visible and a received character can reach STM32 RX.
- The selected debug path is recorded; no COM-port guessing is used.

Selected debug path: onboard U3 / external adapter
USB identity: Silicon Labs CP210x, `USB\VID_10C4&PID_EA60\0001`, status `OK`
COM port after identity check: `COM5`
Repair details and photos: D3 wiring corrected and USB connector solder bridges removed; photos: ___

H1 status 2026-08-31: Pass. After the H2 startup correction, `COM5` returned the complete expected help response to `?` at 115200 8N1. A `status` command returned `OCP=1 OVP=0 PA8_PWM=0 PB5_EN=0 PA5_LEGACY=0`. The three power-control outputs are safely low; the observed fault-input states must be explained before any later power-stage test.

## 7. Stage H2 - Normal Reset / BOOT0

1. With firmware already verified in flash, measure `PB8/BOOT0` at idle and during reset.
2. If it is not reliably low, power down and fit a documented temporary pulldown suitable for the BOOT0 input.
3. Power up, press reset, and observe the UART banner or SWD SRAM heartbeat without manually loading MSP/PC.
4. Repeat at least five power cycles and five reset-button cycles.
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

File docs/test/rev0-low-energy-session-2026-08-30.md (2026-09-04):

# Rev 0 Low-Energy Session Log - 2026-08-30

Scope: recovered Rev 0 STM32 bring-up using SWD only. No flash erase, flash write, firmware upload, PV, battery, charger output, inverter, AC wiring, or load was used.

## Target Identification

STM32CubeProgrammer read-only SWD attach succeeded after the board was attached/powered:

```text
ST-LINK SN  : B55B5A1A0000000020AFF501
ST-LINK FW  : V2J37S7
Voltage     : 3.24V
Device ID   : 0x469
Device name : STM32G47x/G48x/G414
NVM size    : 512 KBytes
Device CPU  : Cortex-M4
```

This matches the recovered Rev 0 STM32G47x-class target expectation.

Note: one CubeProgrammer `-rdu` command was run during target checking. The target was already at RDP `0xAA`; CubeProgrammer reported that option bytes were unchanged and no data was downloaded.

## Tooling

- STM32CubeProgrammer v2.23.0 is installed and working for target identification.
- GNU Arm Embedded Toolchain installation through `winget` was canceled on the Windows side, so no local firmware build was attempted.
- xPack OpenOCD v0.12.0-7 was installed through `winget` and used for volatile SWD register access.
- Portable xPack ARM GCC was later downloaded under the ignored local `.tools/` directory. The bare-metal stage-1 firmware built successfully.

## Safety Gate

User confirmed before GPIO control tests: PV, battery, charger output, inverter/AC wiring, and loads were disconnected. Only low-energy control power/debug/test connections were in scope.
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

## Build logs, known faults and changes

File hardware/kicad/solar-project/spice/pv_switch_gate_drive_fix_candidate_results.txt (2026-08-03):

PV switch gate-drive candidate fix summary
========================================
Model: PMOS Q4 pass element with Q2 pull-down control and 12V Vgs clamp

OFF state (V_in_ON = 0 V):
- VIN=12 V -> V(gate)=12.000000 V, V(source)=12.000000 V, Vgs=-0.000001 V, Vout=0.000000 V
- VIN=24 V -> V(gate)=24.000000 V, V(source)=24.000000 V, Vgs=-0.000002 V, Vout=0.000000 V
- VIN=36 V -> V(gate)=36.738080 V, V(source)=36.000000 V, Vgs=0.738077 V, Vout=0.000000 V
- VIN=50 V -> V(gate)=50.738080 V, V(source)=50.000000 V, Vgs=0.738077 V, Vout=0.000000 V

ON state (V_in_ON = 3.3 V):
- VIN=12 V -> V(gate)=0.128232 V, V(source)=12.000000 V, Vgs=-11.871800 V, Vout=11.576870 V
- VIN=24 V -> V(gate)=12.006720 V, V(source)=24.000000 V, Vgs=-11.993300 V, Vout=23.145300 V
- VIN=36 V -> V(gate)=23.949230 V, V(source)=36.000000 V, Vgs=-12.050800 V, Vout=34.694760 V
- VIN=50 V -> V(gate)=37.914670 V, V(source)=50.000000 V, Vgs=-12.085300 V, Vout=48.138970 V

Conclusion:
This candidate topology establishes meaningful Vgs behavior: OFF keeps Vgs near 0 V, and ON drives Vgs negative with zener-limited magnitude at higher VIN.

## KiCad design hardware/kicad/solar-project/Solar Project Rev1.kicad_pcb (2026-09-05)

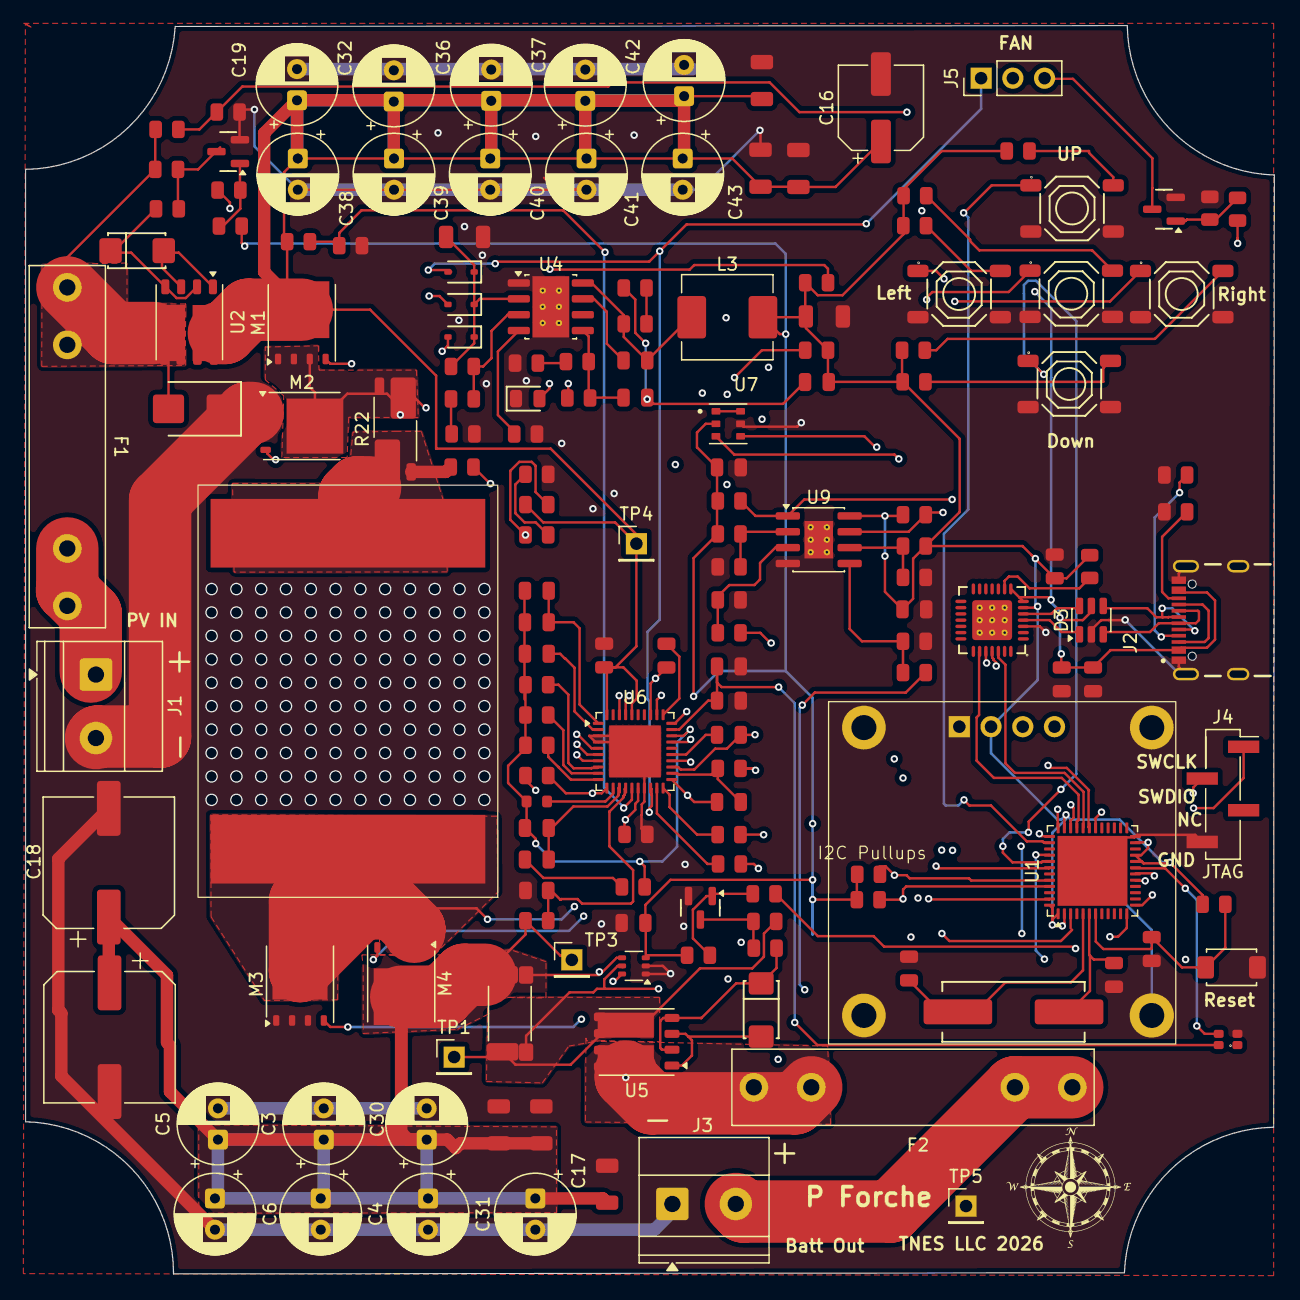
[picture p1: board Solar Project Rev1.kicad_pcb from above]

Board: 4 copper layers, 100.0 x 99.9 mm, 163 parts (1 on the bottom side), 103 nets.

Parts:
10mm1, 10mm2: 10mm LOGO
C1, C12, C22, C28, C44, C45, C46, C47, C48, C51: 100nF; C_0805
C2: 1uF; C_0805
C3, C4, C5, C6, C17, C19, C30, C31, C32, C36, C37, C38, C39, C40, C41, C42, C43: 47uf; CP_Radial_D6.3mm_P2.50mm
C7, C8, C11, C15, C33, C34, C35: 2.2uF; C_1206
C9, C13: 2.2nF; C_0805
C10: 47pF; C_0805
C14: 100uF; C_1206
C16: 10uf; CP_Elec_6.3x7.7
C18, C21: 560uf; CP_Elec_10x12.6
C20: 180pf; C_0805
C23: 100nf; C_0805
C24: 220nf; C_0805
C25: 1.5nf; C_0805
C26: 33nf; C_0805
C27, C29: 22uF; C_0805
C49, C50: 33pF; C_0805
D1, D5: 1SMA4742A; D_DO-214AC(SMA)
D2: SMBJ60CA; D_SMB
D3: USBLC6-2SC6; SOT-23-6
D4, D6, D7: 1N5819WS; D_SOD-323
D8: WS2812B; LED-SMD_4P-L1.6-W1.5_XL-1615RGBC-WS2812B
D9: Yellow; D_0805
F1: Fuse_TD_10A_5x25_63VDC_MIN; Fuseholder_Littelfuse_100_series_5x25mm
F2: Fuse; Fuseholder_Littelfuse_100_series_5x25mm
J1: Solar In; TerminalBlock_Phoenix_MKDS-1,5-2-5.08_1x02_P5.08mm_Horizont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
J2: USB4105-GF-A; GCT_USB4105-GF-A
J3: Battery Bus; TerminalBlock_Phoenix_MKDS-1,5-2-5.08_1x02_P5.08mm_Horizont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
J4: JTAG; PinHeader_1x04_P2.54mm_Vertical_SMD_Pin1Right
J5: Fan; PinHeader_1x03_P2.54mm_Vertical
L2: 1uh; HC3-1R0-R
L3: 68uh; L_KOHERelec_MDA7030
M1, M2, M3, M4: IPZ40N; TDSON-8-1
Q1, Q2: BSS138; Q_SOT-23
Q3: AO3400A; Q_SOT-23
R1, R32, R37, R38, R40, R43: 100kΩ; R_0805
R2, R4, R26, R27, R39, R41, R42: 10Ω; R_0805
R3, R18: 66.5k; R_0805
R5, R44, R45: 4.7kΩ; R_0805
R6, R10: 22kΩ; R_0805
R7: 430k; R_0805
R8: 27kΩ; R_0805
R9: 180k; R_0805
R11: 240k; R_0805
R12: 6.8kΩ; R_0805
R13: 1MΩ; R_0805
R14: 330kΩ; R_0805
R15: 2kΩ; R_0805
R16: 0.001ohms; R_2512 Shunt 4 pad resistor
R17, R25: 5.62k; R_0805
R19, R34, R36, R47, R48, R50, R53, R54, R55, R56, R57, R58, R59: 10kΩ; R_0805
R20: 499kΩ; R_0805
R21: 102k; R_0805
R22: 0.001ohms; R_Shunt_Vishay_WSK2512_6332Metric_T2.66mm
R23: 75kΩ; R_0805
R24, R62: 5.1kΩ; R_0805
R28: 51.7k; R_0603
R29: 20.5k; R_0805
R30: 40.2k; R_0805
R31: 2.43K; R_0805
R33: 6.49k; R_0805
R35: 180kΩ; R_0805
R46: 330Ω; R_0805
R49, R63, R64: 0Ω; R_0805
R51: 2.7kΩ; R_0805
R52: 1kΩ; R_0805
R60: 1.5kΩ; R_0805
R61: 20kΩ; R_0805
S1: Tactile Button, 160gf; SW_TS-1088-AR02016
SW1, SW2, SW3, SW4, SW5: Tactile Button, 160gf; SW-SMD_4P-L5.1-W5.1-P3.70-LS6.5-TL-2
TP1, TP3, TP4, TP5: TestPoint_Small; PinHeader_1x01_P2.54mm_Vertical
U1: STM32F411CEU6; QFN-48-1EP_7x7mm_P0.5mm_EP5.6x5.6mm
U2: BSC112N06LD; Infineon_PG-TDSON-8
U3: CP2102-GMR; WQFN-28_L5.0-W5.0-P0.50-BL-EP3.2
U4: LM5163DDAR; Texas_R-PDSO-G8_EP2.95x4.9mm_Mask2.4x3.1mm_ThermalVias
U5: BSC155N06ND; Infineon_PG-TDSON-8
U6: LM51772QRHARQ1; Texas_RHA0040B_VQFN-40-1EP_6x6mm_P0.5mm_EP4.15x4.15mm
U7: AHT20; Humidity sensor
U8: 0.96 inOLED display SSD1306
U9: LMV393; SOIC-8-1EP_3.9x4.9mm_P1.27mm_EP2.29x3mm_ThermalVias
U10: INA213AIDCKR; SOT-363_SC-70-6
X2: X49SM8MSD2SC; CRYSTAL-SMD_L11.5-W4.8-LS12.7

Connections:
/PV_IN_POS_FUSED: D2.2, F1.1, R35.1, R43.1, U2.5 (D1)
/PV_IN_POS_RAW: F1.2, J1.1
BAT_BUS_POS: D4.2, F2.2, J3.2, R20.1
BTN_DN_N: SW2.1 (A), U1.41 (PB3)
BTN_ENT_N: SW5.1 (A), U1.47 (PB9)
BTN_LT_N: SW4.1 (A), U1.42 (PB4)
BTN_RT_N: SW3.1 (A), U1.3 (PC14-OSC32_IN)
BTN_UP_N: SW1.1 (A), U1.38 (PA15)
CHG_OUT_POS: D6.2, F2.1, J5.1, U5.6 (D1), U6.18 (VOUT)
CTRL_3V3: C9.1, C12.1, C14.1, C44.1, C48.1, C51.2, L3.2, R5.2, R10.2, R19.1, R21.1, R34.2, R37.1, R40.1, R44.2, R45.2, R46.1, R51.1, R53.1, R54.1, R55.1, R56.1, R57.1, R58.1, R59.1, U1.1 (VBAT), U1.20 (VREF+), U1.21 (VDDA), U1.23 (VDD), U1.35 (VDD), U1.48 (VDD), U3.6 (VDD), U6.38 (RST), U7.2 (VDD), U8.2 (VCC), U9.8 (V+), U10.3 (V+)
CTS: U1.33 (PA11), U3.23 (CTS)
FAULT_OCP: R53.2, U1.17 (PB0), U9.7
FAULT_OVP: R19.2, U1.18 (PB1), U9.1
Fan Control: R4.1, U1.40 (PC11)
HO1: M1.4 (G), U6.24 (HO1)
HO2: M4.4 (G), U6.32 (HO2)
I2C CLK: R44.1, U1.45 (PB7), U6.6 (SCL_CFG4), U7.3 (SCL), U8.3 (SLC)
I2C DATA: R45.1, U1.44 (PB6), U6.5 (SDA_CFG3), U7.4 (SDA), U8.4 (SDA)
LO1: M2.4 (G), U6.27 (LO1)
LO2: M3.4 (G), U6.30 (LO2)
unnamed: C9.2, C10.1, R12.2
unnamed: C24.1, R31.1
unnamed: D8.4 (DIN), U1.19 (PB2)
unnamed: D9.2, R46.2
unnamed: J2.A5 (CC1), R24.2
unnamed: J2.B5 (CC2), R62.2
unnamed: D3.4 (I/O2), J2.A7 (DN1), J2.B7 (DN2)
unnamed: D3.3 (I/O2), J2.A6 (DP1), J2.B6 (DP2)
unnamed: J2.A8 (SBU1), J2.B8 (SBU2)
unnamed: J5.3, Q3.3 (D)
unnamed: Q1.3 (D), R2.2, R38.2
unnamed: Q1.1 (G), R37.2, R39.2
unnamed: Q2.3 (D), R42.1, R43.2
unnamed: Q2.1 (G), R40.2, R41.2
unnamed: Q3.1 (G), R1.1, R4.2
unnamed: R7.2, R10.1
unnamed: R6.1, R11.2
unnamed: R9.1, R12.1
unnamed: R14.2, R15.1
unnamed: R60.1, R61.2
unnamed: C47.1, R59.2, S1.1 (A), U1.7 (PG10-~RST)
unnamed: R54.2, SW1.2 (B)
unnamed: R55.2, SW2.2 (B)
unnamed: R56.2, SW3.2 (B)
unnamed: R57.2, SW4.2 (B)
unnamed: R58.2, SW5.2 (B)
unnamed: C50.1, U1.5 (PF0-OSC_IN), X2.1
unnamed: C49.1, U1.6 (PF1-OSC_OUT), X2.2
unnamed: D1.1, R42.2, U2.2 (G1), U2.4 (G2)
unnamed: D1.2, U2.1 (S1), U2.3 (S2)
unnamed: D3.1 (I/O1), U3.4 (D+)
unnamed: D3.6 (I/O1), U3.5 (D-)
unnamed: R5.1, U3.9 (RST#)
unnamed: C13.2, U4.7 (BST)
unnamed: R13.2, R14.1, U4.3 (EN/UVLO)
unnamed: C10.2, R6.2, R7.1, U4.5 (FB)
unnamed: R8.1, U4.4 (RON)
unnamed: C13.1, L3.1, R9.2, U4.8 (SW)
unnamed: C15.1, D4.1, D6.1, D7.1, R13.1, U4.2 (VIN)
unnamed: D5.1, R2.1, U5.2 (G1), U5.4 (G2)
unnamed: D5.2, U5.1 (S1), U5.3 (S2)
unnamed: R33.1, U6.9 (ADDR_SLOPE_CFG1)
unnamed: R30.1, U6.10 (CDC)
unnamed: R29.1, U6.8 (CFG2)
unnamed: C24.2, C25.2, U6.13 (COMP)
unnamed: C20.1, R26.2, U6.22 (CSA)
unnamed: C20.2, R27.2, U6.21 (CSB)
unnamed: C22.1, U6.25 (HB1)
unnamed: C23.1, U6.31 (HB2)
unnamed: R32.1, U6.7 (MODE), U6.16 (ILIMCOMP_ISET)
unnamed: R63.1, U6.19 (ISNSN)
unnamed: R64.1, U6.20 (ISNSP)
unnamed: R28.1, U6.12 (RT)
unnamed: C26.2, U6.2 (SS_ATRK)
unnamed: C27.1, C46.1, U6.1 (VCC1)
unnamed: U7.1 (NC), U7.6 (NC)
OCP_MEAS: R49.1, U10.6 (OUT)
OCP_REF: R51.2, R52.1, U9.6 (-)
OCP_SENSE: R49.2, R50.1, U9.5 (+)
OVP_REF: R21.2, R48.1, U9.2 (-)
OVP_SENSE: R20.2, R47.1, U9.3 (+)
PGND: C25.1, C26.1, C27.2, C46.2, R28.2, R29.2, R30.2, R31.2, R33.2, U6.28 (PGND)
PV_IN_POS: C7.1, C8.2, C11.2, C16.1, C19.1, C28.1, C32.1, C36.1, C37.1, C38.1, C39.1, C40.1, C41.1, C42.1, C43.1, M1.5 (D), R18.1, R23.1, TP4.1, U2.6 (D1), U6.36 (VIN), U6.40 (BIAS)
PWR_NEG: C1.2, C2.2, C3.2, C4.2, C5.2, C6.2, C7.2, C8.1, C11.1, C12.2, C14.2, C15.2, C16.2, C17.2, C18.2, C19.2, C21.2, C28.2, C29.2, C30.2, C31.2, C32.2, C33.2, C34.2, C35.2, C36.2, C37.2, C38.2, C39.2, C40.2, C41.2, C42.2, C43.2, C44.2, C45.2, C47.2, C48.2, C49.2, C50.2, C51.1, D2.1, D3.2 (GND), D8.3 (GND), D9.1, J1.2, J2.A1_B12 (GND), J2.B1_A12 (GND__1), J2.SH1 (SHELL_GND), J2.SH2 (SHELL_GND__1), J2.SH3 (SHELL_GND__2), J2.SH4 (SHELL_GND__3), J3.1, J4.4, M2.1 (S), M2.2 (S), M2.3 (S), M3.1 (S), M3.2 (S), M3.3 (S), Q1.2 (S), Q2.2 (S), Q3.2 (S), R1.2, R8.2, R11.1, R15.2, R17.2, R24.1, R25.2, R32.2, R36.2, R47.2, R48.2, R50.2, R52.2, R60.2, R62.1, S1.2 (B), SW1.3 (C), SW1.4 (D), SW2.3 (C), SW2.4 (D), SW3.3 (C), SW3.4 (D), SW4.3 (C), SW4.4 (D), SW5.3 (C), SW5.4 (D), TP5.1, U1.24 (PB11), U1.49 (VSS), U3.3 (GND), U4.1 (GND), U4.9 (TH_pd), U6.3 (SYNC), U6.4 (DTRK), U6.17 (AGND), U6.41 (GND), U7.5 (GND), U8.1 (GND), U8.5 (GND), U8.6 (GND), U8.7 (GND), U8.8 (GND), U9.4 (V-), U9.9 (EP), U10.1 (REF), U10.2 (GND)
RTS: U1.34 (PA12), U3.24 (RTS)
RXD: U1.31 (PA9), U3.25 (RXD)
SWCLK: J4.1, U1.37 (PA14)
SWDIO: J4.2, U1.36 (PA13)
SW_1: C22.2, M1.1 (S), M1.2 (S), M1.3 (S), M2.5 (D), R22.3, R22.4, R26.1, U6.23 (SW1)
SW_2: C23.2, L2.2, M3.5 (D), M4.1 (S), M4.2 (S), M4.3 (S), U6.33 (SW2)
TXD: U1.32 (PA10), U3.26 (TXD)
U6_FLT: R34.1, U1.2 (PC13), U6.11 (FLT)
U6_VCC2: C29.1, C45.1, D8.2 (VDD), U6.29 (VCC2)
VBUS: C1.1, C2.1, D3.5 (VBUS), D7.2, J2.A4_B9 (VBUS), J2.B4_A9 (VBUS__1), U3.7 (REGIN), U3.8 (VBUS)
V_in_ADC: R35.2, R36.1, U1.12 (PA4)
V_in_FB: R17.1, R18.2, U6.15 (VIN-FB)
V_in_ON: R41.1, U1.13 (PA5)
V_out: C3.1, C4.1, C5.1, C6.1, C17.1, C18.1, C21.1, C30.1, C31.1, C33.1, C34.1, C35.1, M4.5 (D), R3.1, R16.3, R16.4, R64.2, TP3.1, U10.4 (IN+)
V_out _on: R39.1, U1.30 (PA8)
V_out_sense: R16.1, R16.2, R38.1, R63.2, TP1.1, U5.5 (D1), U10.5 (IN-)
_CSB_2: L2.1, R22.1, R22.2, R27.1
_OUTPUT Feedback: R3.2, R25.1, U6.14 (FB_INT)
_Undervoltage Feedback: R23.2, R61.1, U6.37 (EN_UVLO)

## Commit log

2026-07-06 init scaffold and import solar kicad sources
    [Solar Project.kicad_pcb, Solar Project.kicad_sch]
2026-07-08 Consolidate KiCad source path and log migration state
    [Solar Project.kicad_sch]
2026-07-08 Update KiCad checklist next action after path consolidation
2026-07-08 Add Sheet 3 battery interface kickoff map
2026-07-08 Temporarily clear Q1 gate ERC blocker for Rev0 progress
    [Solar Project.kicad_sch]
2026-07-09 Zone D Phase 1 complete: Add sensing and control I/O placeholders with measurement circuits, thermal sensors, and control net boundaries
    [Solar Project.kicad_sch]
2026-07-10 Lock Rev 0 controller baseline to STM32G431
2026-07-19 schematic/docs: LM51772 U6 miswire cleanup, ERC 14->7 errors
    - Fix U6 RST/SYNC/DTRK/VCC2/FLT miswires; apply Rev 0 straps
    - RST (pin 38) -> CTRL_3V3 (pull-high, normal operation)
    - SYNC (pin 3) -> PWR_NEG (free-running oscillator, Rev 0 strap)
    - DTRK (pin 4) -> PWR_NEG (tracking disabled, Rev 0 strap)
    - VCC2 (pin 29) -> U6_VCC2 placeholder (output, decoupling needed)
    - FLT (pin 11) -> U6_FLT placeholder (pull-up needed)
    - VIN/BIAS: both pins on PV_IN_POS intentional for Rev 0 simplicity
    - Normalize net labels: UART_RX_CFG, V_in_ADC (remove split-risk spaces)
    - Fix gate-drive pin_not_driven (M1-M4): change U6 HO1/LO1/HO2/LO2
    from unspecified to output type in embedded lib_symbols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
    [Solar Project.kicad_sch]
2026-07-19 schematic: wire CTRL_SUPPLY_IN - add D6/D7 OR-ing diodes, name net
    DEC-013 gap closed: U4 VIN was an unnamed auto-net with only BAT path.
    - Add D6 (1N5819WS): CHG_OUT_POS anode at (294.64,182.88) -> cathode at CTRL_SUPPLY_IN
    - Add D7 (1N5819WS): VBUS anode at (294.64,177.80) -> cathode at CTRL_SUPPLY_IN
    - Add 3 connecting wires joining D6/D7 cathodes to bus junction at (309.88,187.96)
    - Add CTRL_SUPPLY_IN global label at (320.04,187.96) naming the previously
    anonymous Net-(U4-VIN) as the documented CTRL_SUPPLY_IN boundary net
    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
    [Solar Project.kicad_sch]
2026-07-19 cleanup: revert C30/R34 temp components - maintain clean CTRL_SUPPLY_IN OR-ing wiring
    [Solar Project.kicad_sch]
2026-07-20 docs: bench-workstation handoff and schematic continuation
    [Solar Project.kicad_sch]
2026-07-20 kicad: sync schematic and cache from local recovery
    [Solar Project.kicad_sch]
2026-07-25 Clean DRC and update handoff
    [Solar Project.kicad_pcb, Solar Project.kicad_sch]
2026-07-26 Update Rev 0 hardware status and docs
    [Solar Project PreRoute save.kicad_pcb, Solar Project.kicad_pcb, Solar Project.kicad_sch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]
2026-08-03 Add SPICE harness baseline and refresh project handoffs
    [Solar Project.kicad_sch, corner_summary.csv]
2026-08-04 kicad: split Rev 0 and Rev 1 revision files
    [Solar Project Rev0.kicad_pcb, Solar Project Rev0.kicad_sch, Solar Project Rev1.kicad_pcb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]
2026-08-25 docs: Rev0 bring-up addendum, revision labeling, bench plan updates
    - Add Rev 0 bench addendum for missing M1-M4 bridge MOSFETs (footprint mismatch)
    - Rebuild Rev 1 bench bring-up plan with staged safety gates
    - Add REVISION-INDEX.md to disambiguate Rev 0 manufactured vs Rev 1 active files
    - Rename generic Solar Project.* files to explicit Rev1/dated snapshot names
    - Ignore all KiCad lock file variants (~*.lck)
    [Solar Project Rev1 - 2026-07-27 PCB Baseline.kicad_pcb, Solar Project Rev1 - 2026-08-04 Snapshot.kicad_sch, Solar Project Rev1.kicad_sch]
2026-08-26 docs: Rev0 U1 root cause, I2C swap, MCU strategy, 2026-08-26 handoff
    - DEC-018: U1 short root cause is G431 symbol routed with F411 parts fitted
    - DEC-019: Rev 0 I2C SCL/SDA swapped at MCU; use software bit-banged I2C
    - DEC-020: order 2x STM32G473CEU6 for Rev 0 recovery; Rev 1 targets F411
    - DEC-017 superseded; DEC-014 flagged as defective implementation
    - Add mandatory Part Substitution Gate to KiCad implementation checklist
    - Add SOLAR_HANDOFF_2026-08-26.md and refresh HANDOFF/NEXT_CHAT_PROMPT
2026-09-01 docs: root-cause LM51772 I2C silence to ADDR/SLOPE (CFG1) strap via R33
2026-09-01 docs: note schematic out of sync with bench rework; flag MODE/ISET net short and PGND/AGND mismatch
2026-09-01 docs: cross-check U6 config resistors against TI WEBENCH reference schematics
2026-09-02 Log MODE-pin PSM-default as tracked Rev 2 issue
2026-09-02 firmware: diagnose Rev0 U6 I2C NACK
2026-09-03 docs: record PV current-collapse observation on replacement U6
2026-09-04 docs: M1-M4 installation record, 2026-09-04 handoff, staged first-power plan draft
2026-09-05 hardware: update Rev1 PCB and July handoff
    [Solar Project Rev1.kicad_pcb]
2026-09-06 spice: add startup current limit experiment
2026-09-06 spice: model 6V to 12.83V boost startup
2026-09-08 docs: authorize controlled LM51772 I2C integration
2026-09-12 hardware: update Rev1 schematic with 0 ERC errors, BOM, and footprint tables
2026-09-12 docs: add Rev1 bench learning matrix, BOM docs, derating review, and handoffs through 2026-09-12
2026-09-17 Save local changes: snapshot of docs, KiCad Rev1, BOM and hardware files
2026-09-18 Rev1: close Track E PCB layout (routed, DRC clean, JLCPCB DFM pass), clean up duplicate LCSC schematic fields, close Track B/C docs, add fab outputs
    - DEC-064: remove 172 duplicate empty 'LCSC ' (trailing-space) properties from Solar Project Rev1.kicad_sch; ERC warnings 337 -> 171, only field_name_whitespace category changed
    - DEC-065: Track E closed - board fully routed (4-layer), DRC 0 errors/0 unconnected, JLCPCB DFM check passed; fab-ready Gerbers/drill archived under hardware/kicad/solar-project/fab-output-2026-09-18/
    - Update rev-one-closure-plan-2026-09-16.md: Track A/B/C/E status banners, Section 0 path-to-order summary, Section 3/4 sequencing refreshed
    - Update decisions-log.md thro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
2026-10-25 docs: plan assembled Rev 1 development and tracker closure
    Reference issue #1 without closing the validation tracker.
2026-10-25 docs: record Rev 1 board baseline and practical hobby workflow
    Record the user-supplied manufacturing package and photos, reconcile entry-point status, and reduce documentation requirements to the hobby scope requested by Phil.
2026-10-25 docs: prepare unpowered Rev 1 bring-up checkpoint
    Record the never-powered board and available CC/CV supply, trace the control-power entry and test points, and flag obsolete switching instructions before use.
2026-10-27 Add isolated Rev1 G473 bring-up targets
    Add inert minimal target plus separate heartbeat, I2C-scan, and UART-bootlog stage targets for STM32G473CEU6 in Solar-Project-200w, with standalone startup/linker/system files and build scripts. Upda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
2026-10-28 firmware: add Rev1 status-only bench stage
    - add stage_aht20_display_uart.c status telemetry stage for U6/AHT20/OLED/UART
    - update stage_d8_heartbeat timing/chain behavior
    - correct G473 stage linker RAM size to 96K
2026-10-28 firmware: stabilize rev1 u6 status bringup
    - add stage_aht20_display_uart to build target list
    - make ADC init/read timeout-safe to prevent boot deadlock
    - keep PA5 active-high so V_in_ON defaults enabled at boot
2026-10-31 docs: record Rev 1 bridge bench findings (IVP disabled, plateau/breakdown, dead-time plan)
2026-11-03 docs: record I2C internal-FB switch, Vin sweeps and load-test results
2026-11-03 docs: add bench findings section 7 (slope comp, PCM, I2C faults)
2026-11-04 docs: clarify I2C failure cause is unknown in TI request
2026-11-04 docs: note FB pin 14 wire jumper to VCC2 in TI request
2026-11-04 docs: fill FET and inductor parts in TI request
2026-11-06 Harden ARM sequencing and add optional IVP bench setup
2026-11-06 Rev1 U6 bring-up: fix VIN ADC, real-time START window, OC pre-clear
    VIN ADC: use ADC2 channel 17 (PA4) with CKMODE=HCLK/1; the previous ADC1 ch4 + async clock never calibrated. U6 TEST: time START/log with the DWT cycle counter (delay_ms ran several times slower than nominal, so the 1000 ms window lasted ~15 s) and skip OLED redraw during START. U6 TEST: write-1-to-clear OC/UV in STATUS_BYTE at idle before releasing PB12; drop the in-run CLEAR_FAULTS, which coincided with I2C loss. Add the 2026-11-05 handoff with findings and next steps.
2026-11-06 Handoff 2026-11-05: record no-progress results and unproven 12 V
2026-11-06 Handoff 2026-11-05: add 12 V test result and schematic/datasheet findings
2026-11-06 Handoff 2026-11-05: correct findings using the real Rev 1 PCB netlist
2026-11-06 Add U6 BOOST override and 2026-11-06 LM51772 12.8V findings
2026-11-07 docs: record current U6 ISET bench rework
2026-11-07 docs: record 22 ohm U6 gate resistor rework
2026-11-07 firmware: extend U6 TEST window to 10s
    - Increase START_TIMEOUT_MS to 10000 for longer bench capture windows\n- Update BUILD_ID to u6q5q6-10s for UART verification\n- Add 2026-11-07 Q5/Q6 switched-path retest results to bench findings\n\n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
2026-11-09 esp32-c3: add local Wi-Fi provisioning app
    - Add isolated ESP-IDF project at firmware/esp32_c3_wifi\n- Implement setup AP + web form credential capture\n- Persist credentials in NVS with bounds validation\n- Retry STA and fall back to setup AP on repeated failures\n- Add disconnect reason and pre-connect scan diagnostics\n- Add credential clear endpoint and trim form whitespace\n\nCo-authored-by: Copilot <223556219+Copilot@users.noreply.github.com>
2026-11-09 Add ESP32-C3 Wi-Fi provisioning
    Record the Q5/Q6 bench disposition and add the initial ESP-IDF provisioning application.
2026-11-09 Establish current Rev2 handoff and consolidation change register
    Replace stale entry points, preserve Rev1 production boundaries, document firmware reconciliation and existing Rev-next issues, and gate PCB work on the controller decision.
2026-11-09 Preserve Q5/Q6 one-second test firmware
    Keep the u6q5q6-1 bench variant with the jumper bypass disabled and fail-safe I2C speed handling.
2026-11-09 Record preserved bench variant and consolidation landing gates
